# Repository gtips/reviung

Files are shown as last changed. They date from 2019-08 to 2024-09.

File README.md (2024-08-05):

# REVIUNG

## [REVIUNG41](https://github.com/gtips/reviung/tree/master/reviung41)  
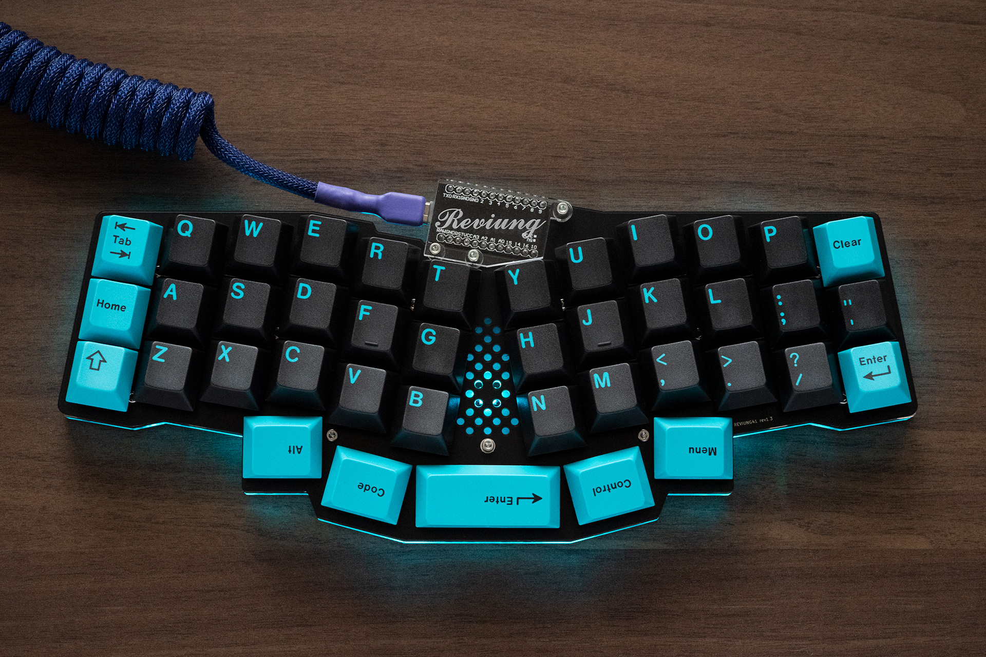
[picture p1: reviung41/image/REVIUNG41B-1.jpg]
REVIUNG41
  

The REVIUNG41 is 41-key column staggered keyboard.  

[Firmware](https://github.com/qmk/qmk_firmware/tree/master/keyboards/reviung/reviung41)  
[Build guide](https://reviung.com/build-guide/391/)  
  
<br>
<br>
  
## REVIUNG39 Mk-II, REVIUNG39 and REVIUNG39S  
The REVIUNG39 is 39-key column staggered keyboard.

Soldering is divided into through-hole mounting version and surface mounting (SMD) version so that the soldering difficulty can be selected.  

- REVIUNG39 Mk-II and REVIUNG39 is regular version (SMD)  
- REVIUNG39S is simple version (through-hole)  

[REVIUNG39 Mk-II ](https://github.com/gtips/reviung/tree/master/reviung39Mk-II)   
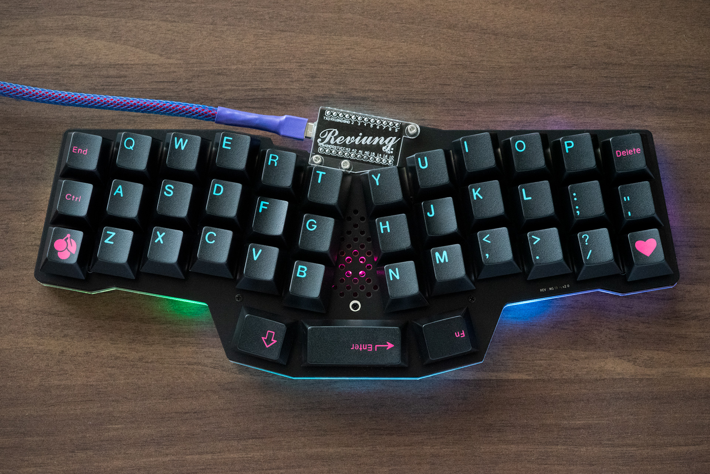
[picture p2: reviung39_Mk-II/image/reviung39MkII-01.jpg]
REVIUNG39 Mk-II
  

<br>

[REVIUNG39](https://github.com/gtips/reviung/tree/master/reviung39)  
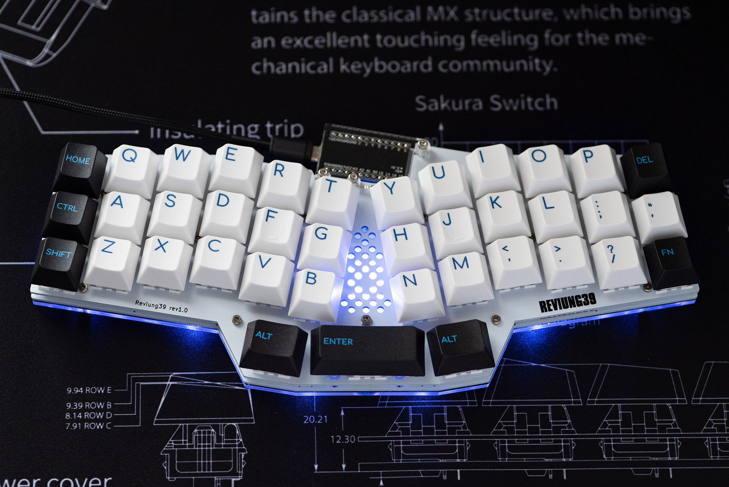
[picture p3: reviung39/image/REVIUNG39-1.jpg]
REVIUNG39
  

<br>

[REVIUNG39 Build guide](https://reviung.com/build-guide/108/)  
[Firmware](https://github.com/qmk/qmk_firmware/tree/master/keyboards/reviung/reviung39)
  
<br>
<br>

## REVIUNG34  
The REVIUNG34 is 34-key (or33-key) column staggered keyboard.  
  
[REVIUNG34](https://github.com/gtips/reviung/tree/master/reviung34)  
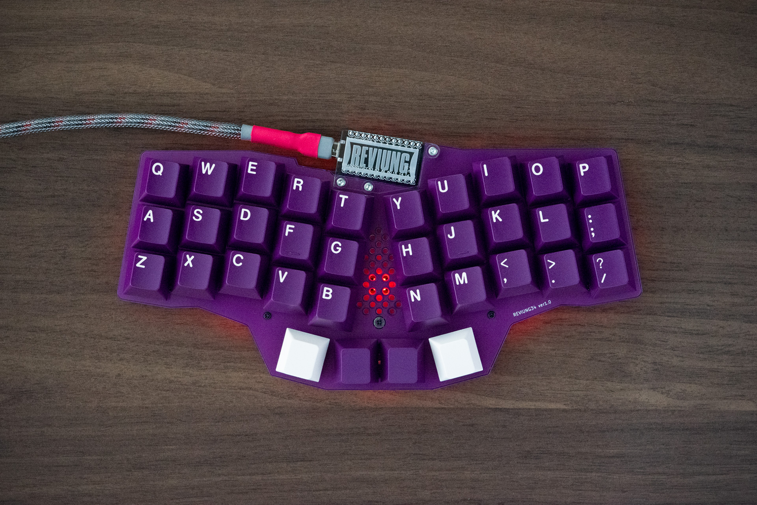
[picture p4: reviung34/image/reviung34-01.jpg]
REVIUNG34
  

<br>

[REVIUNG34 Build guide](https://reviung.com/build-guide/724/)  
[Firmware](https://github.com/qmk/qmk_firmware/tree/master/keyboards/reviung/reviung34)
  
<br>
<br>

## REVIUNG5  
The REVIUNG5 is 5-key (or 4-key + Rotary Encoder) macropad.  
  
[REVIUNG5](https://github.com/gtips/reviung/tree/master/reviung5)  
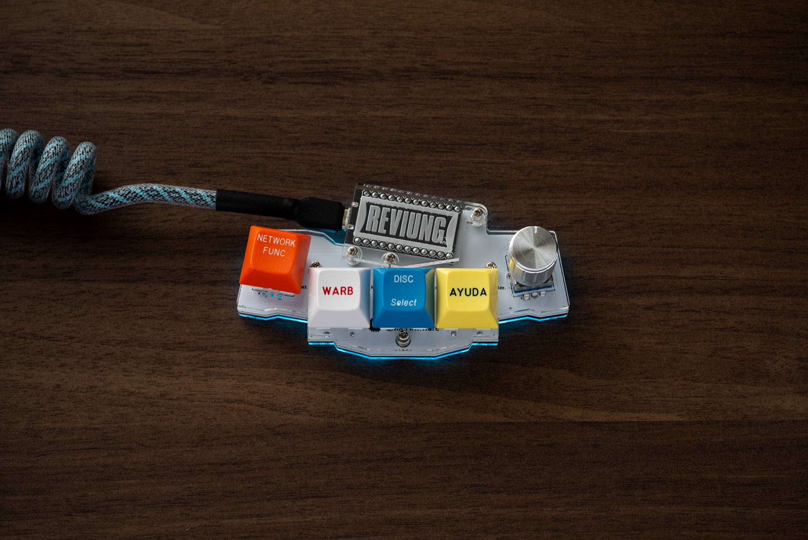
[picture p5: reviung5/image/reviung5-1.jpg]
REVIUNG5
  

<br>

[REVIUNG5 Build guide](https://reviung.com/build-guide/)  
[Firmware](https://github.com/qmk/qmk_firmware/tree/master/keyboards/reviung/reviung5)
  
<br>
<br>
  
## REVIUNG34 SPLIT Mk-II and REVIUNG34 SPLIT  

The REVIUNG34 is 34-key split ortholinear keyboard.  
(REVIUNG34 SPLIT Mk-II is 34-key or 33-key)  
Use a LAN cable to connect the left and right keyboards.  
  
[REVIUNG34 Mk-II](https://github.com/gtips/reviung/tree/master/reviung34split_Mk-II)  
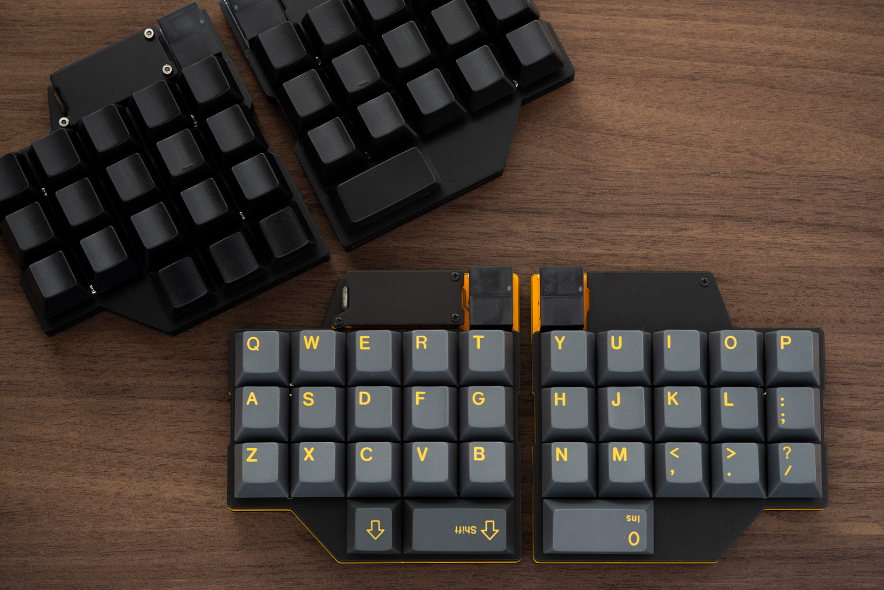
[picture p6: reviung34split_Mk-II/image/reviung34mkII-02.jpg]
REVIUNG34 Mk-II
  
  
<br>
  
[REVIUNG34 SPLIT](https://github.com/gtips/reviung/tree/master/reviung34split)  
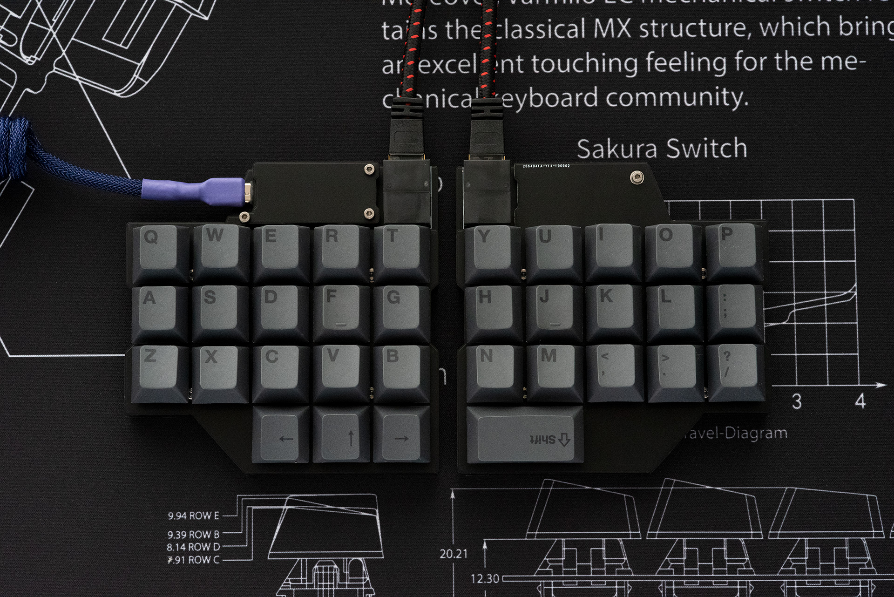
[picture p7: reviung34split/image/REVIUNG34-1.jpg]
REVIUNG34 SPLIT
  
  
[Firmware](https://github.com/qmk/qmk_firmware/tree/master/keyboards/reviung/reviung34)  
[REVIUNG34 SPLIT Build guide](https://reviung.com/build-guide/278/)  

<br>
<br>

## [REVIUNG33](https://github.com/gtips/reviung/tree/master/reviung33)  
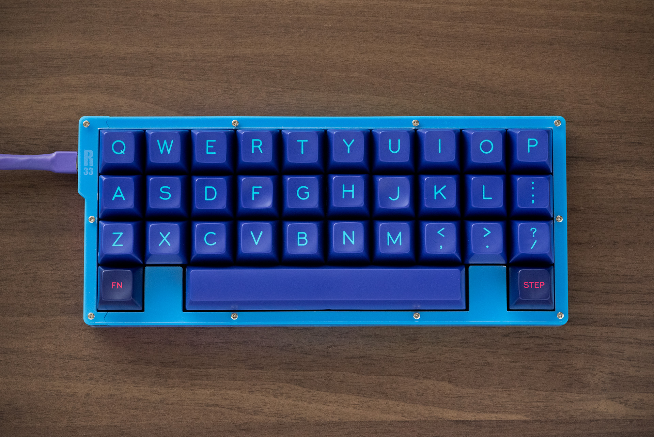
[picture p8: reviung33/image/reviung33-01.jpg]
REVIUNG33
  

The REVIUNG33 is 33-key ortholinear keyboard.  

[Firmware](https://github.com/qmk/qmk_firmware/tree/master/keyboards/reviung/reviung33)  

<br>
<br>

## [REVIUNG53](https://github.com/gtips/reviung/tree/master/reviung53)  
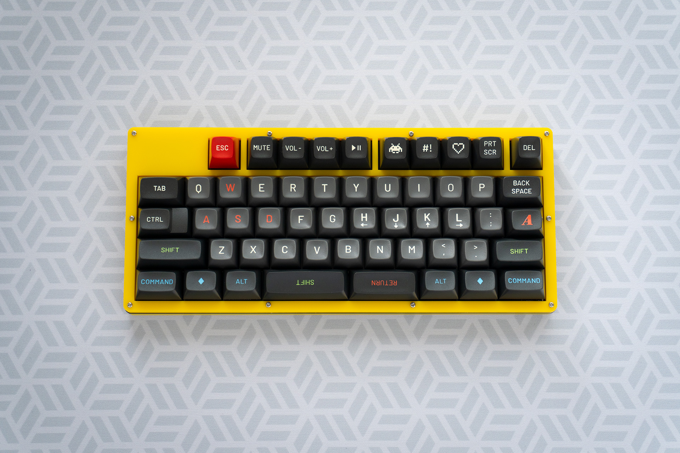
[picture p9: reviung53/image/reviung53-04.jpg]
REVIUNG53
  

The REVIUNG53 is 53-key keyboard.  

[Firmware](https://github.com/qmk/qmk_firmware/tree/master/keyboards/reviung/reviung53)  

<br>
<br>

## [REVIUNG61](https://github.com/gtips/reviung/tree/master/reviung61)  
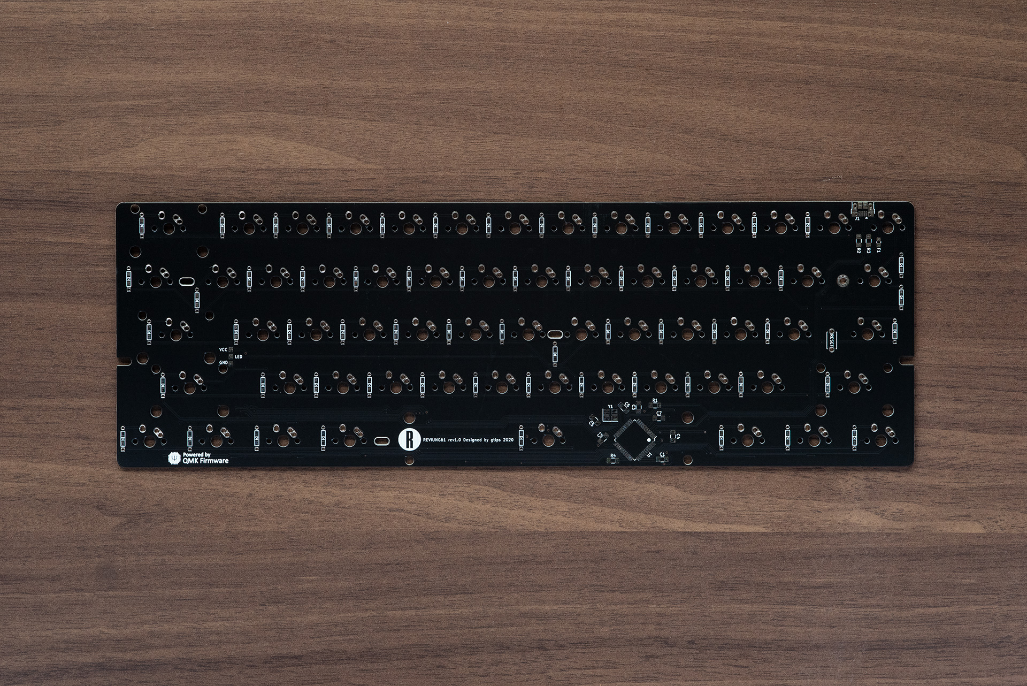
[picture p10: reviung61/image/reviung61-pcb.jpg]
REVIUNG61
  

Standard ANSI 60% keyboard. And compatible with MX and ALPS.  

[Firmware](https://github.com/qmk/qmk_firmware/tree/master/keyboards/reviung/reviung61)  

<br>
<br>

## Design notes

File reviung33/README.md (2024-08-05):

# REVIUNG33  
REVIUNG33  

The REVIUNG33 is 33-key ortholinear keyboard.  

## PCB Parts list  

| Qnty | Ref | Value | Description |
| --- | --- | --- | --- |
| 1 | U1 | ATmega32U4-AU | ATmega32U4-AU |
| 1 | Y1 | 16MHz | Crystal: SMD 3225 4Pin |
| 2 | C1, C2 | 22pF | Capacitor SMD: 1206 3216 |
| 1 | C3 | 1uF | Capacitor SMD: 1206 3216 |
| 3 | C4, C5, C6 | 0.1uF | Capacitor SMD: 1206 3216 |
| 1 | C7 | 10uF | Capacitor SMD: 1206 3216 |
| 33 | D1 - D33 | 1N4148 | Diode: 1N4148W SMD |
| 1 | F1 | 500mA | Fuse: 0805 2012 |
| 1 | J1 | MOLEX 47642-0001 | Connector USB: MOLEX 47642-0001 |
| 5 | WS2812B | WS2812B | RGB LED: WS2812B
| 2 | R1, R2 | 22 ohm | Resistor SMD:1206 3216 |
| 2 | R3, R4 | 10k ohm | Resistor SMD:1206 3216 |
| 1 | RESET1 | Tactile Switche | Tactile Switche Omron Electronics B3U-1000P |
| 33 | SW1 - SW33 | MX Hotswap Sockets | Kailh MX Hotswap Sockets |
| 32 | SW1 - SW31, SW33 | MX Switche | 1U |
| 1 | SW32 | MX Switche | 6.25U |

## Parts list  

| Qnty | Parts |
| --- | --- |
| 1 | PCB |
| 1 | Top plate [PCB]  |
| 1 | Acrylic frame (over top)  |
| 1 | Acrylic frame (top)  |
| 1 | Acrylic frame (middle) |
| 1 | Acrylic frame (bottom) |
| 1 | Acrylic plate (bottom) |
| 1 | Stabilizer 6.25U |
| 10 | Spacer 7mm |
| 10 | M2 screw 4mm |
| 10 | M2 screw  10mm |
| 6 | Rubber feet  |
| 33 | MX compatible switch | 
| 32 | Keycap (1U) | 
| 1 | Keycap (6.25U) | 
  
[Firmware](https://github.com/qmk/qmk_firmware/tree/master/keyboards/reviung/reviung33)  
[Build guide](https://reviung.com/)  
  
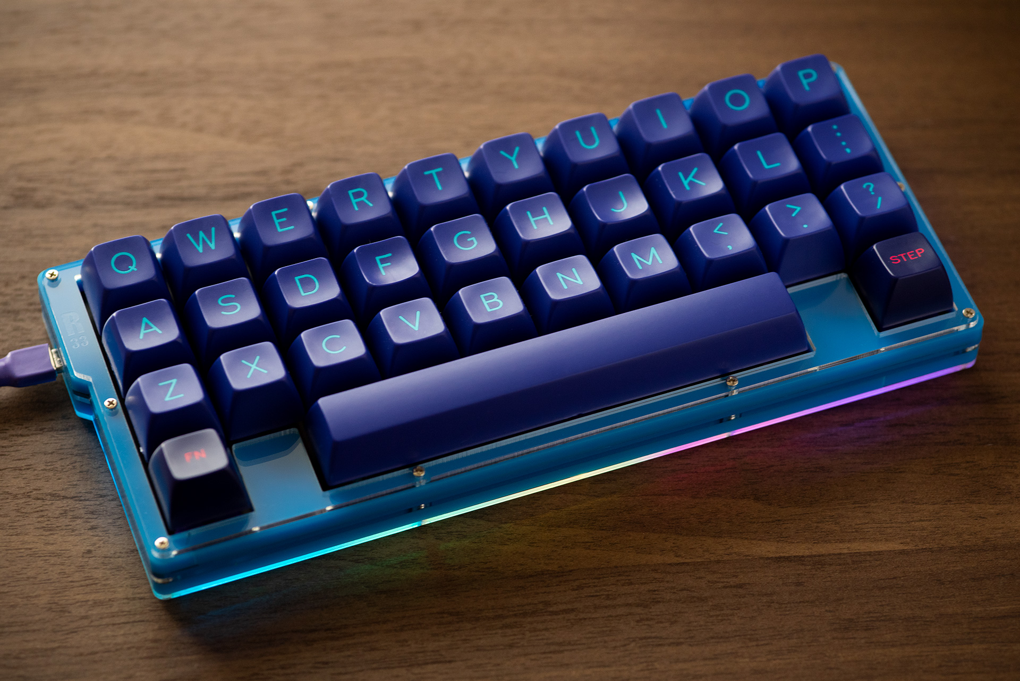
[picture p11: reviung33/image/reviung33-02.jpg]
REVIUNG33
  
  
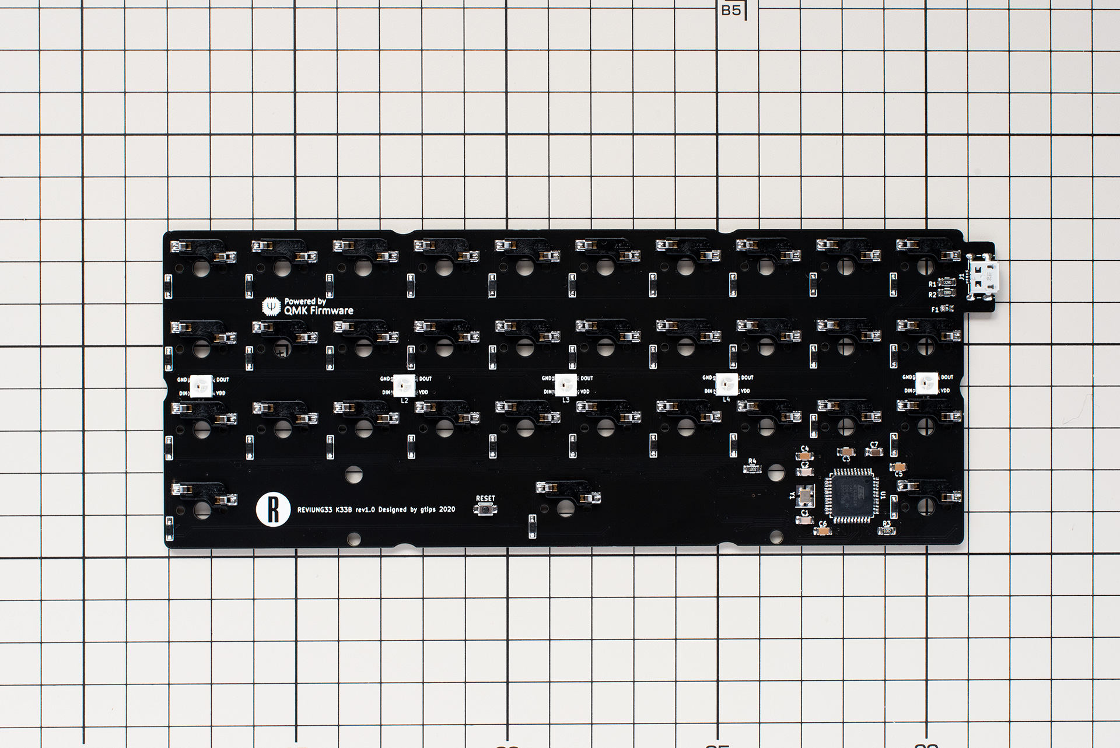
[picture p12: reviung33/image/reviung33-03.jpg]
REVIUNG33


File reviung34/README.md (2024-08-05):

# REVIUNG34  
REVIUNG34  
  
33-key
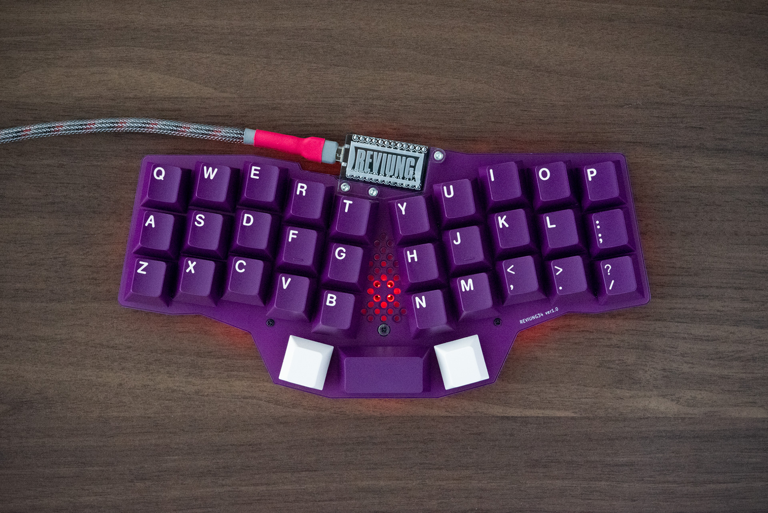
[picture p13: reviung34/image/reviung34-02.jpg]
REVIUNG34
  
  
The REVIUNG34 is 34-key (or 33-key) column staggered keyboard.  

## Parts list  

| Qnty | Parts | Description |
| --- | --- | --- |
| 1 | PCB | Main PCB |  
| 1 | Top plate [PCB]  |  |
| 1 | Silicon sheet | option |
| 1 | Middle acrylic plate (top)  |  option |
| 1 | Middle acrylic plate (bottom)  | option |
| 1 | Bottom plate |  |
| 1 | ProMicro cover plate | option |
| 3 | Acrylic spacer |  for Pro Micro cover |
| 11 | Spacer | for body |
| 22 | M2 screw 4mm |  for body |  
| 3 | M2 screw 10mm |  for Pro Micro cover |
| 3 | M2 nut |  for Pro Micro cover |
| 6 | Rubber feet |  |
| 34 | Diode [1N4148 SMD]  |  |
| 1 | Tact switch |  RESET switch |
| 9 | LED [WS2812B]  | option |
| 1 | 2U Stabilizer  | 33-key |
| - | - | - |
| 1 | ProMicro |  |
| 2 | Con through  | or spring pin header 12P |
| 34 (or 33) | MX compatible key switch |  |  
| 34 (or 32) | MX compatible keycap (1U) |  | 
| 0 (or 1) | MX compatible Keycap (2U) |  |
| 1 | MicroUSB cable |  |
  
[Firmware](https://github.com/qmk/qmk_firmware/tree/master/keyboards/reviung/reviung34)  
[Build guide](https://reviung.com/build-guide/)  
  
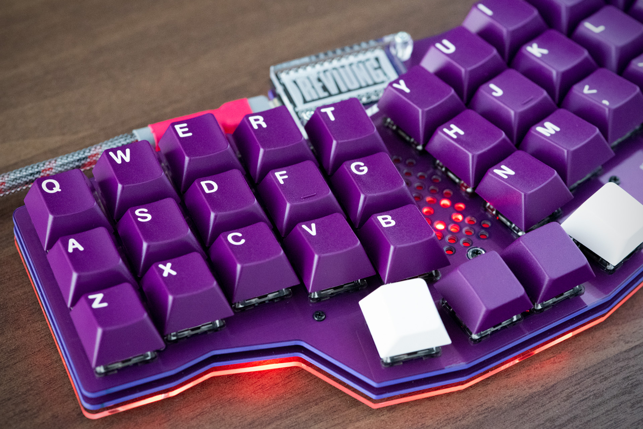
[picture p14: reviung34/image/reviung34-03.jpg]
REVIUNG34
  

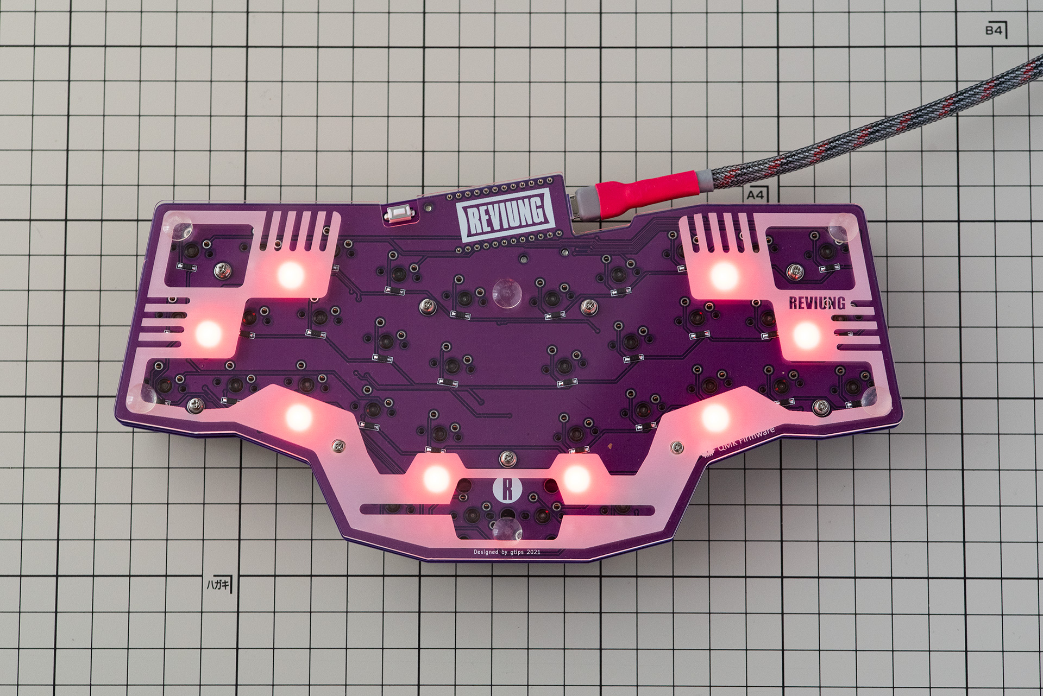
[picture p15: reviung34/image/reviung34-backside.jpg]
REVIUNG34


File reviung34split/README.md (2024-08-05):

# REVIUNG34 SPLIT  
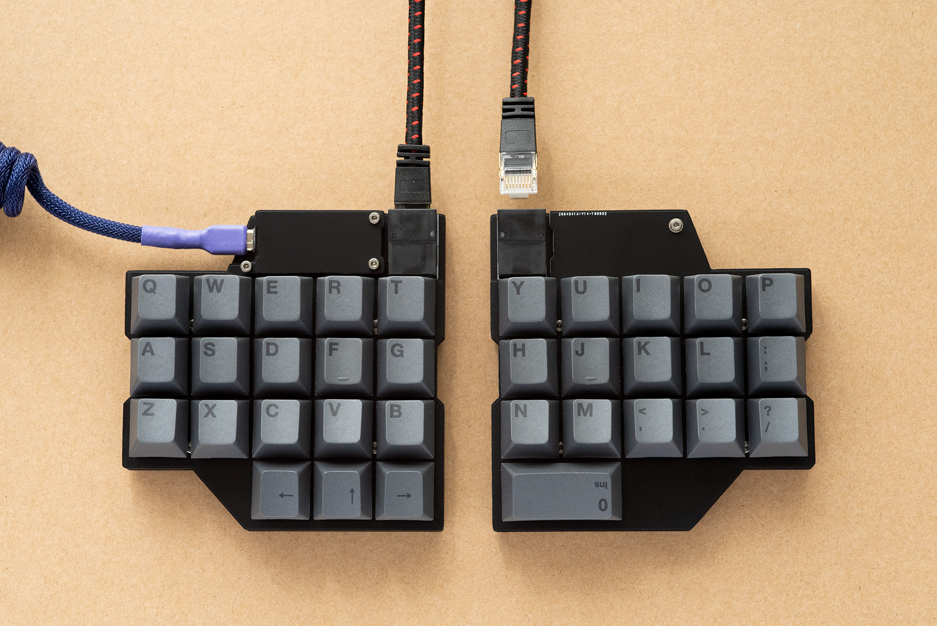
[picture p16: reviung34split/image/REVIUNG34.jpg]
REVIUNG34 SPLIT
  

The REVIUNG34 SPLIT is 34-key split ortholinear keyboard.  
Use a LAN cable to connect the left and right keyboards.  

[Firmware](https://github.com/qmk/qmk_firmware/tree/master/keyboards/reviung/reviung34)  
[Build guide](https://reviung.com/build-guide/278/)  

#### Parts list  
1  PCB left  
1  PCB right  
1  left Top plate (PCB with switch mounting holes)  
1  right Top plate (PCB with switch mounting hole)  
2  Bottom plate (left and right common PCB)  
1  ProMicro protective plate (Comes with left top plate. Cut and use.)  
34 Diode (1N4148)  
34 PCB socket for switches  
1  Tact switch (reset button)  
2  Ethernet connector (DS1128-05-S8B8P)  
1  Stabilizer (2u)  
12 M2 spacer 7mm (metal spacer)  
24 M2 screw 5mm  
8  Rubber feet for bottom plate  
<br/>
1  ProMicro  
34 Key switch (MX compatible)  
33 Keycap (1U, MX compatible)  
1  Keycap (2U, MX compatible)  
1  MicroUSB cable  
1  Ethernet cable (Use a cable shorter than 1m)  

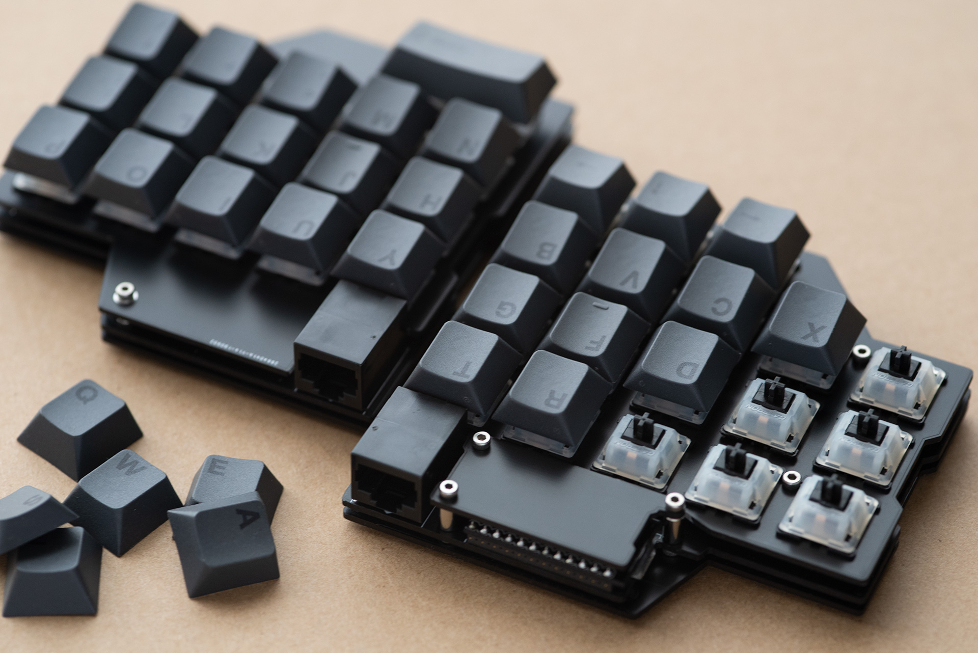
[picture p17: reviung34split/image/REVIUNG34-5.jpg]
REVIUNG34 SPLIT
  

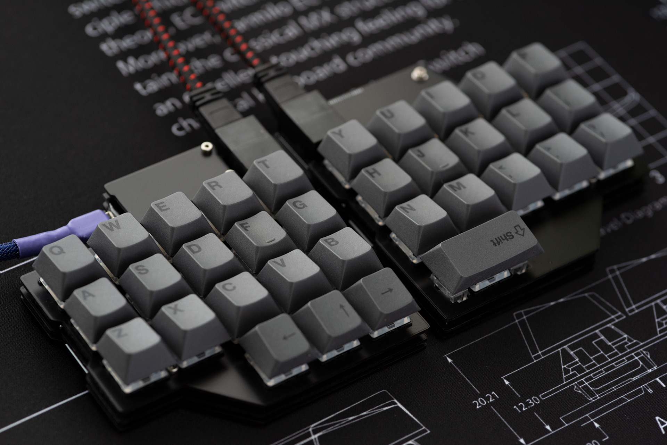
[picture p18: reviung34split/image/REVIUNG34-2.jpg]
REVIUNG34 SPLIT


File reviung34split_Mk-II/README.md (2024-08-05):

# REVIUNG34 Mk-II  
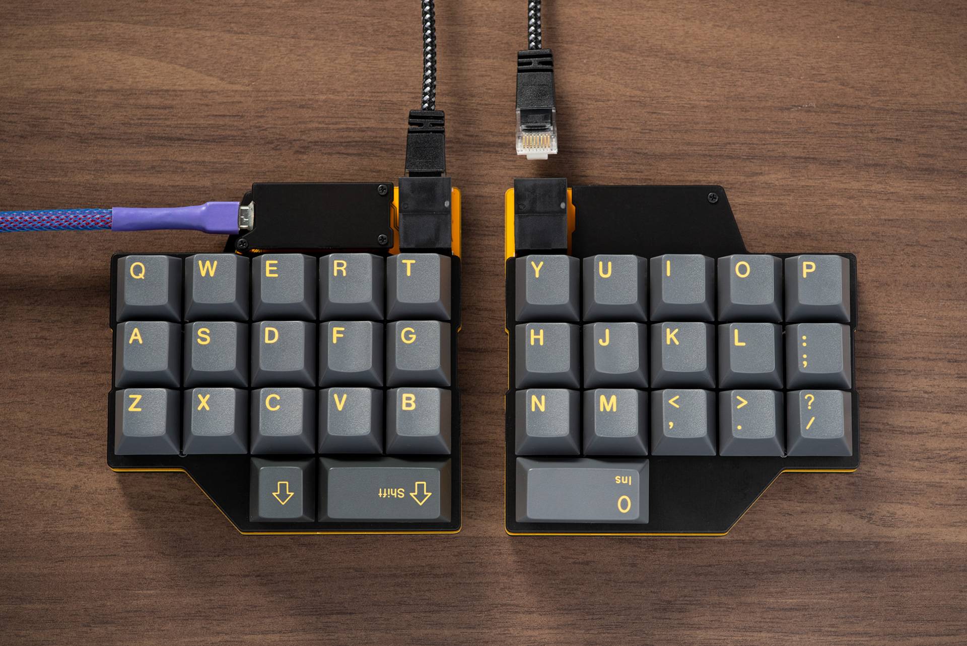
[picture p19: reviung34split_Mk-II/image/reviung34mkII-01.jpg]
REVIUNG34 Mk-II
  

The REVIUNG34 Mk-II is 34-key split ortholinear keyboard.  
Use a LAN cable to connect the left and right keyboards.  
Choose "1u key x3" or "1u and 2u key" for the left thumb key.

## Parts list  

| Qnty | Parts | Description |
| --- | --- | --- |
| 1 | PCB | Main PCB |  
| 1 | PCB | Top plate  |
| 1 | PCB | Bottom plate |
| 34 | Diode | 1N4148 |
| 2 | Ethernet connector |  DS1128-05-S8B8P |
| 1 | Tact switch |  RESET switch |
| 12 | Spacer | 7mm |
| 24 | M2 screw | 4mm |  
| 8 | Rubber feet |  |
| - | - | - |
| 1 | ProMicro |  |
| 2 | Con through  | or spring pin header 12P |
| 1-2 | Stabilizer  | 2U |
| 33-34 | MX compatible key switch |  |  
| 32-33 | MX compatible keycap (1U) |  | 
| 1-2 | MX compatible Keycap (2U) |  |
| 1 | MicroUSB cable |  |
| 1 | Ethernet cable |  |
  
[Firmware](https://github.com/qmk/qmk_firmware/tree/master/keyboards/reviung/reviung34)  
[Build guide](https://reviung.com/build-guide/656/)  
  
REVIUNG34 Mk-II  
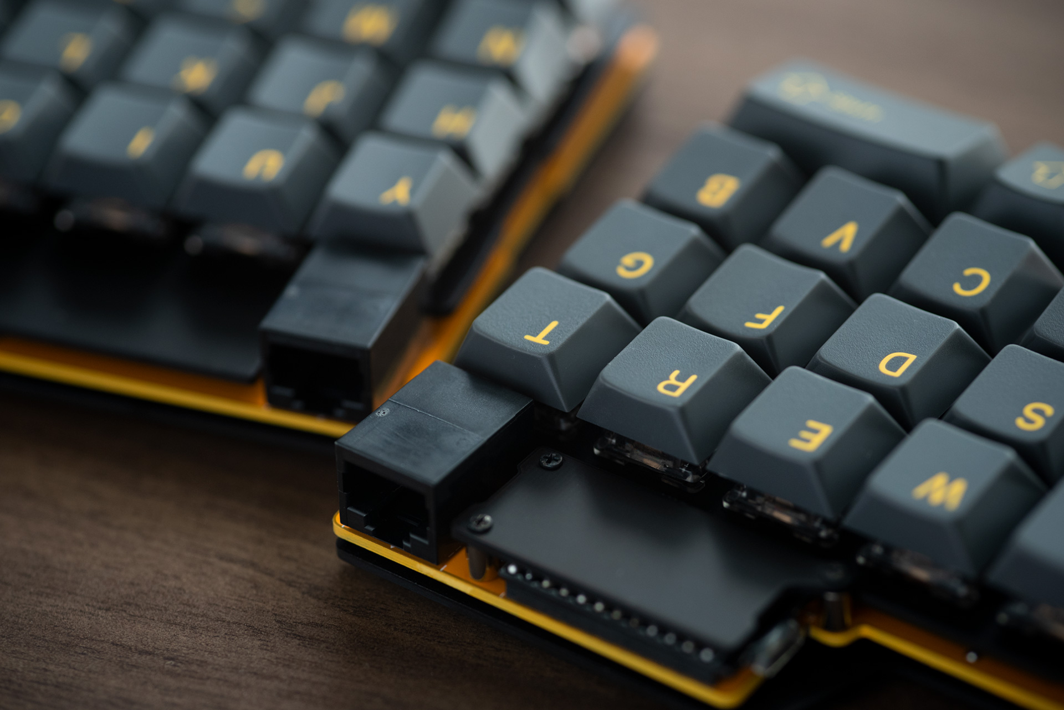
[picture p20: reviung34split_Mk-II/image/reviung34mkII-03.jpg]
REVIUNG34 Mk-II


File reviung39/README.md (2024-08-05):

# REVIUNG39  
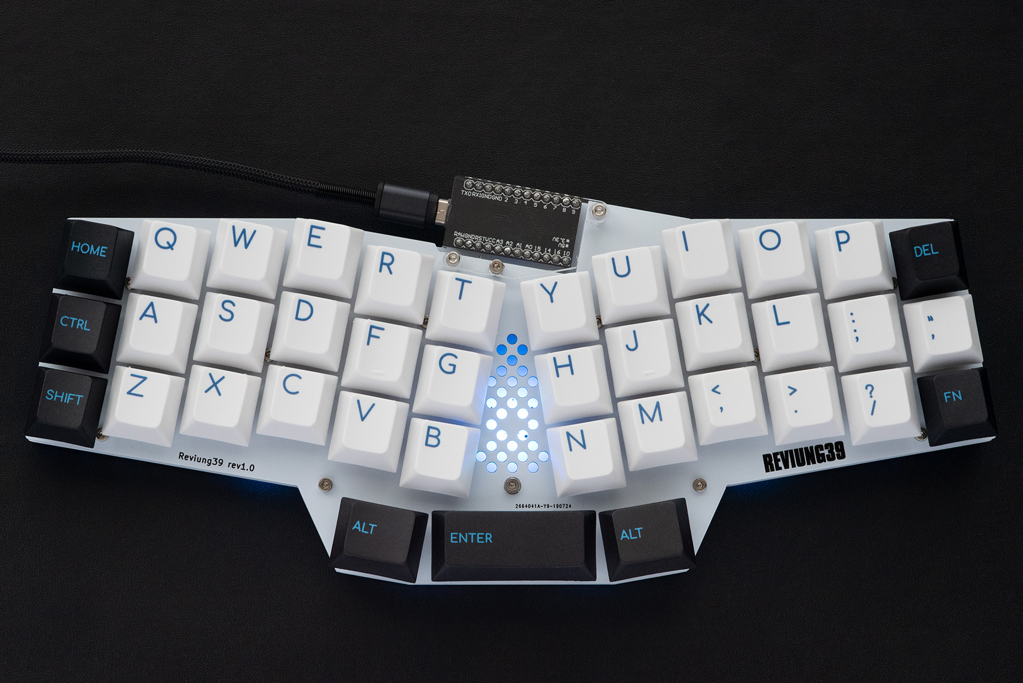
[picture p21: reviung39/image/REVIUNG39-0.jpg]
REVIUNG39
  

The REVIUNG39 is 39-key column staggered keyboard.  

## Parts list  

PCB --- 1 piece  
Top plate [PCB] --- 1  
Middle acrylic plate (top) --- 1  
Middle acrylic plate (bottom) --- 1  
Bottom plate --- 1 piece  
ProMicro protection plate --- 1  
Acrylic spacer --- 2 pieces  
Spacer --- 11 pieces  
M2 screw 4mm --- 22 pcs  
M2 screw 10mm --- 3 pcs  
M2 nut --- 3 pcs  
Rubber feet --- 6 pieces  
Diode [1N4148 SMD] --- 39 pieces  
PCB socket for switch --- 39 pcs  
Tact switch --- 1 piece  
LED [SK6812MINI] --- 11 pieces  
Stabilizer --- 1 piece  

ProMicro --- 1  
MX compatible key switch --- 39  
MX compatible keycap (1U) --- 36  
Keycap (2.25U or 2U) --- 1  
Keycap (1.25U or 1U) --- 2  
MicroUSB cable --- 1  
  
[Firmware](https://github.com/qmk/qmk_firmware/tree/master/keyboards/reviung/reviung39)  
[Build guide](https://reviung.com/build-guide/108/)  
  
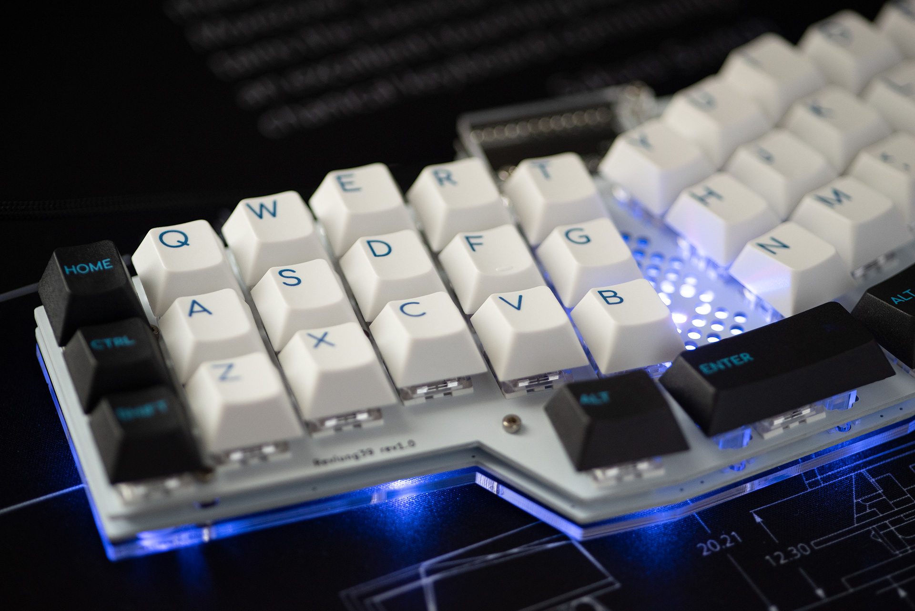
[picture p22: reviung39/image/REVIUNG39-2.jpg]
REVIUNG39
  
  
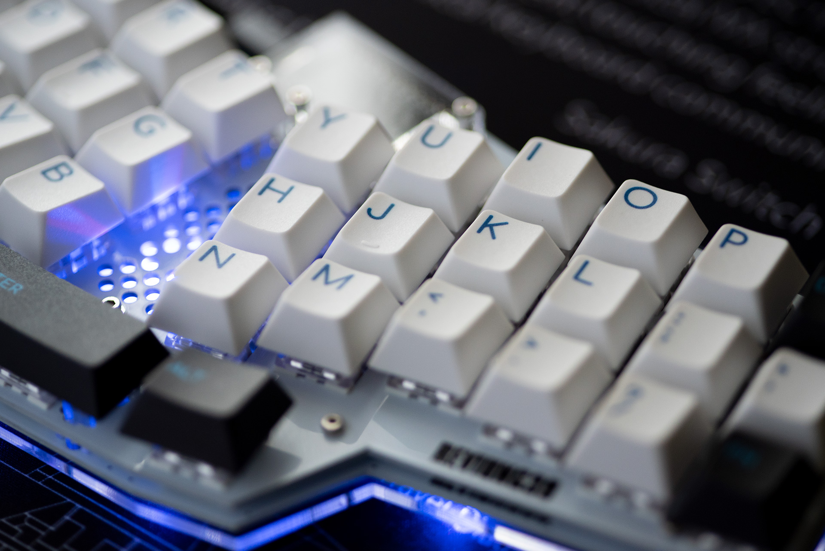
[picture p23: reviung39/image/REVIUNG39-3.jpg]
REVIUNG39


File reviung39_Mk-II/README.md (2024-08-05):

# REVIUNG39 Mk-II  
REVIUNG39 Mk-II  

The REVIUNG39 Mk-II is 39-key column staggered keyboard.  

## Parts list  

| Qnty | Parts | Description |
| --- | --- | --- |
| 1 | PCB | Main PCB |  
| 1 | Top plate [PCB]  |  |
| 1 | Silicon sheet | option |
| 1 | Middle acrylic plate (top)  |  option |
| 1 | Middle acrylic plate (bottom)  | option |
| 1 | Bottom plate |  |
| 4 | ProMicro cover plate | option |
| 3 | Acrylic spacer |  for Pro Micro cover |
| 11 | Spacer | for body |
| 22 | M2 screw 4mm |  for body |  
| 3 | M2 screw 10mm |  for Pro Micro cover |
| 3 | M2 nut |  for Pro Micro cover |
| 6 | Rubber feet |  |
| 39 | Diode [1N4148 SMD]  |  |
| 39 | MX Hotswap Sockets | Kailh MX Hotswap Sockets |
| 1 | Tact switch |  RESET switch |
| 11 | LED [WS2812B]  | option |
| 1 | Stabilizer  | 2U |
| - | - | - |
| 1 | ProMicro |  |
| 2 | Con through  | or spring pin header 12P |
| 39 | MX compatible key switch |  |  
| 36 | MX compatible keycap (1U) |  | 
| 1 | Keycap (2.25U or 2U) |  |
| 2 | Keycap (1.25U or 1U) |  |
| 1 | MicroUSB cable |  |
  
[Firmware](https://github.com/qmk/qmk_firmware/tree/master/keyboards/reviung/reviung39)  
[Build guide](https://reviung.com/build-guide/583/)  
  
REVIUNG39 Mk-II

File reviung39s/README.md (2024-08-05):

# REVIUNG39S  
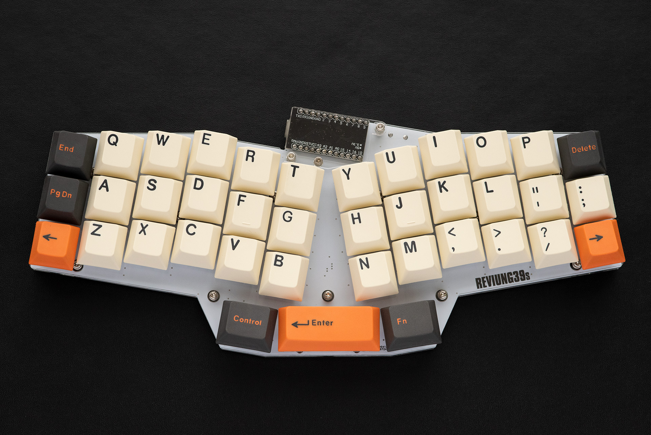
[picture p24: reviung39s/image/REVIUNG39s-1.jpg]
REVIUNG39S
  

The REVIUNG39S is 39-key column staggered keyboard.  
Solder through hole mounting version.  

## Parts list  

PCB --- 1 piece  
Top plate [acrylic] --- 1 sheet  
Bottom plate --- 1 piece  
ProMicro protection plate --- 1  
Acrylic spacer --- 2 pieces  
Spacer --- 11 pieces  
M2 screw 5mm --- 23 pcs  
M2 screw 10mm --- 2 pcs  
M2 nut --- 3 pcs  
Rubber feet --- 5 pcs  
Diode [1N4148] --- 39 pieces  
Tact switch --- 1 piece  
Stabilizer --- 1 piece  

ProMicro --- 1  
MX compatible key switch --- 39  
MX compatible keycap (1U) --- 36  
Keycap (2.25U or 2U) --- 1  
Keycap (1.25U or 1U) --- 2  
MicroUSB cable --- 1  

option  
LED Strip(tape) for Underglow (with 6 WS2812B)  
  
[Firmware](https://github.com/qmk/qmk_firmware/tree/master/keyboards/reviung/reviung39)  
[Build guide](https://reviung.com/build-guide/112/)  
  
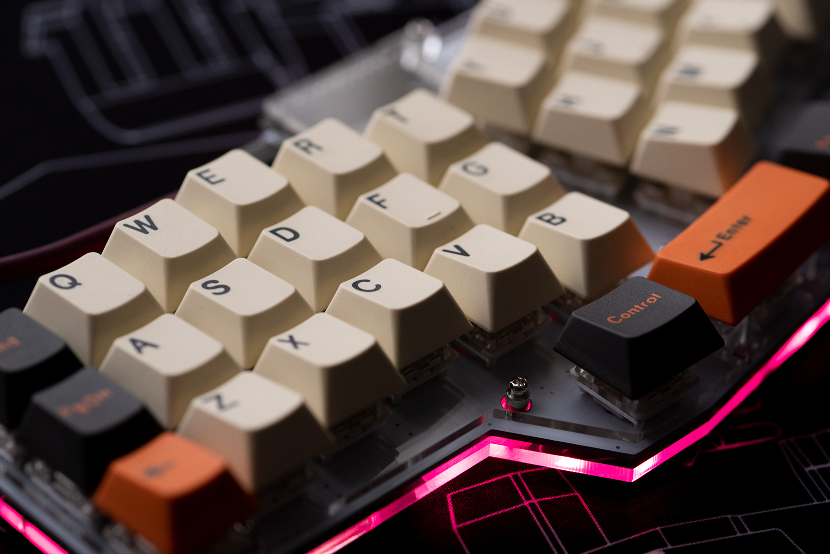
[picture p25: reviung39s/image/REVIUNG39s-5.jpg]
REVIUNG39


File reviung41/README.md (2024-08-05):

# REVIUNG41  
REVIUNG41  

The REVIUNG41 is 41-key column staggered keyboard.  

## Parts list  

PCB --- 1 piece  
Top plate [PCB] --- 1  
Silicon sheet --- 1 sheet  
Middle acrylic plate (top) --- 1  
Middle acrylic plate (bottom) --- 1  
Bottom plate --- 1 piece  
ProMicro protective plate --- 4 types  
Acrylic spacer --- 3 pieces  
Spacer --- 11 pieces  
M2 screw 4mm --- 22 pcs  
M2 screw 10mm --- 3 pcs  
M2 nut --- 3 pcs  
Rubber feet --- 6 pieces  
Diode [1N4148 SMD] --- 41 pieces  
PCB socket for switch --- 41 pcs  
Tact switch --- 1 piece  
LED [WS2812B] --- 11 pieces  
Stabilizer --- 1 piece  

ProMicro --- 1  
Con through (spring pin header 12P) --- 2  
MX compatible key switch --- 41 pcs  
MX compatible keycap (1U) --- 36  
Keycap (2.25U or 2U) --- 1  
Keycap (1.25U or 1U) --- 4  
MicroUSB cable --- 1  
  
[Firmware](https://github.com/qmk/qmk_firmware/tree/master/keyboards/reviung/reviung41)  
[Build guide](https://reviung.com/build-guide/391/)  
  
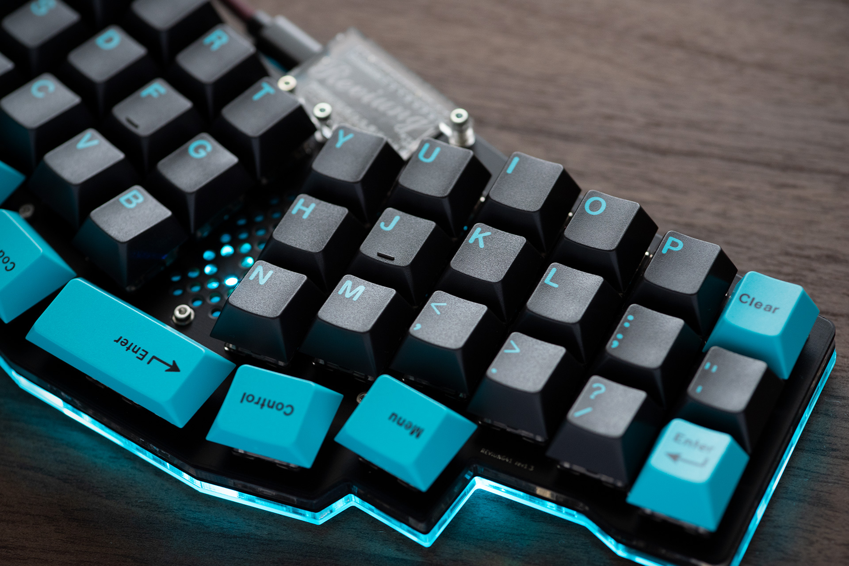
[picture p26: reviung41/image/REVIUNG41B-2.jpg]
REVIUNG41
  
  
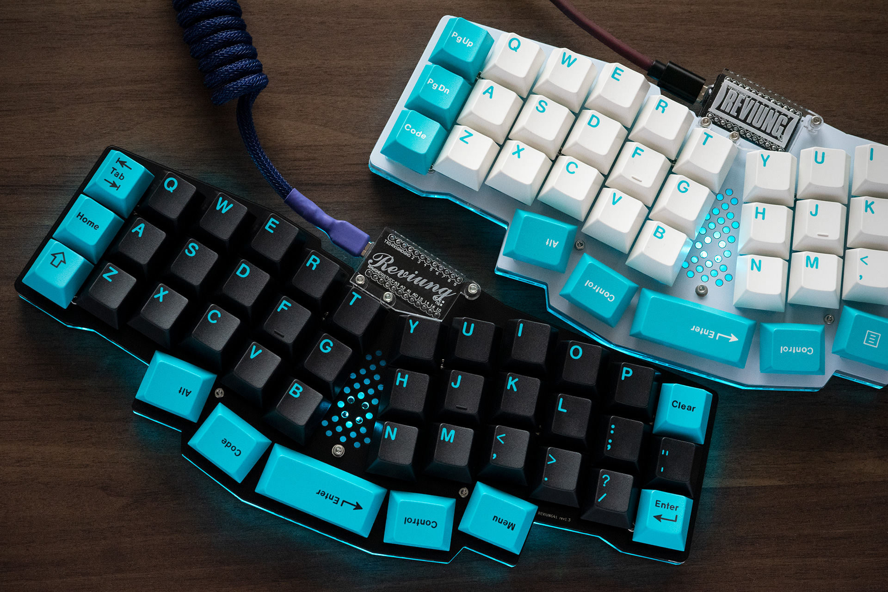
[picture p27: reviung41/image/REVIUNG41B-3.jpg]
REVIUNG41
  
  
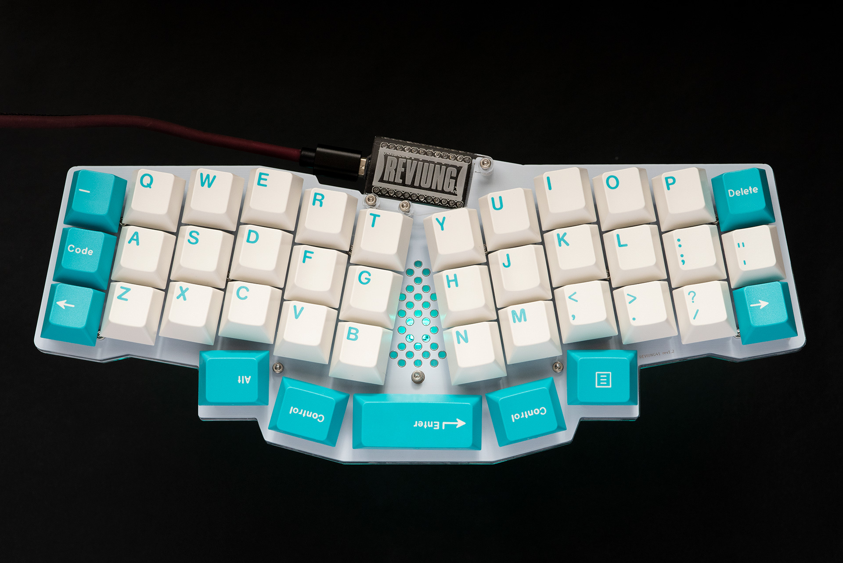
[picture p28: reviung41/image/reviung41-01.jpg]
REVIUNG41
  
  
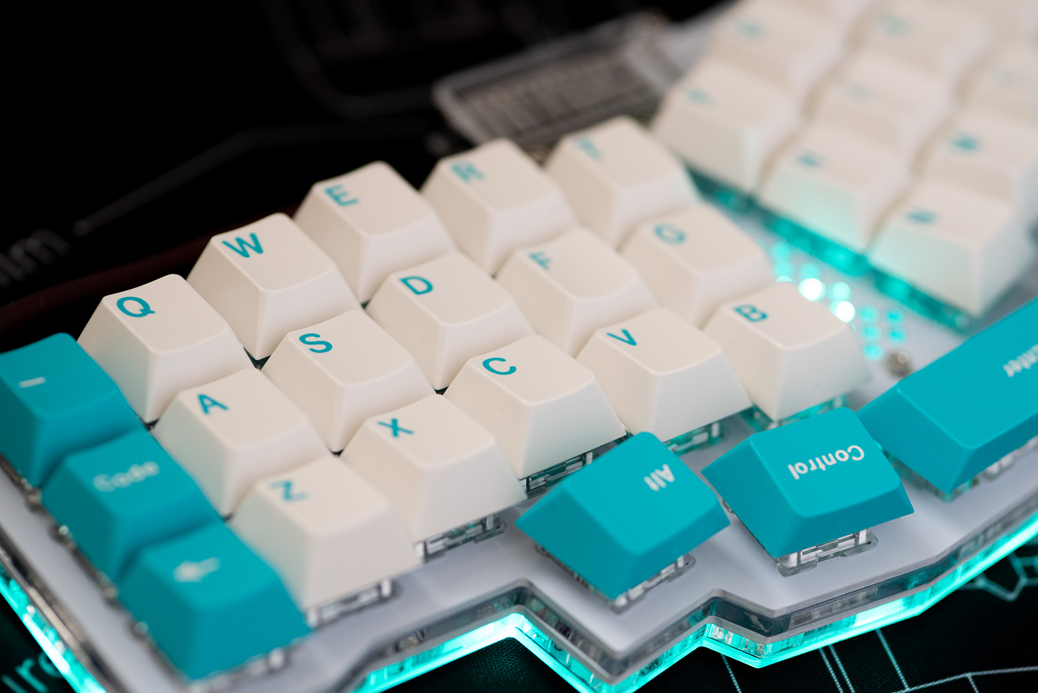
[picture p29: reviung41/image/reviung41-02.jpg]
REVIUNG41
  
  
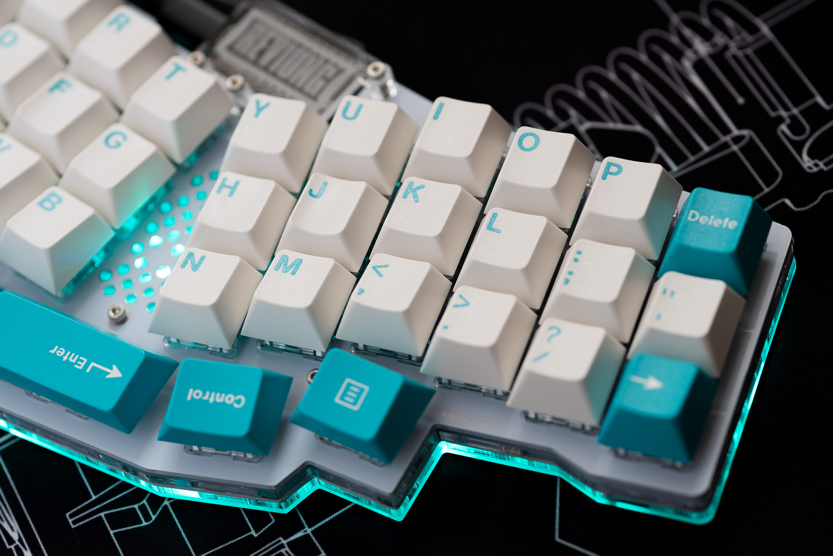
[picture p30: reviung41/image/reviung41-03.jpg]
REVIUNG41


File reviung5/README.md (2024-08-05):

# REVIUNG5  
REVIUNG5  
  
The REVIUNG5 is 5-key (or 4-key + Rotary Encoder) macropad.  

## Parts list  

| Qnty | Parts | Description |
| --- | --- | --- |
| 1 | PCB | Main PCB |  
| 1 | Top plate |  |
| 1 | Bottom plate |  |
| 1 | ProMicro cover plate | option |
| 3 | Acrylic spacer |  for Pro Micro cover |
| 3 | Spacer | for body |
| 6 | M2 screw 4mm |  for body |  
| 3 | M2 screw 8 - 10mm |  for Pro Micro cover |
| 3 | M2 nut |  for Pro Micro cover |
| 4 | Rubber feet |  |
| 5 | Diode [1N4148]  |  |
| 1 | Tact switch |  RESET switch |
| 4 | LED [WS2812B]  | option |
| - | - | - |
| 1 | ProMicro |  |
| 2 | Con through  | or spring pin header 12P |
| 5 (or 4) | MX compatible key switch |  |  
| 5 (or 4) | MX compatible keycap (1U) |  | 
| 1 (or 0) | Rotary Encoder | Alps EC12 series compatible | 
| 1 | MicroUSB cable |  |
  
[Firmware](https://github.com/qmk/qmk_firmware/tree/master/keyboards/reviung/reviung5)  
[Build guide](https://reviung.com/build-guide/)  
  
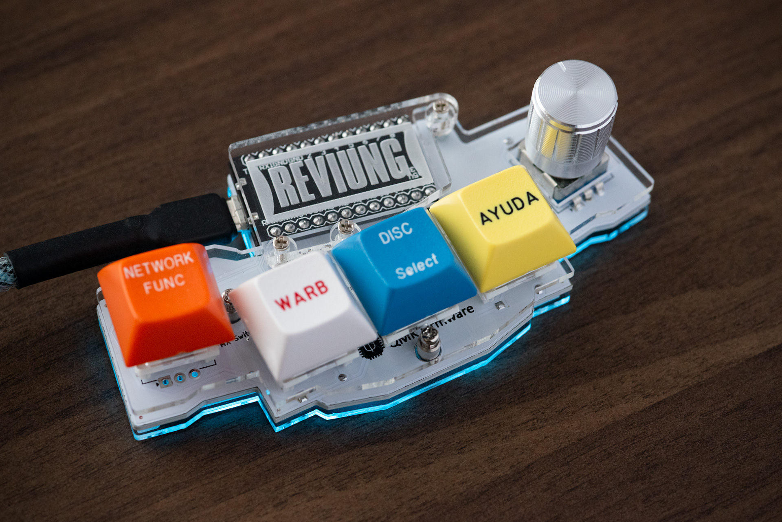
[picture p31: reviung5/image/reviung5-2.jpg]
REVIUNG5


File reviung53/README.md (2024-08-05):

# REVIUNG53  
REVIUNG53  
  
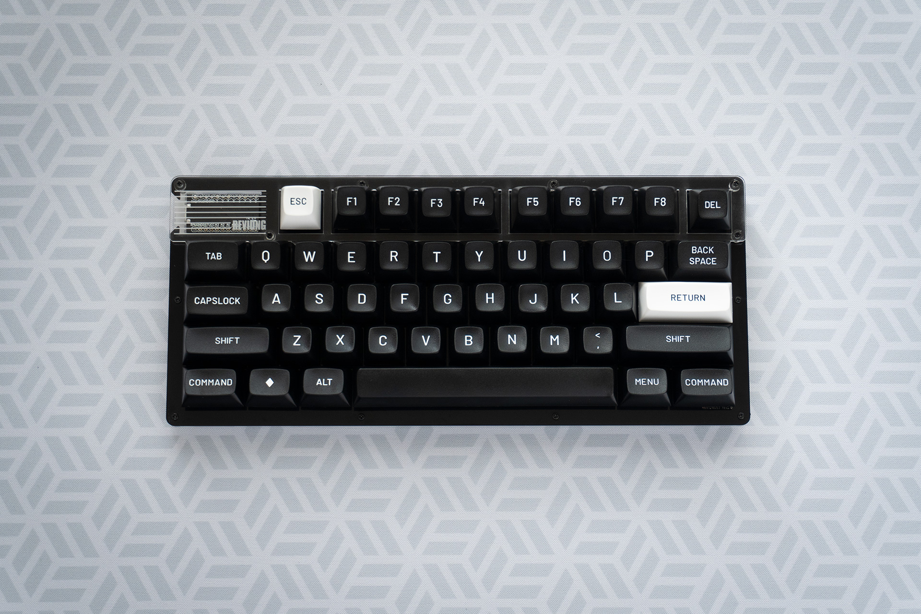
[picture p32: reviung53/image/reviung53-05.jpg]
REVIUNG53
  

The REVIUNG53 is 53-key keyboard.  

## Parts list  

PCB --- 1 piece  
Top plate [PCB] --- 1  
Bottom plate --- 1 piece  
Spacer 7mm --- 10 pieces  
M2 screw 4mm --- 16 pcs  
M2 screw 12mm --- 6 pcs  
M2 nut --- 2 pcs  
Rubber feet --- 6 pieces  
Diode [1N4148 SMD] --- 53 pieces  
PCB socket for switch --- 54 pcs  
Tact switch --- 1 piece  
LED [WS2812B] --- 10 pieces  
Stabilizer --- 2U x 2 , 6.25U x 1 ~  2U x 5  

ProMicro --- 1  
Con through (spring pin header 12P) --- 2  
MX compatible key switch --- 53 pcs ~ 49 (Minimum)  
MX compatible keycapset
MicroUSB cable --- 1  

### Option (Middle acrylic plate ver)
Hi-Pro acrylic frame --- 1  
Middle acrylic plate (top) --- 1  
Middle acrylic plate (bottom) --- 1  
Silicon sheet --- 1 sheet  
M2 screw 12mm --- 10 pcs  
  
[Firmware](https://github.com/qmk/qmk_firmware/tree/master/keyboards/reviung/reviung53)  
[Build guide](https://reviung.com/build-guide/)  
  
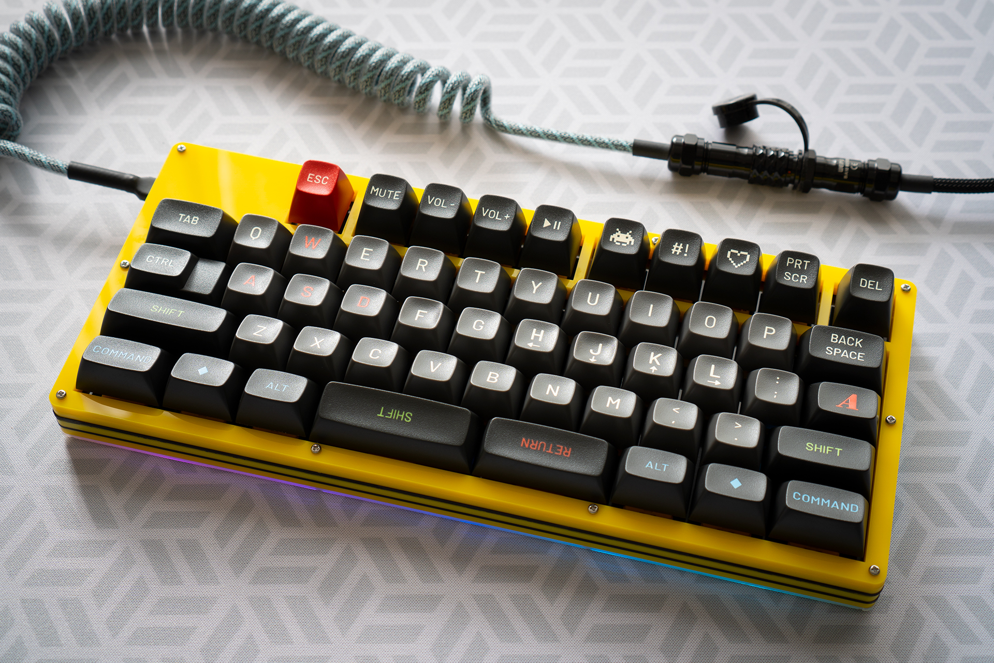
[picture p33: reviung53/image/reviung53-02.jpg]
REVIUNG53
  
  
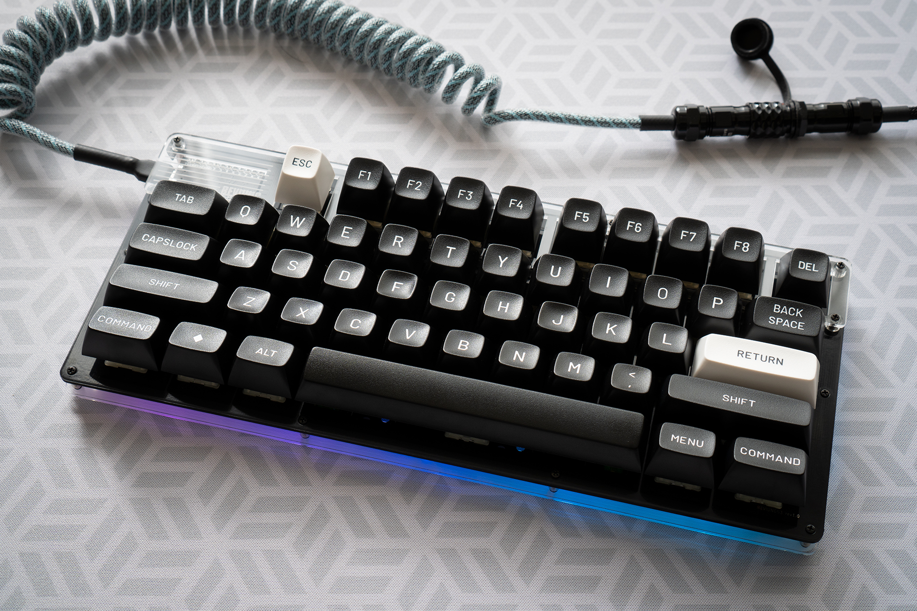
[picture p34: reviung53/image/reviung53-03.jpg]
REVIUNG53
   
   
REVIUNG53

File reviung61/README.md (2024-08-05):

# REVIUNG61  
REVIUNG61  

Standard ANSI 60% keyboard. And compatible with MX and ALPS.  

## Parts list  

| Qnty | Ref | Value | Description |
| --- | --- | --- | --- |
| 1 | U1 | ATmega32U4-AU |
| 1 | Y1 | 16MHz | Crystal: SMD 3225 4Pin |
| 3 | C1, C2, C3 | 0.1uF | Capacitor SMD: 1206 3216 |
| 1 | C4 | 10uF | Capacitor SMD: 1206 3216 |
| 2 | C5, C6 | 22pF | Capacitor SMD: 1206 3216 |
| 1 | C7 | 1uF | Capacitor SMD: 1206 3216 |
| 61 | D1 - D61 | 1N4148 | Diode: 1N4148 |
| 1 | F1 | 500mA | Fuse: 0805 2012 |
| 1 | J1 | 10103594-0001LF | Connector USB: Micro-B Amphenol 10103594-0001LF |
| 2 | R1, R4 | 10k ohm | Resistor SMD:1206 3216 |
| 2 | R2, R3 | 22 ohm | Resistor SMD:1206 3216 |
| 1 | RESET1 | Tactile Switche | Tactile Switche Through Hole 6x3.5mm |
| 56 | SW1 - SW61 | MX or ALPS Switche | 1U |
| 1 | SW14 | MX or ALPS Switche | 2U |
| 2 | SW41, SW42 | MX or ALPS Switche | 2.25U |
| 1 | SW53 | MX or ALPS Switche | 2.75U |
| 1 | SW57 | MX or ALPS Switche | 6.25U |

[Firmware](https://github.com/qmk/qmk_firmware/tree/master/keyboards/reviung/reviung61)

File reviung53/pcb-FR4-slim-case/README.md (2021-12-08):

# PCB (FR4) slim case  
Top plate and bottom plate using PCB (FR4).  
Does not require an acrylic plate.  
It is smaller than the case using acrylic.

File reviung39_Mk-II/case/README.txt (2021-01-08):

Use the step file to load into your favorite 3D modeling software.

Alternatively, you can use the stl file to slice and print directly.

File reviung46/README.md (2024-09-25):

# REVIUNG46  
REVIUNG46  

The REVIUNG46 is 42-46 key keyboard.

[Build guide](https://reviung.com/build-guide/)

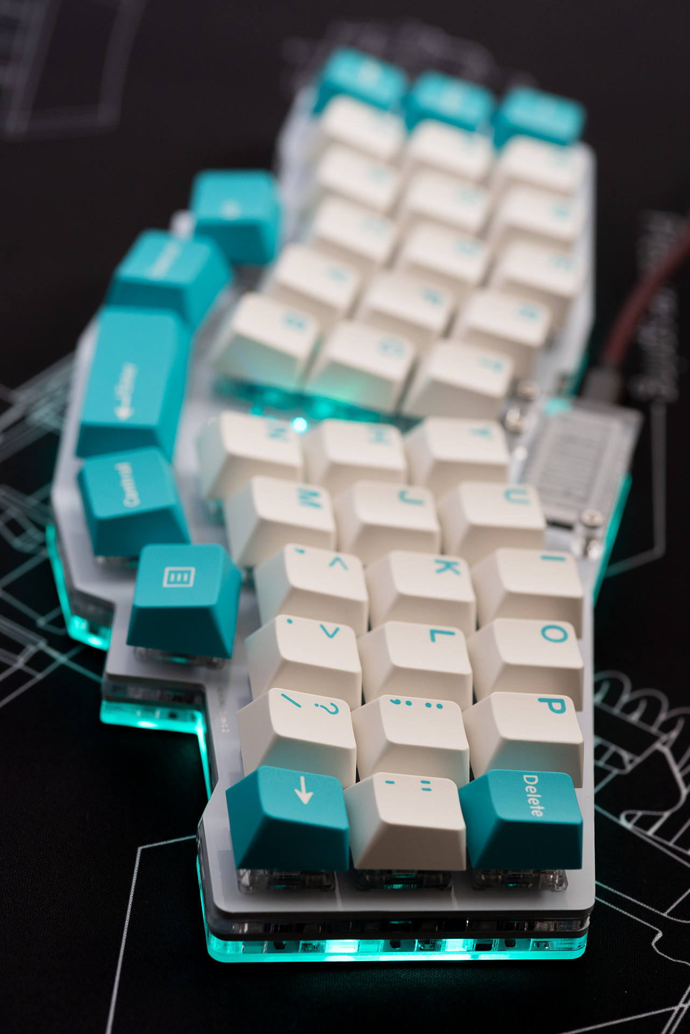
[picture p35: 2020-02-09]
reviung41/image/reviung41-04.jpg

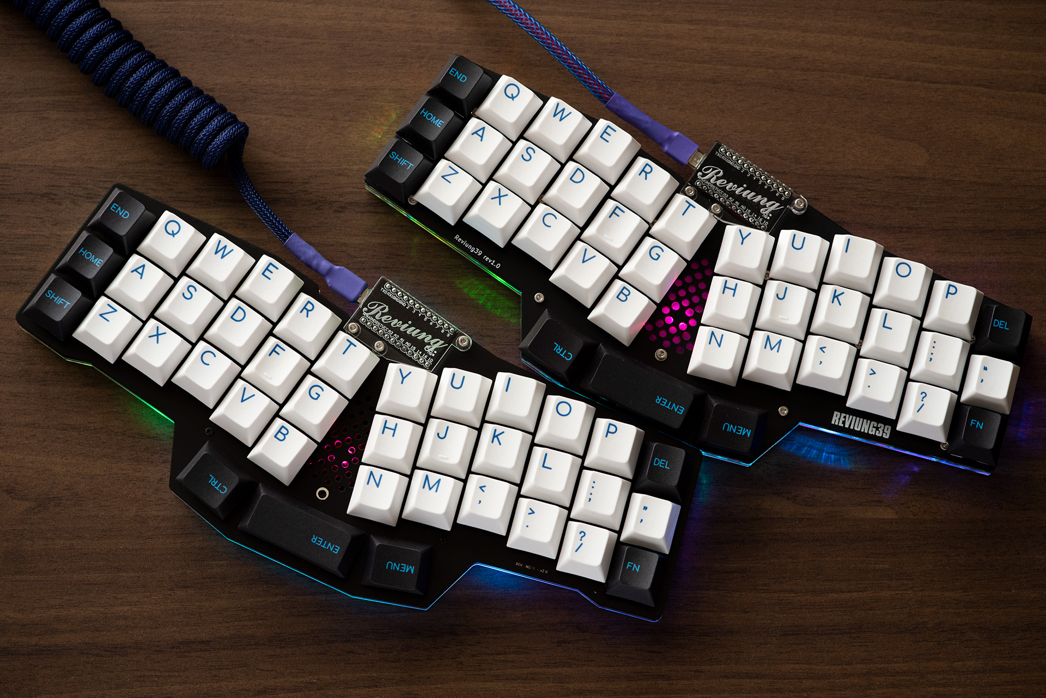
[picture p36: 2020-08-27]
reviung39_Mk-II/image/reviung39MkII-02.jpg

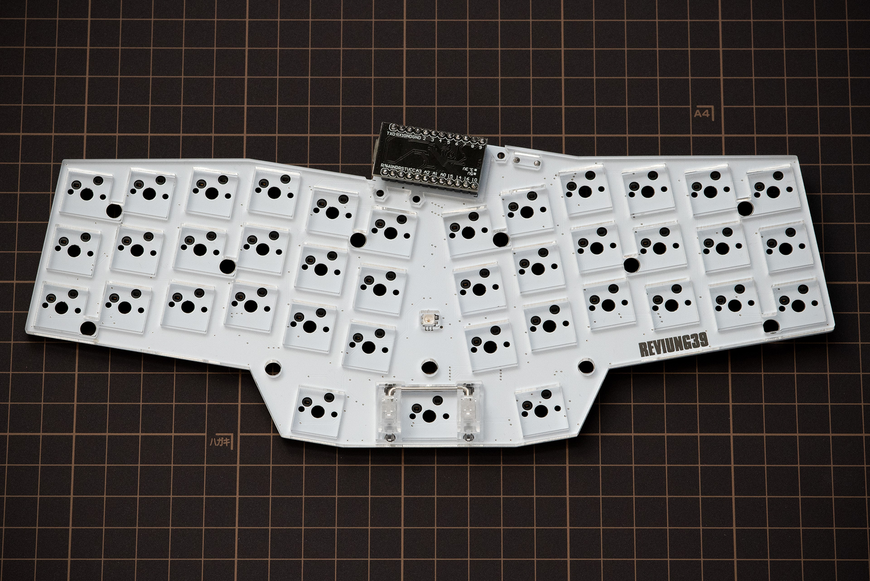
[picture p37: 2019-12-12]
reviung39/image/REVIUNG39mdp-3.jpg

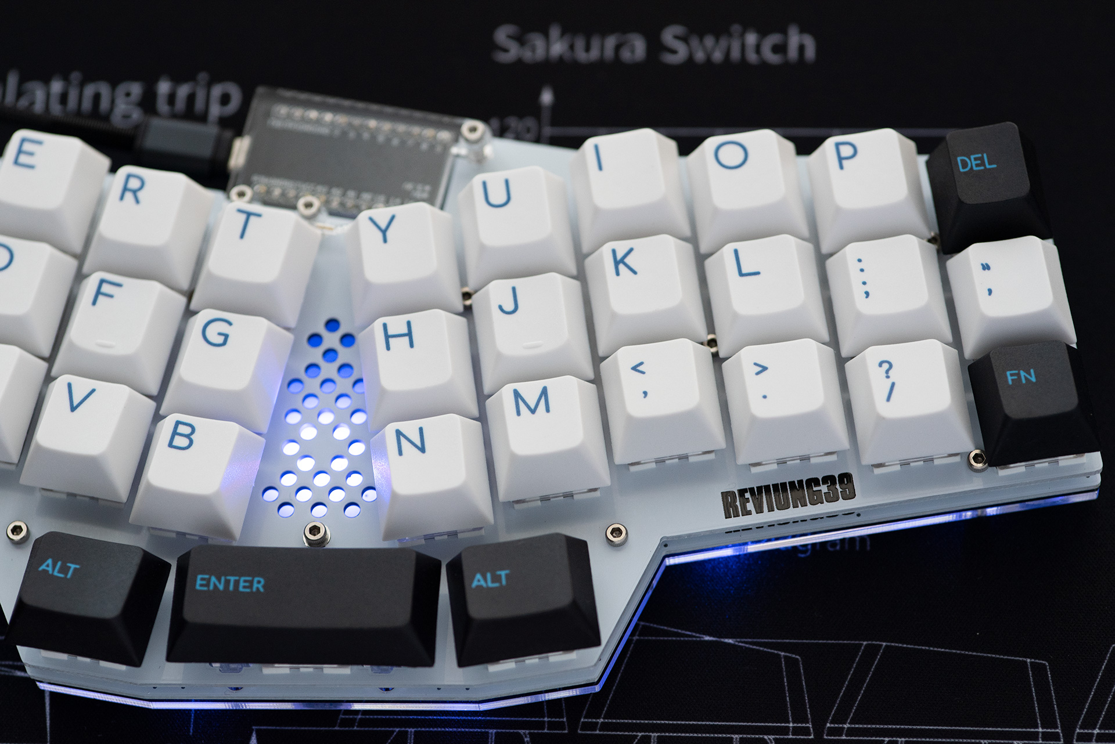
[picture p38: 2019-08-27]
reviung39/image/REVIUNG39-4.jpg

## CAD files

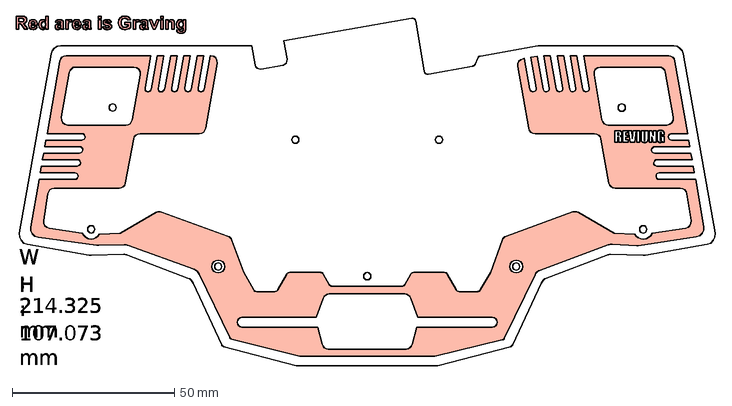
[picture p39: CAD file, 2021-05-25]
reviung34/acrylic-plate/bottom-plate/ver1.1/reviung34-bottom-plate-2mm-ver1.1.dxf
W : 214.325 mm
H : 107.073 mm

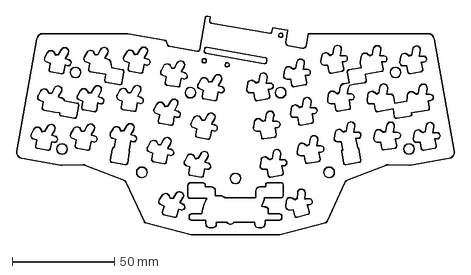
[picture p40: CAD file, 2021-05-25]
reviung34/acrylic-plate/lower-middle-plate/ver1.1/r34-lower-middle-3mm-ver1.1-TP.dxf
214.8 x 107.2 mm

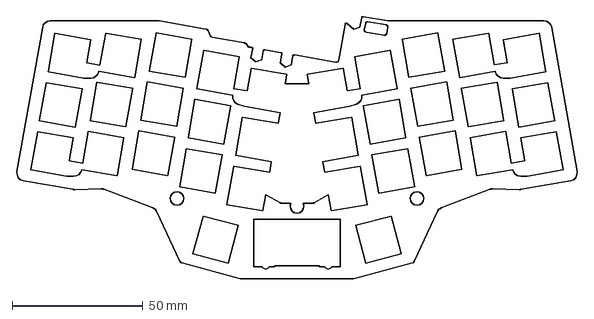
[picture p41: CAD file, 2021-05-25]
reviung34/acrylic-plate/upper-middle-plate/for-opaque/ver1.1/r34-upper-middle-3mm-ver1.1-OP.dxf
214.8 x 100.3 mm

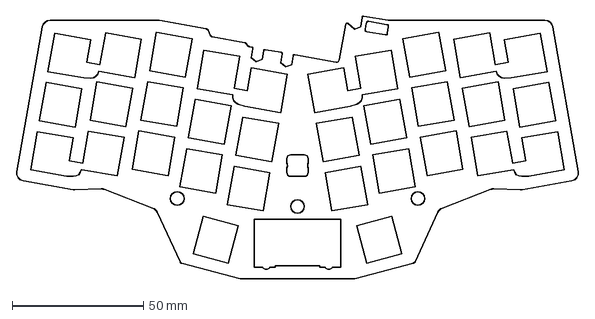
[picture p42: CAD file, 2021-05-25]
reviung34/acrylic-plate/upper-middle-plate/for-transparent/ver1.1/r34-upper-middle-3mm-ver1.1-TP.dxf
214.8 x 100.3 mm

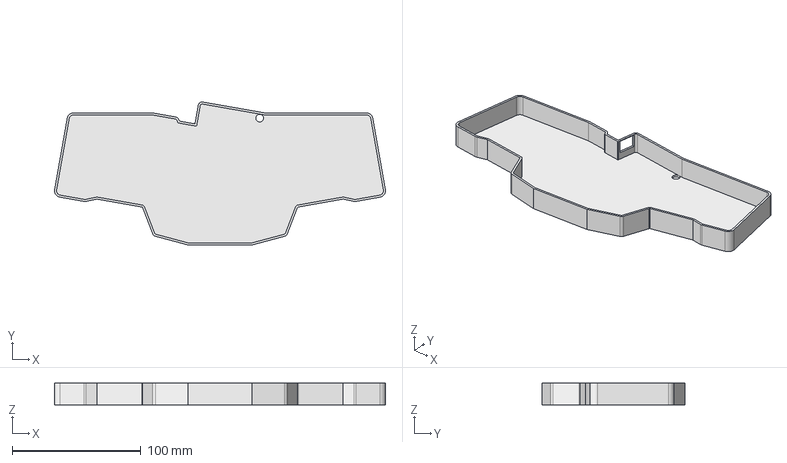
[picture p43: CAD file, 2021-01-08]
reviung39_Mk-II/case/Reviung39mkii-case.step
257.5 x 111.3 x 17.1 mm

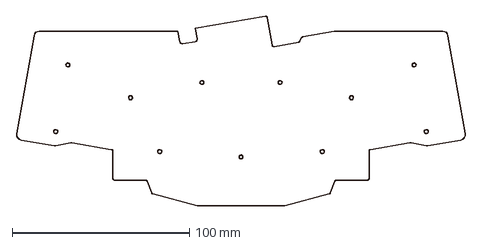
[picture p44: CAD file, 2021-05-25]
reviung41/acrylic-plate/bottom-plate/ver1.1/reviung41-bottom-plate-ver1.1.dxf
253.8 x 107.2 mm

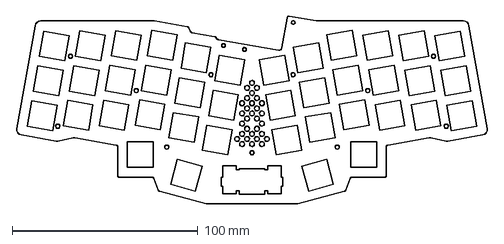
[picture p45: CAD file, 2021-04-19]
reviung41/acrylic-plate/top-plate/reviung41-top-plate.dxf
253.8 x 101.2 mm

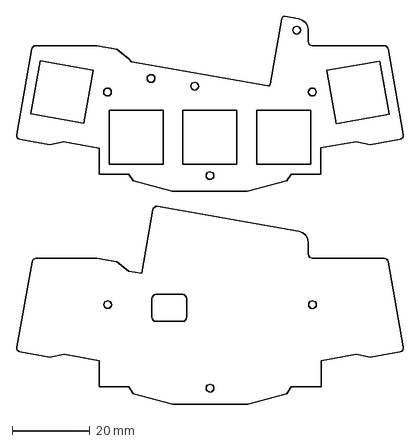
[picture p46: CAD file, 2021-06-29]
reviung5/acrylic-plate/top-bottom-2mm-ver1.1.dxf
99.9 x 100.1 mm

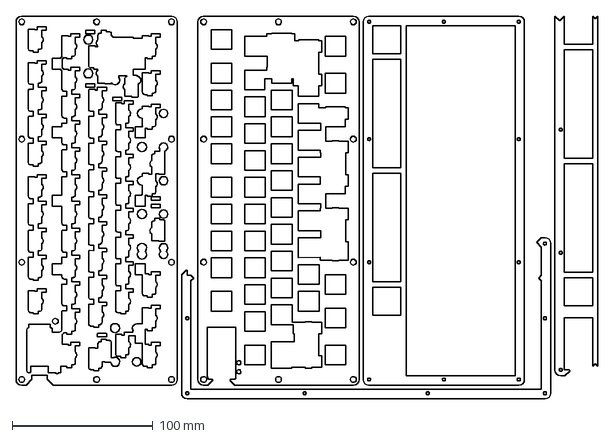
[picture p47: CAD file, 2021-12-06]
reviung53/acrylic-plate/for-middle-plate/reviung53_3mm_450x300_ver1.0.dxf
413.0 x 271.7 mm

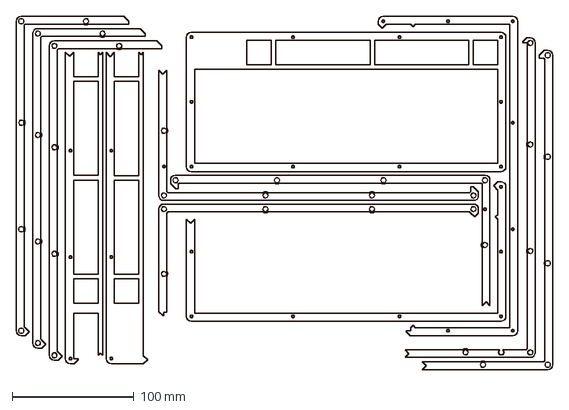
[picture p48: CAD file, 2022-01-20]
reviung53/acrylic-plate/for-stacked-acrylic-case/reviung53_2mm_450x300_ver1.1.dxf
440.0 x 290.0 mm

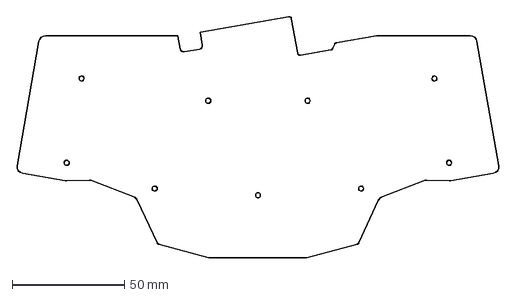
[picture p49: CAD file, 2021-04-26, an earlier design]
reviung34/acrylic-plate/bottom-plate/ver1.0/reviung34-bottom-plate-2mm-ver1.dxf
214.8 x 107.2 mm

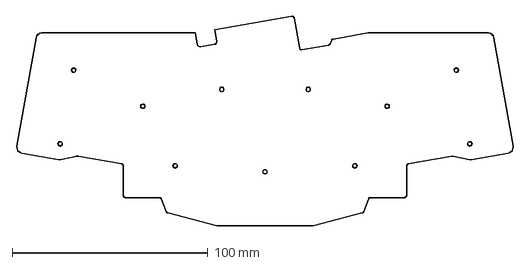
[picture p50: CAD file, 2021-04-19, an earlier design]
reviung41/acrylic-plate/bottom-plate/ver1.0/reviung41-bottom-plate.dxf
253.8 x 107.2 mm

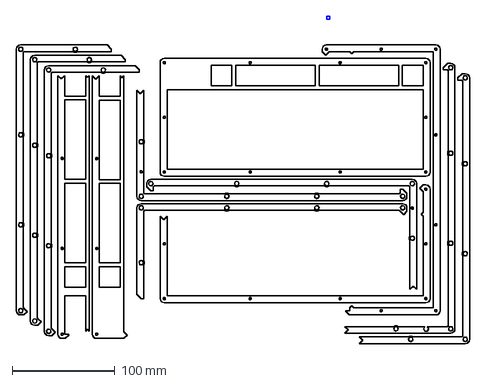
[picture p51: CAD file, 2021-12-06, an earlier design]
reviung53/acrylic-plate/for-stacked-acrylic-case/reviung53_2mm_450x300_ver1.0.dxf
440.0 x 317.7 mm

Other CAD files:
reviung39_Mk-II/case/Reviung39mkii-case.stl
reviung41/acrylic-plate/top-plate/reviung41-top-plate.dwg

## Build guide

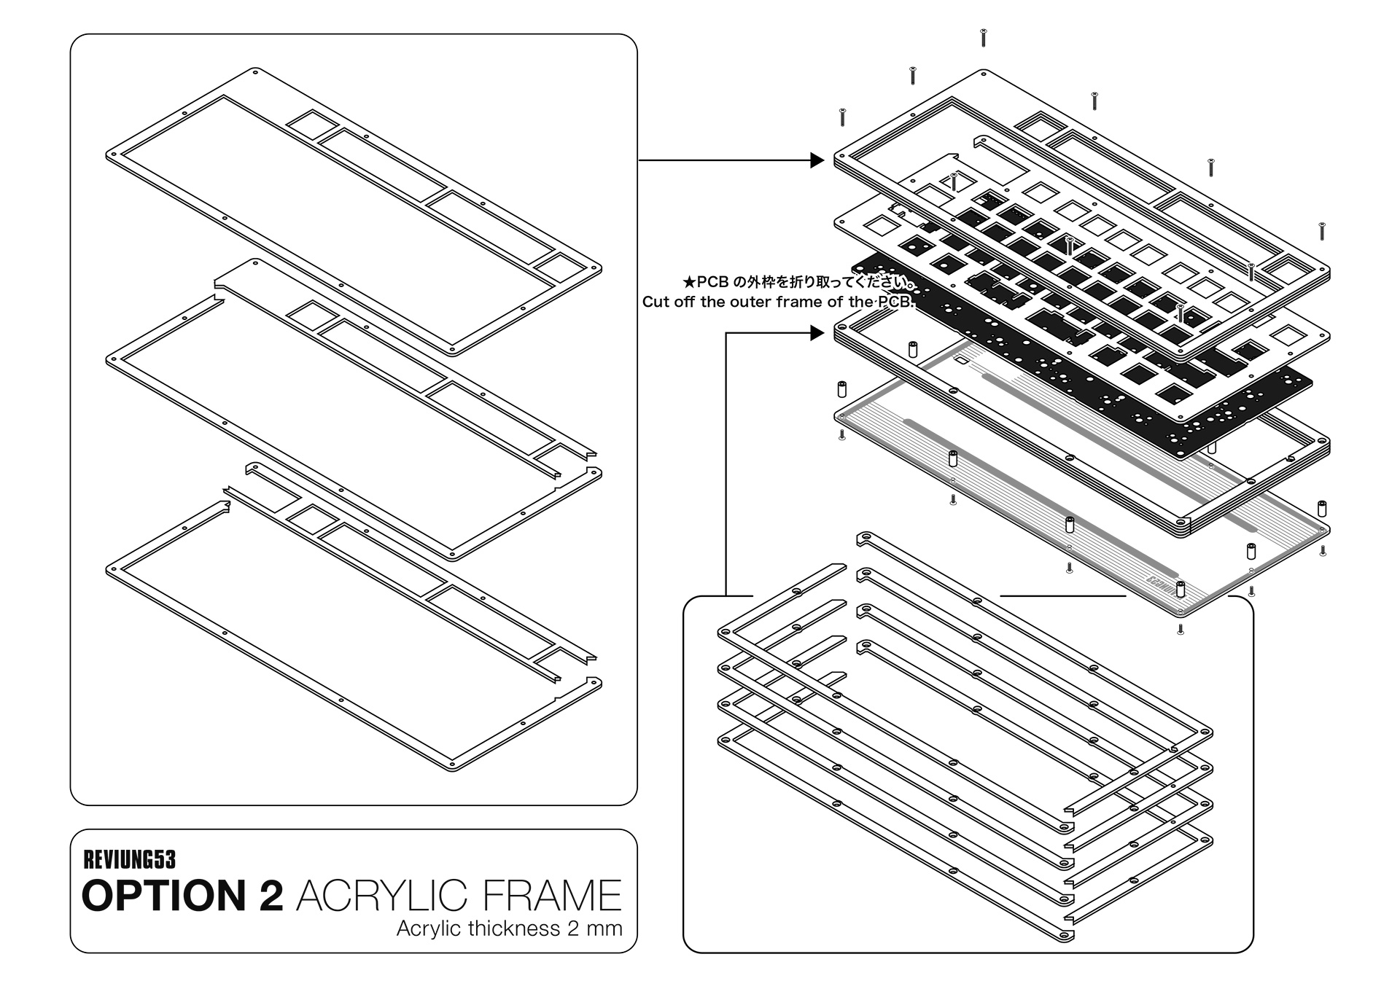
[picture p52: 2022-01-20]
reviung53/acrylic-plate/for-stacked-acrylic-case/Assembly_drawing.jpg

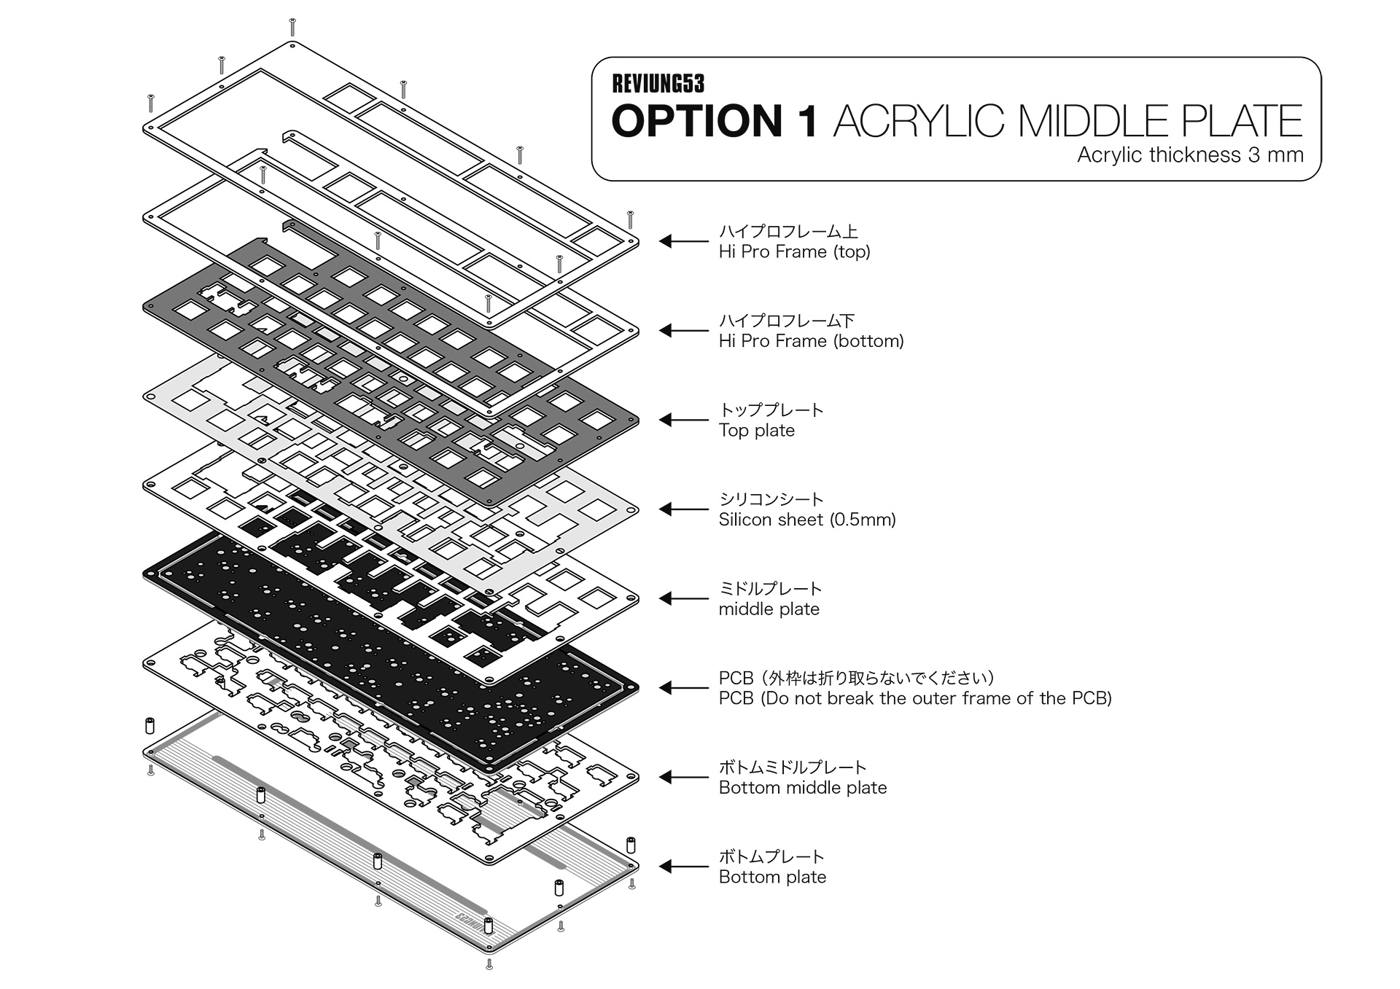
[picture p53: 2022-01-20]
reviung53/acrylic-plate/for-middle-plate/Assembly_drawing.jpg

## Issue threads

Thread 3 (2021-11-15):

Link to the keyboard footprings

kbrock, 2021-11-15:
Hello,

I was not able to find the library that you are using for your footprints and symbols. I think it is similar to https://github.com/foostan/kbd

Are you able to post a kicad library with the footprints and symbols that you are using?
Either as a repository, a directory here, or a submodule to another git repository?

Thank you again for the wonderful references.

gtips, 2024-08-05:
I've been away from GitHub for a while.
Sorry for the late response.

I need to clean up my footprints, they're a mess.
I'll add the footprints when I've cleaned them up.

kbrock, 2024-08-07:
@gtips Thank you so much for all your wonderful work. I have built 10+ of your keyboards and my daily driver is the reviung41. Again, thank you.

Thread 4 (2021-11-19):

Bom and pos for Reviung34

MikaelElkiaer, 2021-11-19:
Could you, or someone else who sees this, do bom and position lists for the Reviung34. Was hoping to do assembly service when ordering some PCBs.

gtips, 2024-08-05:
I've been away from GitHub for a while.
Sorry for the late response.

REVIUNG34 and others were designed to be hand soldered.
There are no bom and position lists.
Sorry.

Closed 2024-08-05.

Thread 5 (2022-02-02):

Why are non 'reviung layout' boards in the reviung repo?

RhinoCodes, 2022-02-02:
Most would consider a reviung to have the signature rev39/41 stagger, key positions, etc. Yet, you have boards in this repo that do not fit the 'reviung layout'. I propose moving the outliers to a new repo under your account, or just renamed in this repo.

Love your boards btw, it just gets confusing

Closed 2022-10-22.

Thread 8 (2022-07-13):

[Request] Reviung34 with hotswap

geedmo, 2022-07-13:
If possible and within your reach, it would be great to have reviung34.
I love these keyboards and I appreciate your great work.

gtips, 2024-08-05:
I've been away from GitHub for a while.
Sorry for the late response.

There are currently no plans for a hotswap version of REVIUNG34, but you can use "Mill Max" instead.

https://keeb.io/products/mill-max-hotswap-sockets

https://www.mouser.jp/ProductDetail/Mill-Max/3305-0-15-80-47-27-10-0?qs=CiayqK2gdcJ0UcFbwoRx4A%3D%3D

https://www.youtube.com/watch?v=xigj_DyaftM

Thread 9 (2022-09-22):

Acrylic Upper Mid Plate Is Missing Space For Switch Teeth

alexmadeathing, 2022-09-22:
The [sandwiched upper mid acrylic plate](https://github.com/gtips/reviung/tree/master/reviung41/acrylic-plate/upper-middle-plate) contains no space in the 14x14mm switch holes for the switch panel mount teeth to grip onto the FR4 top plate. So the switches may fall out, especially when removing keycaps.

I've hacked together an STL with some cutouts (shown below) which has enabled me to print my own upper mid plate, but sadly I don't have Illustrator, so can't submit a PR to correct the issue at source.

I'd like to suggest that something like the cutouts shown below is applied to the Reviung upper mid plate, so that the switches can grip the FR4 correctly.

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

gtips, 2024-08-05:
I've been away from GitHub for a while.
Sorry for the late confirmation.

Thanks for the suggestion.
https://github.com/gtips/reviung/tree/master/reviung41/acrylic-plate/upper-middle-plate/ver1.1
In this version, the switch hole is 14.9mm north-south, with 0.9mm of space left. So there is space for the switch tabs.
But the switch hole in your suggestion is cool.

alexmadeathing, 2024-08-08:
NP I must have had the older version then. Cheers, let's close this.

Closed 2024-08-08.

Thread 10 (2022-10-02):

Reviung 41 split spacebar

diekaines, 2022-10-02:
Hi all

Can we have a split spacebar design? Practically a reviung 42

Thanks

kbrock, 2022-11-08:
I like the reviung34 because of the 2x1u spacebar option. It is a really nice addition.
And the bottom row has one extra column line, so it hopefully won't be too much work.

dcai, 2022-11-09:
+1 for split spacebar, prefer 41's look but split spacebar makes 34 stands out.

Ardakilic, 2022-12-05:
I was just searching for this, hoping someone made a reviung41 with split spacebar. +1 for this as well.

Someone made it already by the way, but he's concerned about the license (it's MIT so it should be okay), but he's not sharing it.

https://twitter.com/daraku__neko/status/1401479320929923073

Maybe he's after some profits? 🤷‍♂️
https://twitter.com/daraku__neko/status/1489796199955976196

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

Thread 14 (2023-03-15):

Rev5 QMK Firmware?

Brittle73, 2023-03-15:
Hi gtips,

The link in the readme for the Rev5 firmware appears to be down:

https://github.com/qmk/qmk_firmware/tree/master/keyboards/reviung5

Is there a fix for that or somewhere else that we can grab the firmware for QMK?

Thanks!

Brittle73, 2023-03-15:
UPDATE: Apologies, I did not check QMK Configurator first. It does look like it's there:

https://config.qmk.fm/#/reviung/reviung5/LAYOUT

I was going to mark this as closed, but I am going to leave it open for now in case you aren't aware that the link in the readme is dead. Please feel free to close it though if that's not helpful.

Thanks!

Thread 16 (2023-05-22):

OLED

arlaneenalra, 2023-05-22:
Any chance of getting a version of the pcb that adds an oled to the Reviung41 ala the Corne? The schematic looks like it has the right pins free on the MCU .. but my non-existent KiCAD skills are not up to the task of adding the header and re-routing the board ...

gtips, 2024-08-05:
I've been away from GitHub for a while.
Sorry for the late response.

If there is a next version of REVIUNG41, I might consider OLDE, but I don't have any plans for it at the moment.

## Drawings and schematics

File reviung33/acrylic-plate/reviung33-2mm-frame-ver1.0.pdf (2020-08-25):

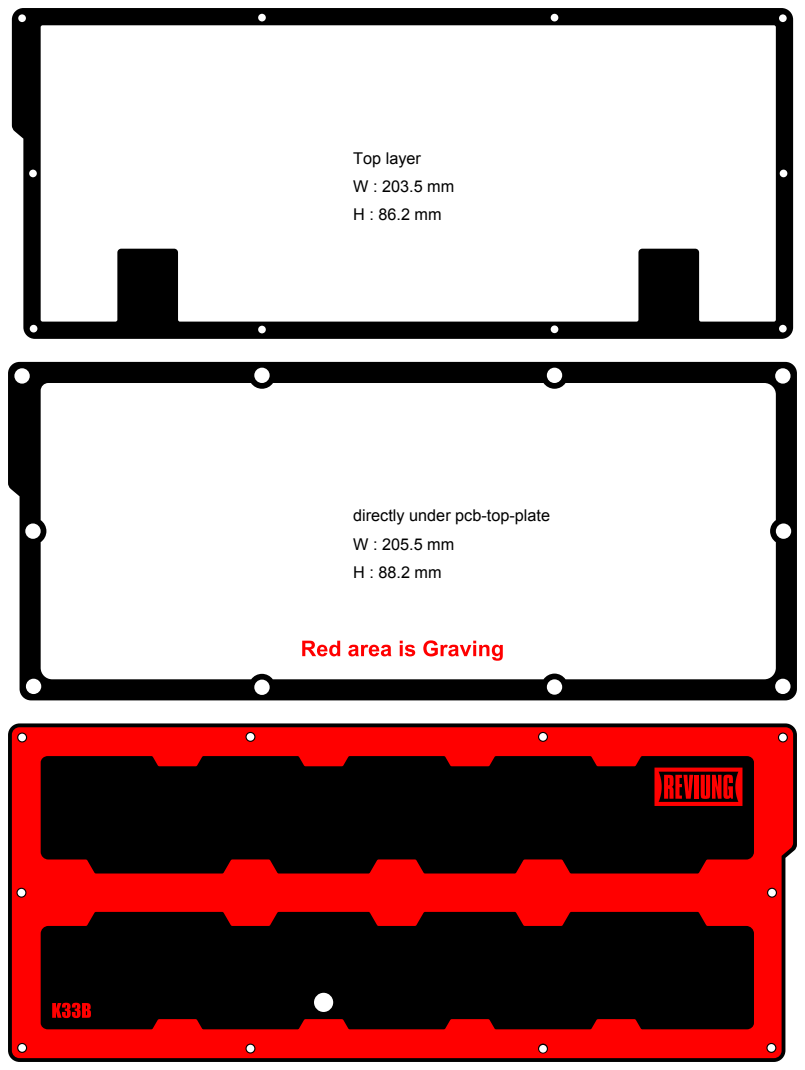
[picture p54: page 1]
Top layer W : 203.5 mm H : 86.2 mm

directly under pcb-top-plate

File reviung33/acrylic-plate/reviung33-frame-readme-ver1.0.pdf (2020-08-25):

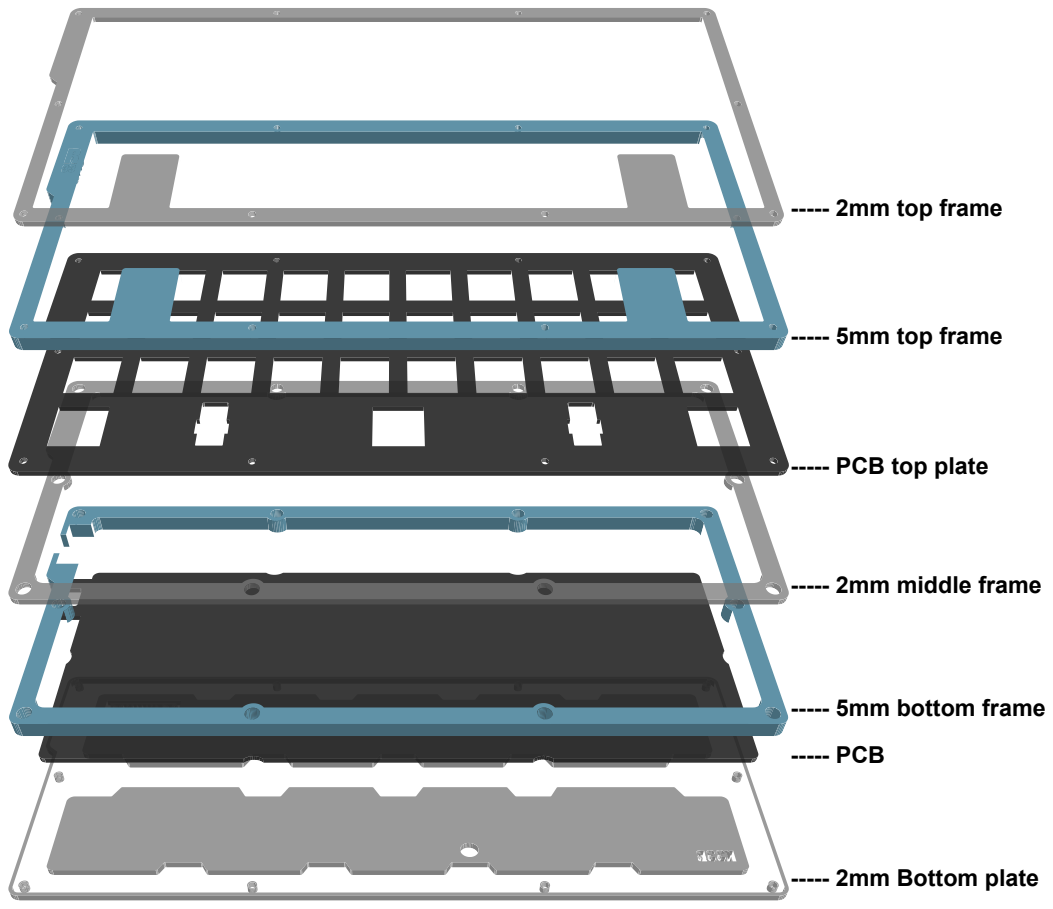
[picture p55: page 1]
----- 2mm top frame; ----- 5mm top frame; ----- 2mm middle frame; ----- 5mm bottom frame ----- PCB; ----- 2mm Bottom plate

----- PCB top plate

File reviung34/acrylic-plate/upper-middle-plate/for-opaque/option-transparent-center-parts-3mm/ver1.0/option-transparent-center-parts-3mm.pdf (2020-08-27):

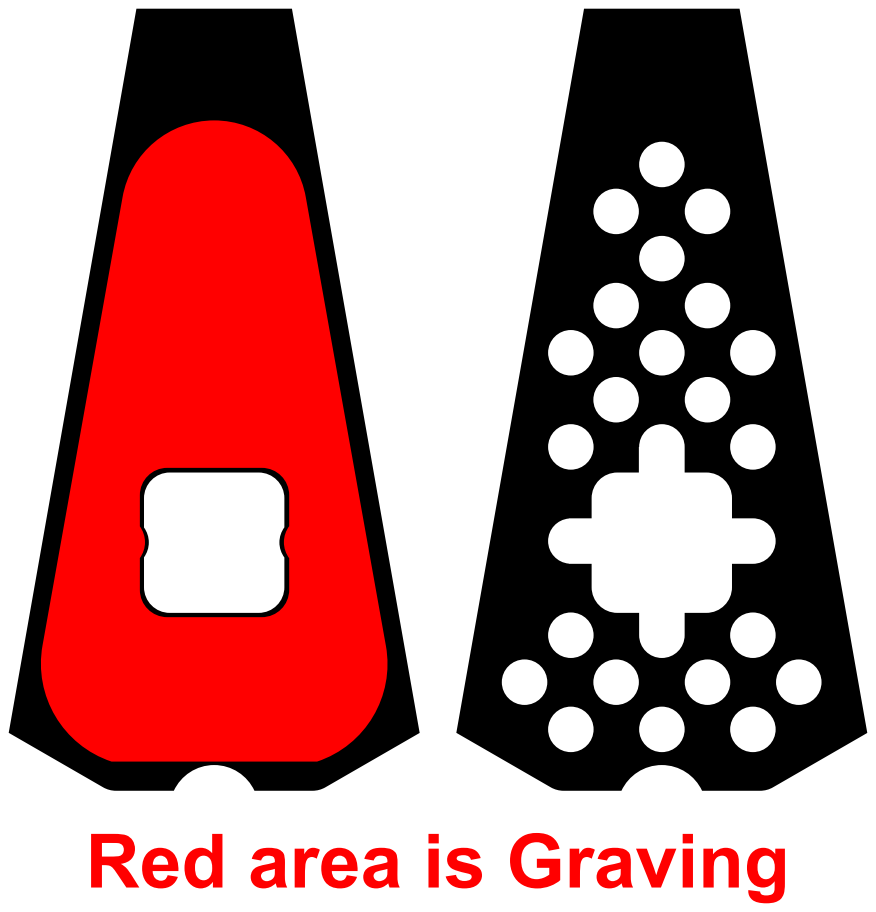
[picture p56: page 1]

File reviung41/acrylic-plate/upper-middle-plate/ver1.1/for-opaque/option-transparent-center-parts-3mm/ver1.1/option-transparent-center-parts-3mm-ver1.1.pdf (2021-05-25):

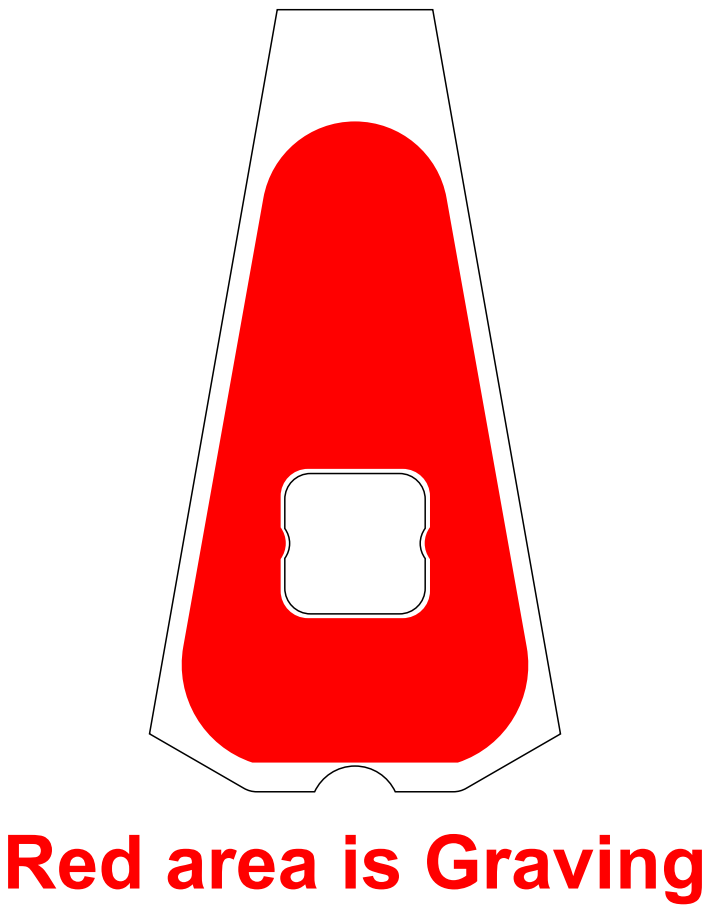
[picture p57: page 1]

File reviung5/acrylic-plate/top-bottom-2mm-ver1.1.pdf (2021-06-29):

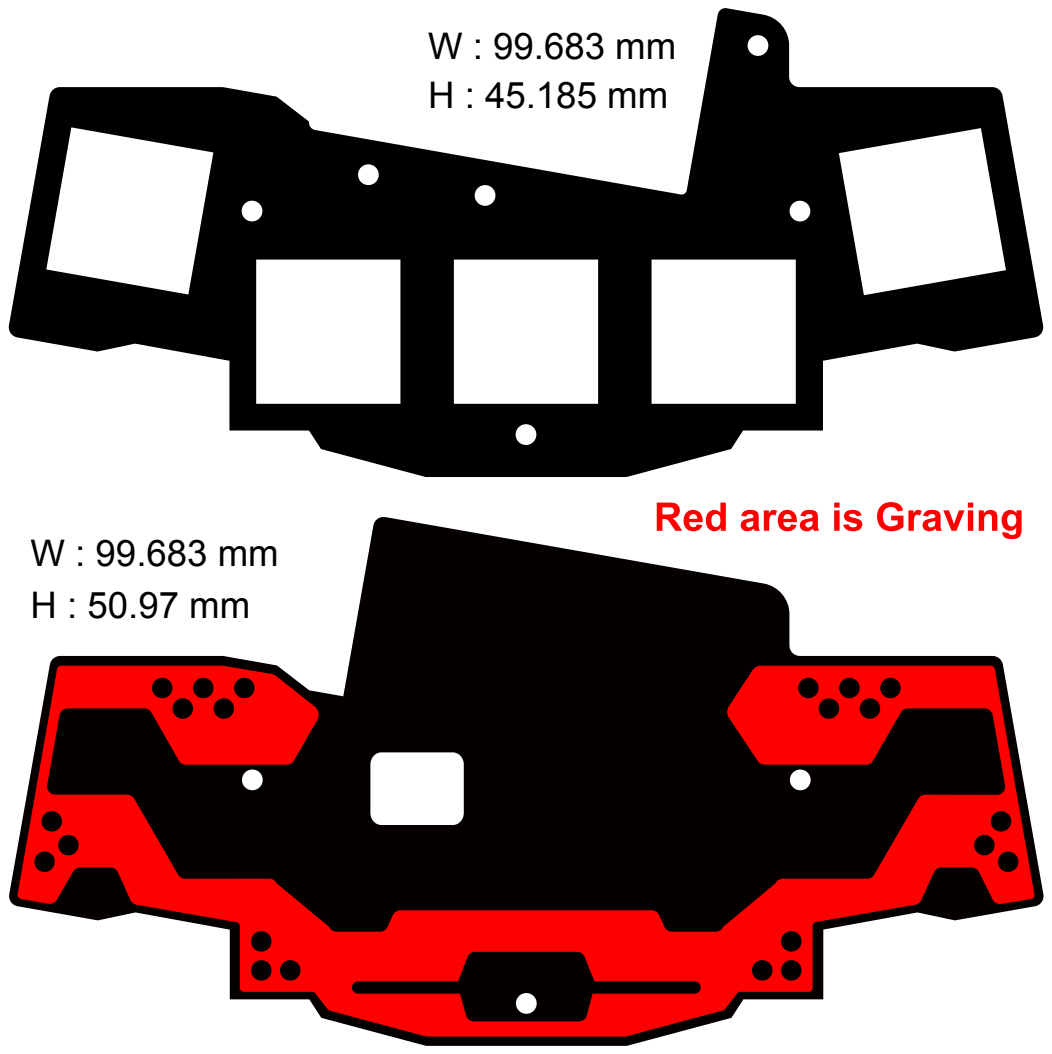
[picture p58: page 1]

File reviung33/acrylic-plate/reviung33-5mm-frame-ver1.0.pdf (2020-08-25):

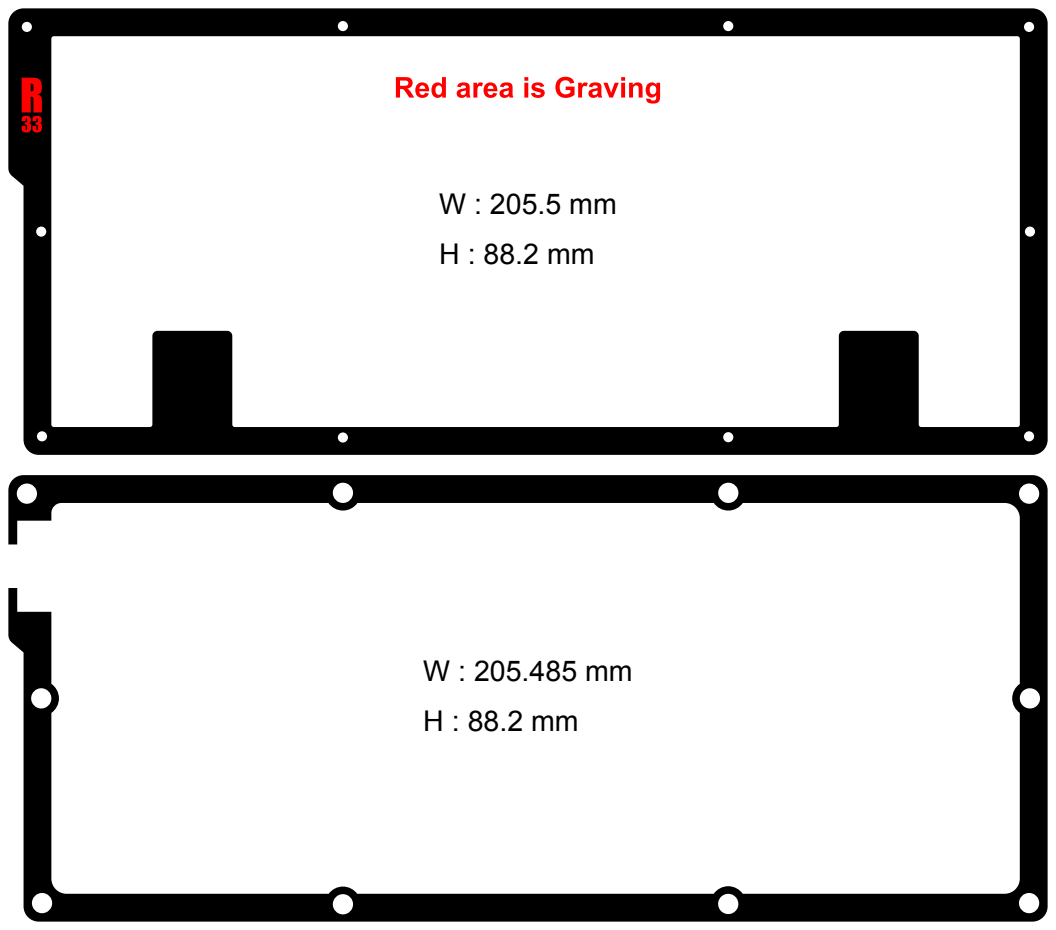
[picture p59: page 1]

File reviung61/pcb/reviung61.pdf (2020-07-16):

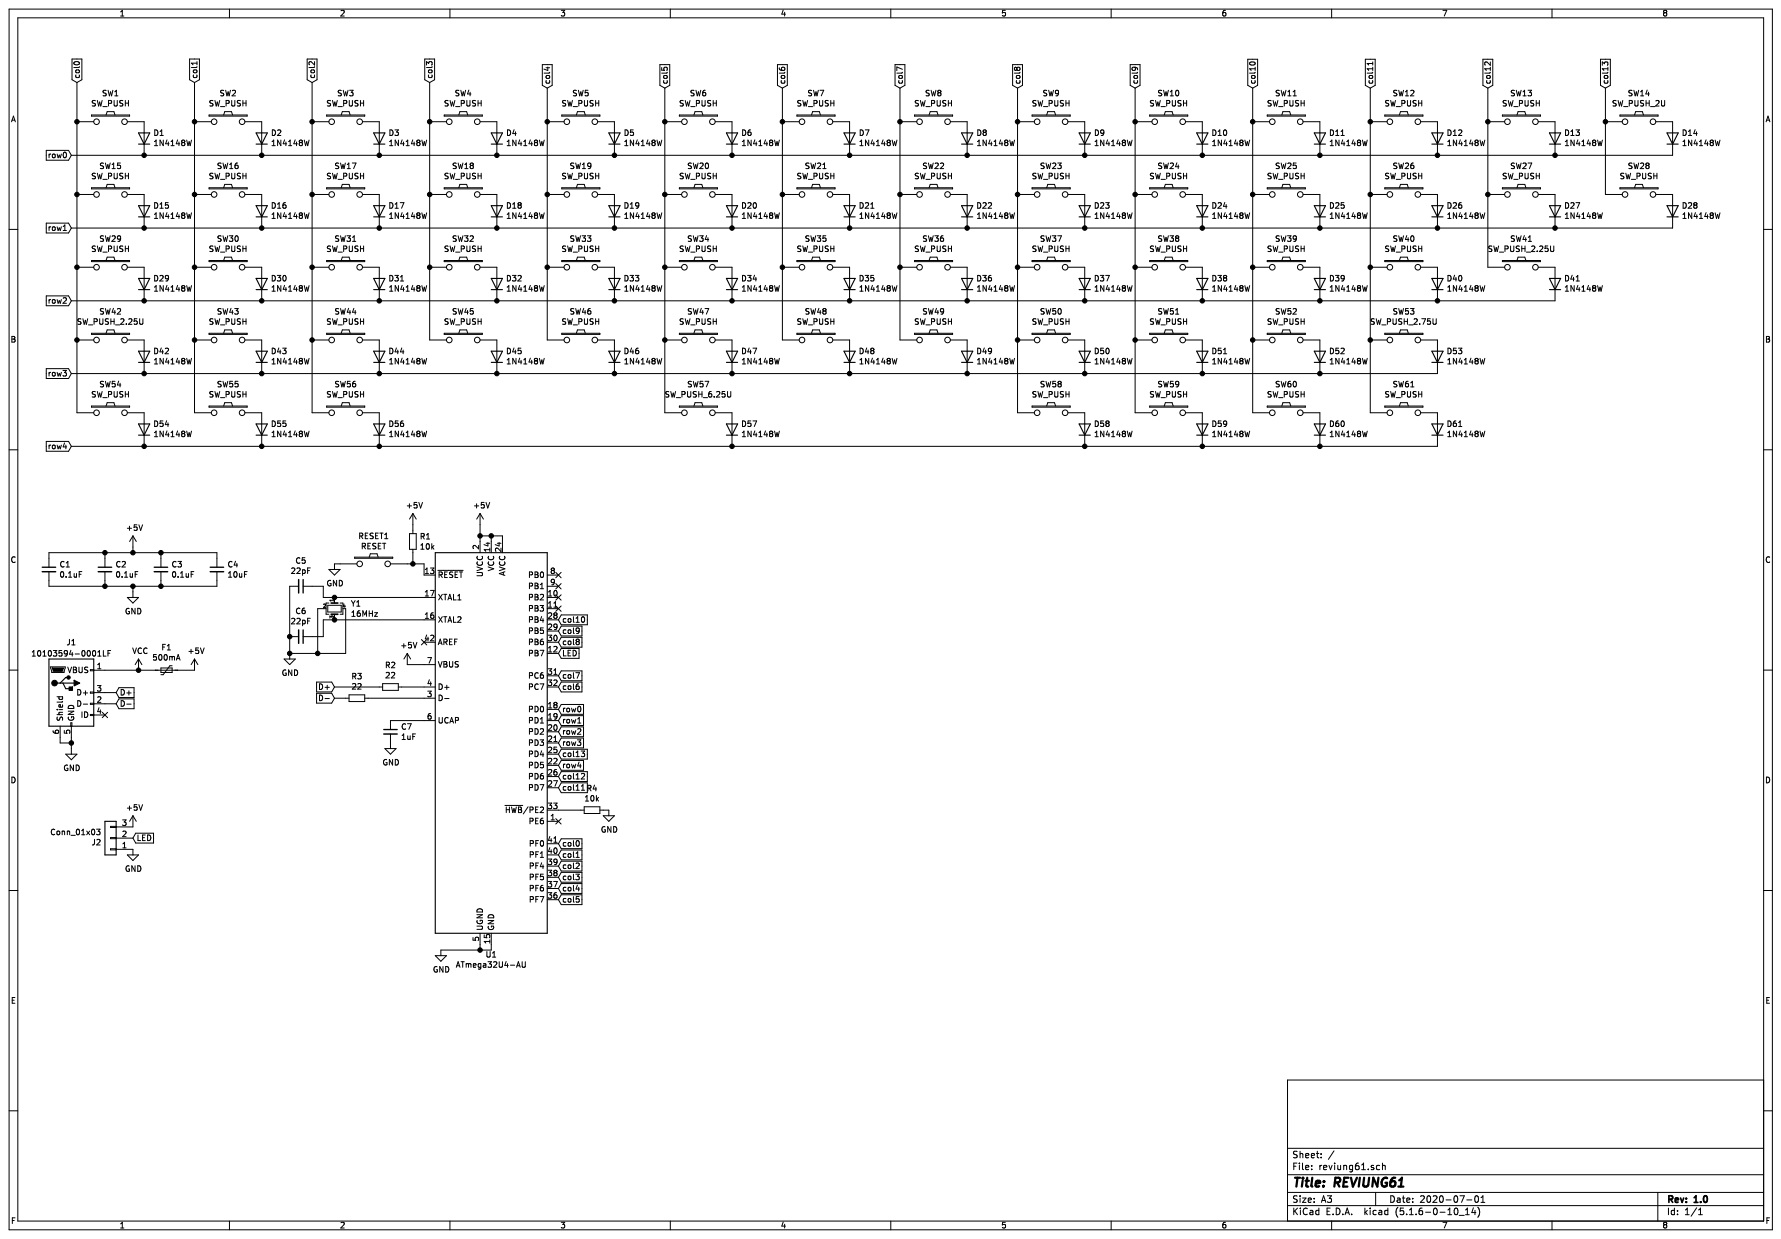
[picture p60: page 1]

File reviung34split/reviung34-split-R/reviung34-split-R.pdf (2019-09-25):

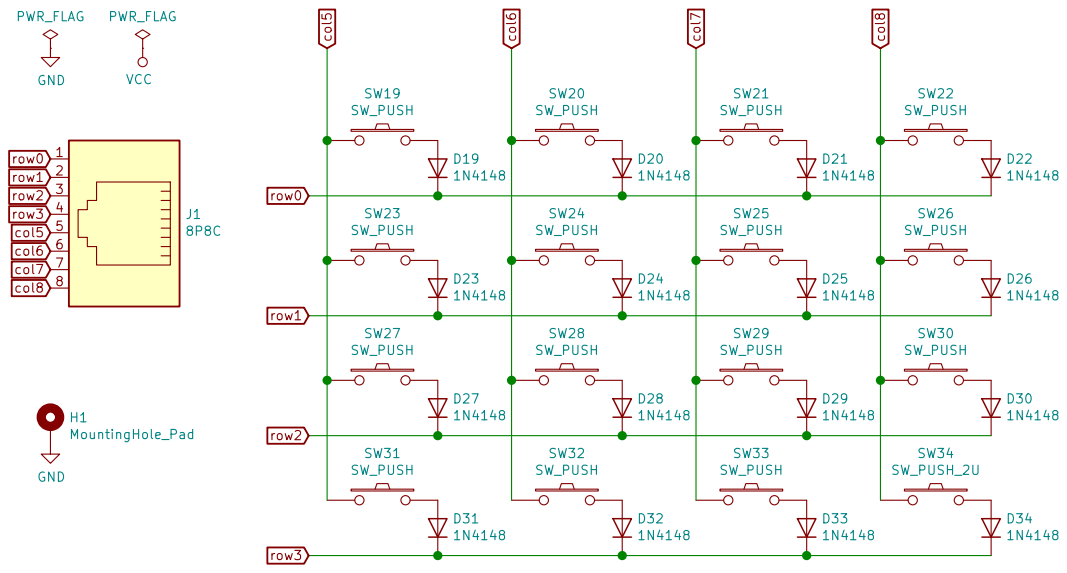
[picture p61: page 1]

SW24 SW_PUSH | SW25 SW_PUSH | 1N4148 SW27 SW_PUSH

SW28 SW_PUSH | SW29 SW_PUSH

File: reviung34-split-R.sch Sheet: /
Id: 1/1 Title: REVIUNG34-SPLIT-RIGHT

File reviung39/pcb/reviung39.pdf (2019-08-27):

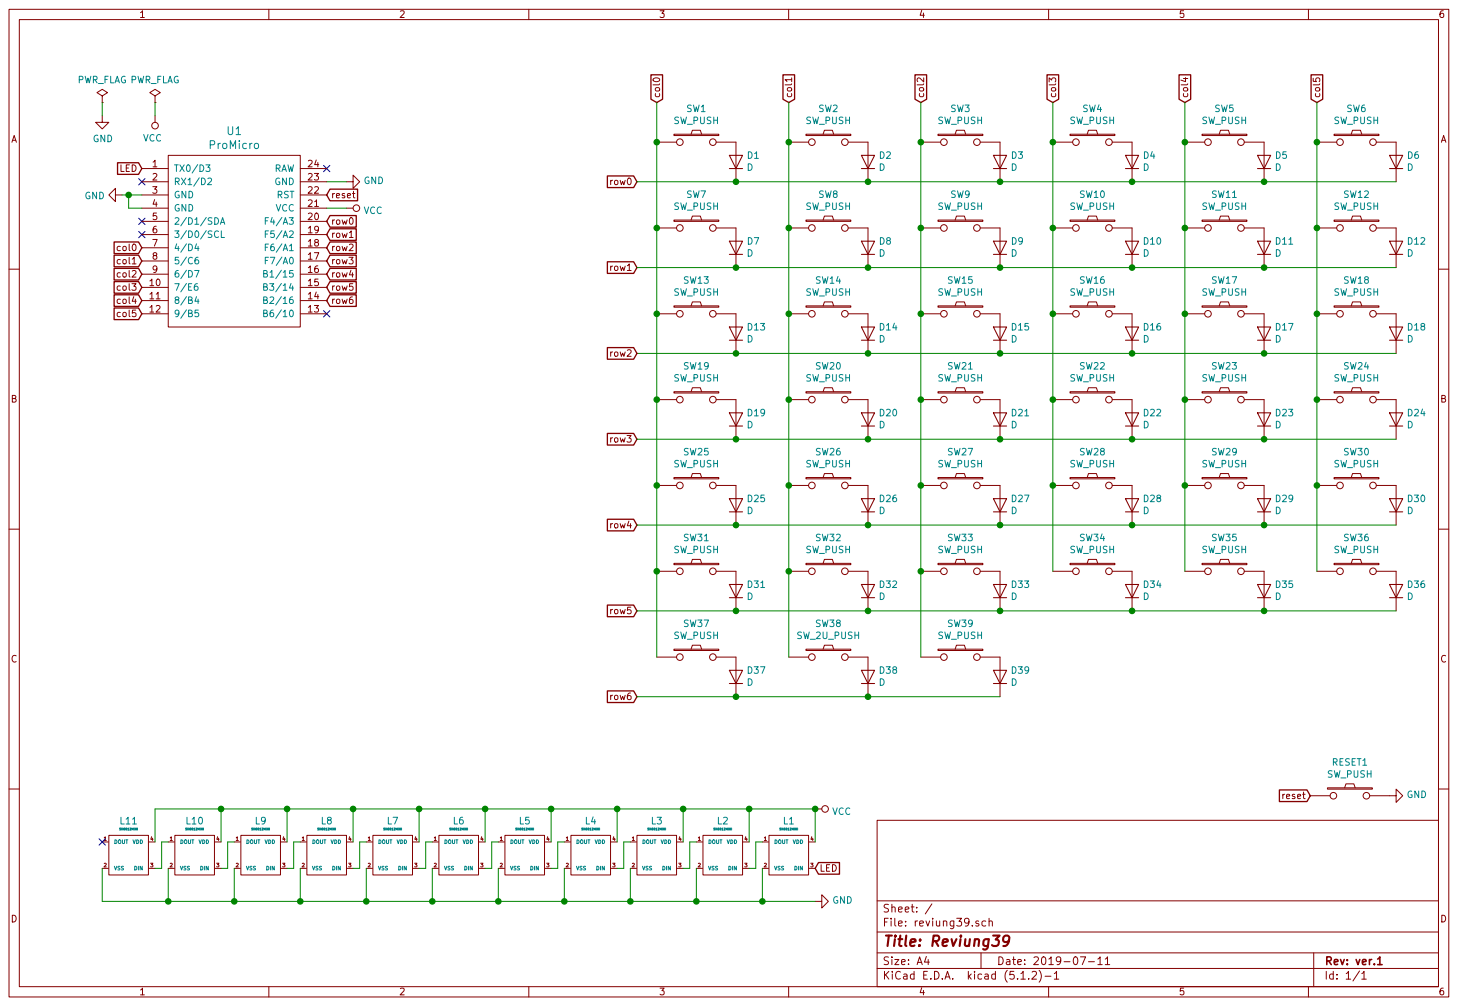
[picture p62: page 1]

SW7 SW_PUSH | SW8 SW_PUSH | SW9 SW_PUSH | SW10 SW_PUSH | SW11 SW_PUSH

SW13 SW_PUSH | SW14 SW_PUSH | SW15 SW_PUSH | SW16 SW_PUSH | SW17 SW_PUSH

SW19 SW_PUSH | SW20 SW_PUSH | SW21 SW_PUSH | SW22 SW_PUSH | SW23 SW_PUSH

SW25 SW_PUSH | SW26 SW_PUSH | SW27 SW_PUSH | SW28 SW_PUSH | SW29 SW_PUSH

SW31 SW_PUSH | SW32 SW_PUSH

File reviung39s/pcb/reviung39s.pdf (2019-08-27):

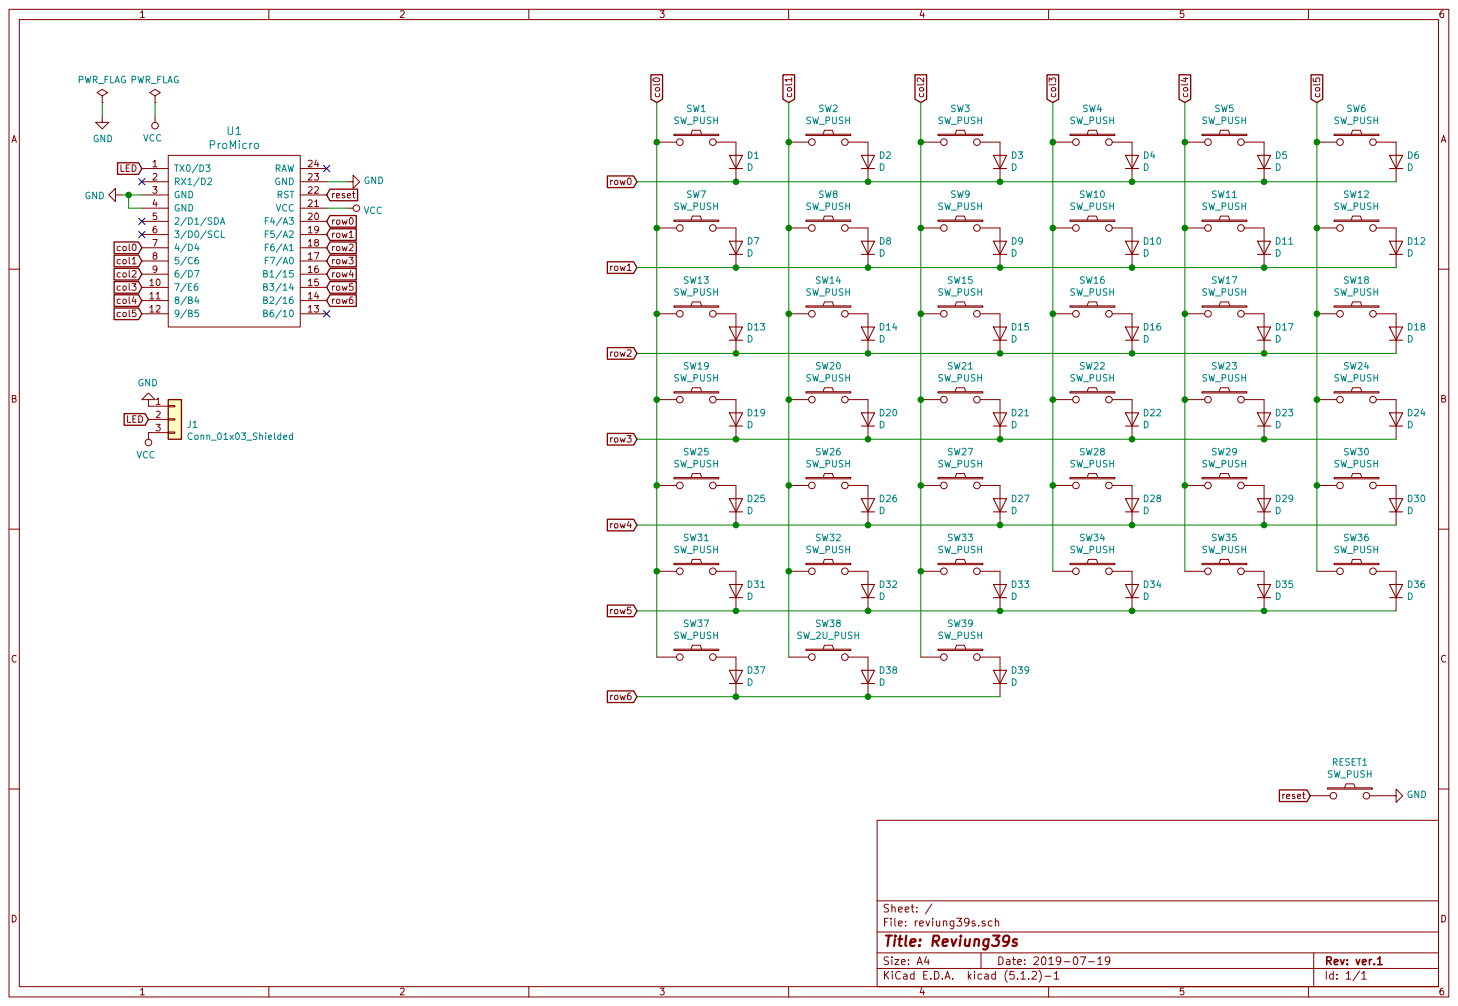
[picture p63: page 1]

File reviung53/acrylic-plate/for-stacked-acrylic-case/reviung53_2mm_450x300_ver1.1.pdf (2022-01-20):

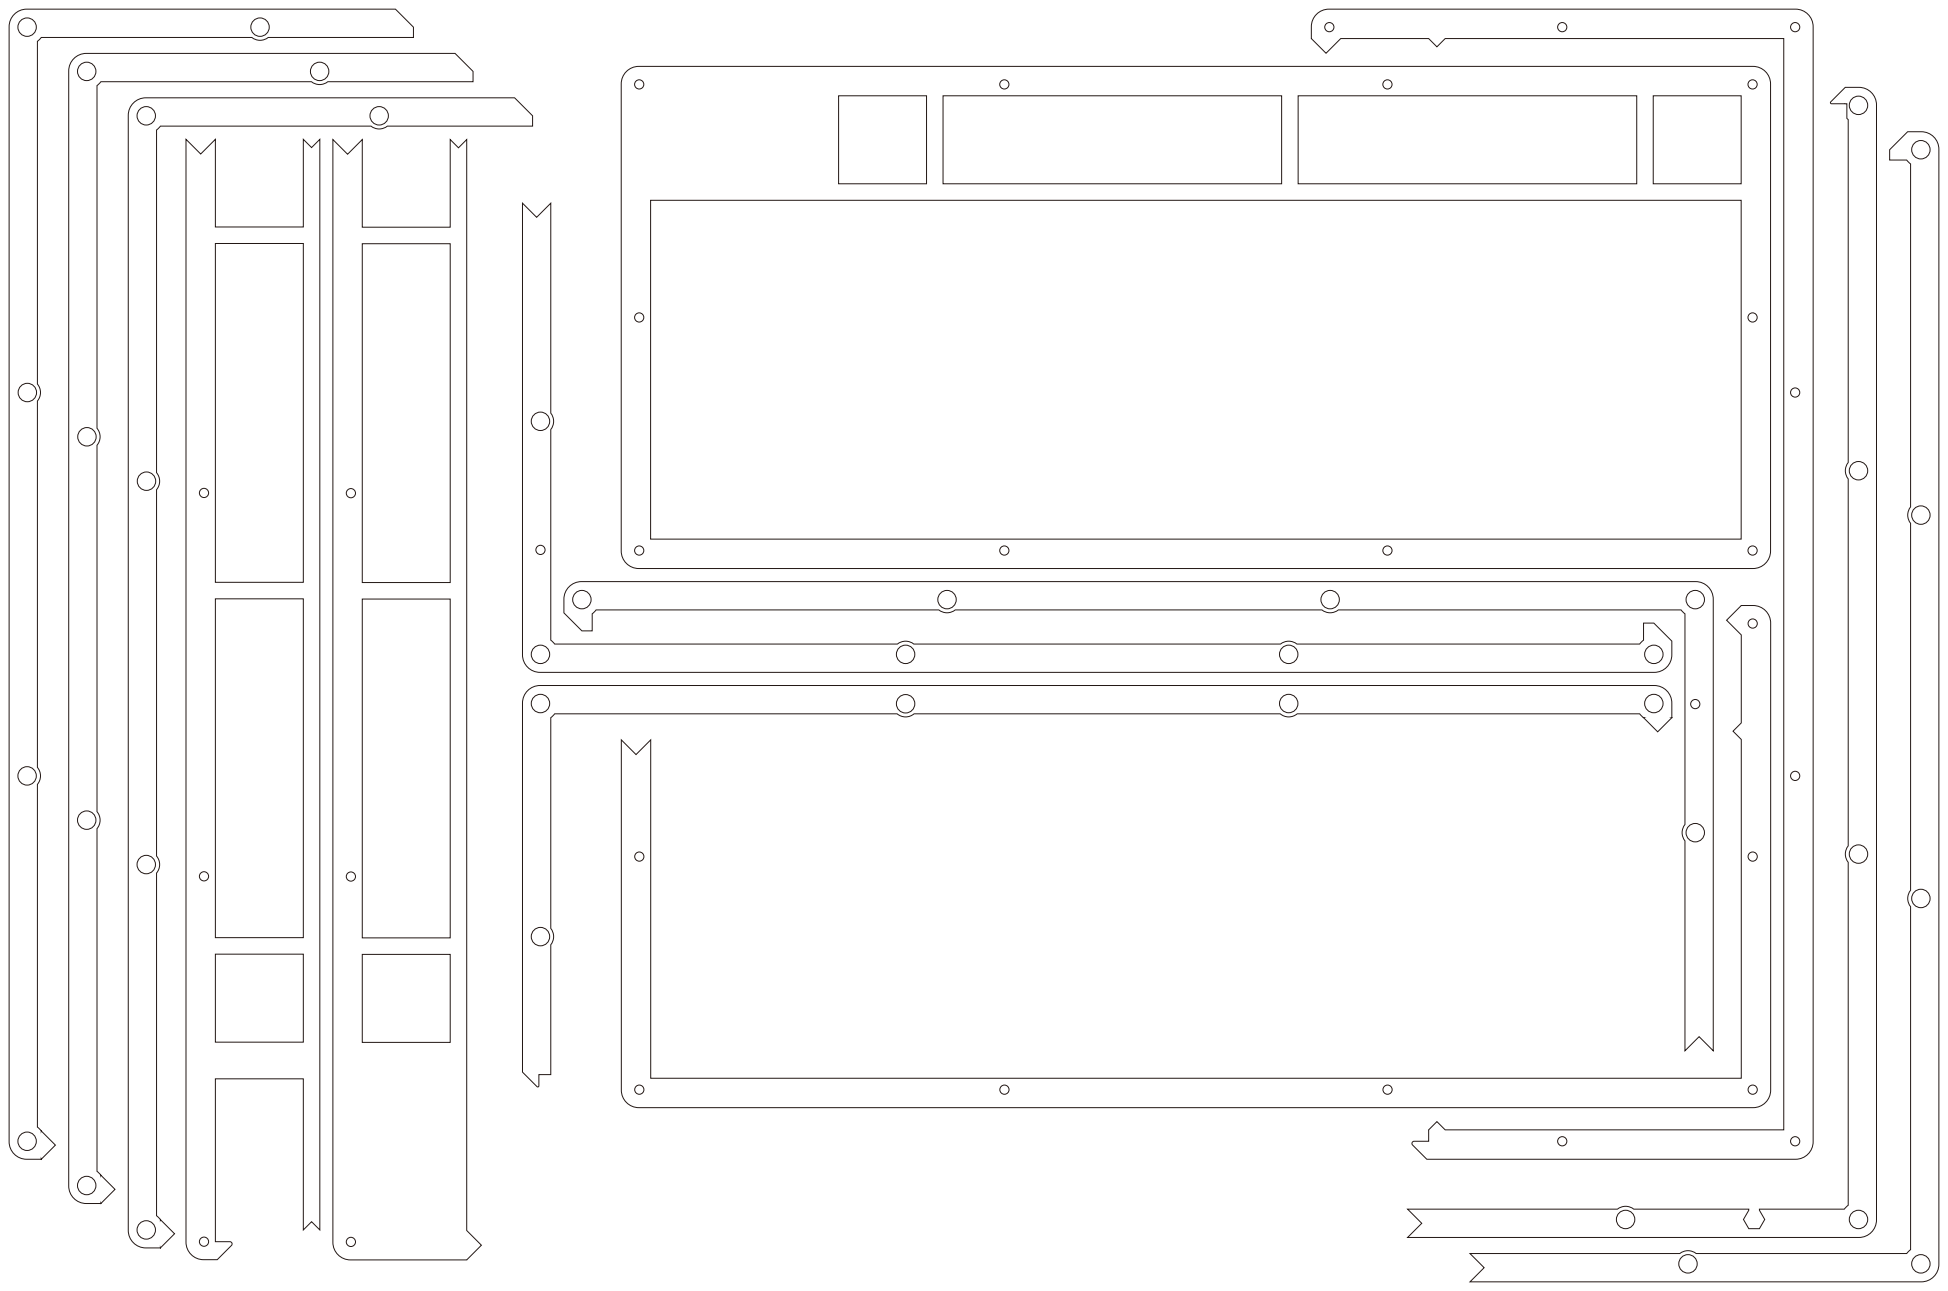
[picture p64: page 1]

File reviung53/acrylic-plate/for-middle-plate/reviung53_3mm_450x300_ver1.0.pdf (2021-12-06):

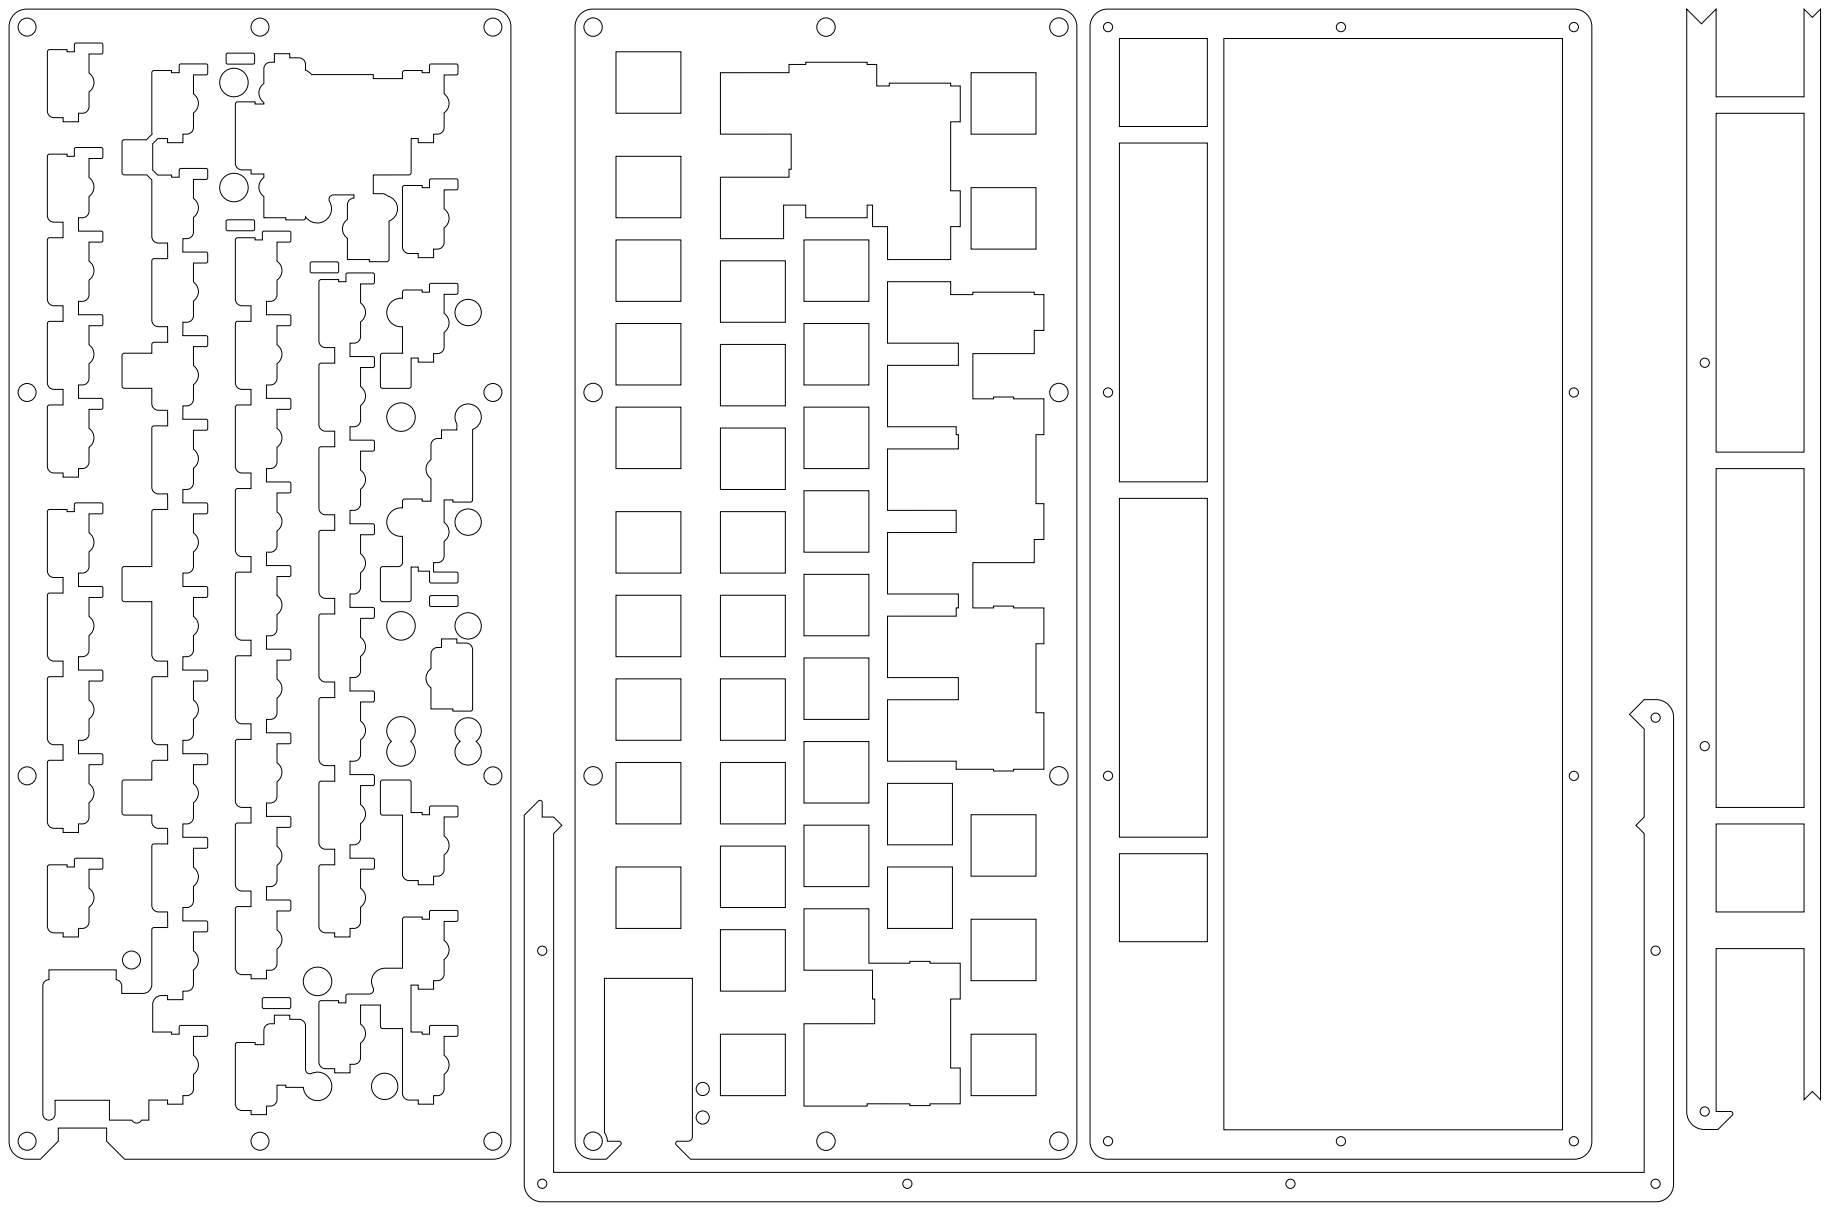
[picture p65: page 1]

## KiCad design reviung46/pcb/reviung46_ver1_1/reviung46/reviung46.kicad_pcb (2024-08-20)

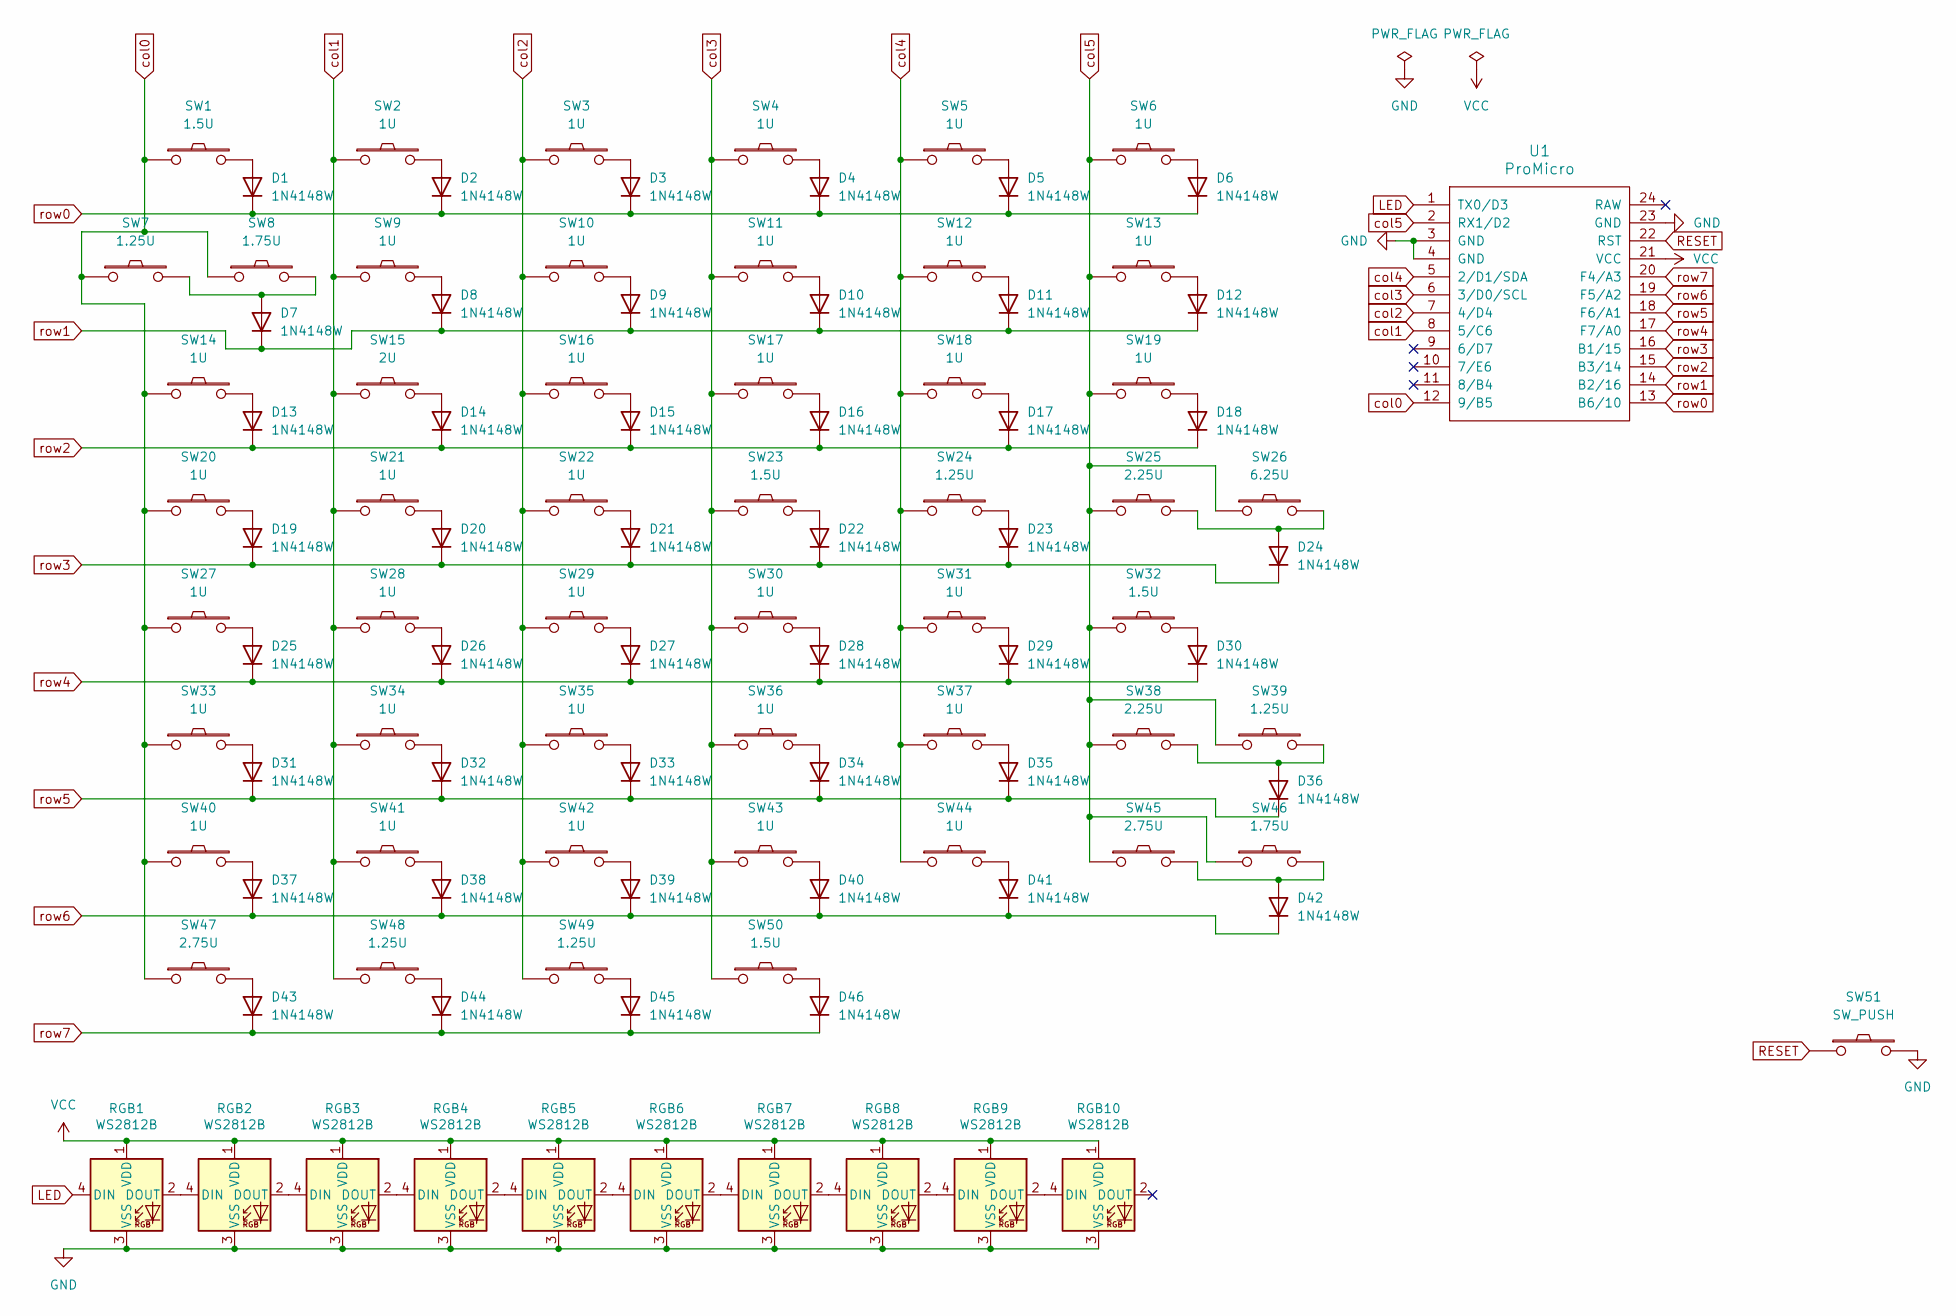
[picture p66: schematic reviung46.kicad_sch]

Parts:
D1, D2, D3, D4, D5, D6, D7, D8, D9, D10, D11, D12, D13, D14, D15, D16, D17, D18, D19, D20, D21, D22, D23, D24, D25, D26, D27, D28, D29, D30, D31, D32, D33, D34, D35, D36, D37, D38, D39, D40, D41, D42, D43, D44, D45, D46: 1N4148W; D3_SMD_1side
RGB1, RGB2, RGB3, RGB4, RGB5, RGB6, RGB7, RGB8, RGB9, RGB10: WS2812B; LED_WS2812B_PLCC4_5.0x5.0mm_P3.2mm_BigFoot
SW1, SW23, SW32, SW50: 1.5U; MXOnly-1.5U-Hotswap
SW2, SW3, SW4, SW5, SW6, SW9, SW10, SW11, SW12, SW13, SW14, SW16, SW17, SW18, SW19, SW20, SW21, SW22, SW27, SW28, SW29, SW30, SW31, SW33, SW34, SW35, SW36, SW37, SW40, SW41, SW42, SW43, SW44: 1U; MXOnly-1U-Hotswap
SW7, SW24, SW39, SW48, SW49: 1.25U; MXOnly-1.25U-Hotswap
SW8, SW46: 1.75U; MXOnly-1.75U-Hotswap
SW15: 2U; MXOnly-2U-Hotswap-ReversedStabilizers
SW25: 2.25U; MXOnly-2.25U-Hotswap
SW26: 6.25U; MXOnly-6.25U-Hotswap-ReversedStabilizers
SW38: 2.25U; MXOnly-2.25U-Hotswap-ReversedStabilizers
SW45, SW47: 2.75U; MXOnly-2.75U-Hotswap-ReversedStabilizers
SW51: SW_PUSH; ResetSW_1side
U1: ProMicro; ProMicroExtentionBard

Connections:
GND: RGB1.3 (VSS), RGB2.3 (VSS), RGB3.3 (VSS), RGB4.3 (VSS), RGB5.3 (VSS), RGB6.3 (VSS), RGB7.3 (VSS), RGB8.3 (VSS), RGB9.3 (VSS), RGB10.3 (VSS), SW51.2, U1.3 (GND), U1.4 (GND), U1.23 (GND)
LED: RGB1.4 (DIN), U1.1 (TX0/D3)
unnamed: D1.2 (A), SW1.2
unnamed: D2.2 (A), SW2.2
unnamed: D3.2 (A), SW3.2
unnamed: D4.2 (A), SW4.2
unnamed: D5.2 (A), SW5.2
unnamed: D6.2 (A), SW6.2
unnamed: D7.2 (A), SW7.2, SW8.2
unnamed: D8.2 (A), SW9.2
unnamed: D9.2 (A), SW10.2
unnamed: D10.2 (A), SW11.2
unnamed: D11.2 (A), SW12.2
unnamed: D12.2 (A), SW13.2
unnamed: D13.2 (A), SW14.2
unnamed: D14.2 (A), SW15.2
unnamed: D15.2 (A), SW16.2
unnamed: D16.2 (A), SW17.2
unnamed: D17.2 (A), SW18.2
unnamed: D18.2 (A), SW19.2
unnamed: D19.2 (A), SW20.2
unnamed: D20.2 (A), SW21.2
unnamed: D21.2 (A), SW22.2
unnamed: D22.2 (A), SW23.2
unnamed: D23.2 (A), SW24.2
unnamed: D24.2 (A), SW25.2, SW26.2
unnamed: D25.2 (A), SW27.2
unnamed: D26.2 (A), SW28.2
unnamed: D27.2 (A), SW29.2
unnamed: D28.2 (A), SW30.2
unnamed: D29.2 (A), SW31.2
unnamed: D30.2 (A), SW32.2
unnamed: D31.2 (A), SW33.2
unnamed: D32.2 (A), SW34.2
unnamed: D33.2 (A), SW35.2
unnamed: D34.2 (A), SW36.2
unnamed: D35.2 (A), SW37.2
unnamed: D36.2 (A), SW38.2, SW39.2
unnamed: D37.2 (A), SW40.2
unnamed: D38.2 (A), SW41.2
unnamed: D39.2 (A), SW42.2
unnamed: D40.2 (A), SW43.2
unnamed: D41.2 (A), SW44.2
unnamed: D42.2 (A), SW45.2, SW46.2
unnamed: D43.2 (A), SW47.2
unnamed: D44.2 (A), SW48.2
unnamed: D45.2 (A), SW49.2
unnamed: D46.2 (A), SW50.2
unnamed: RGB1.2 (DOUT), RGB2.4 (DIN)
unnamed: RGB2.2 (DOUT), RGB3.4 (DIN)
unnamed: RGB3.2 (DOUT), RGB4.4 (DIN)
unnamed: RGB4.2 (DOUT), RGB5.4 (DIN)
unnamed: RGB5.2 (DOUT), RGB6.4 (DIN)
unnamed: RGB6.2 (DOUT), RGB7.4 (DIN)
unnamed: RGB7.2 (DOUT), RGB8.4 (DIN)
unnamed: RGB8.2 (DOUT), RGB9.4 (DIN)
unnamed: RGB9.2 (DOUT), RGB10.4 (DIN)
RESET: SW51.1, U1.22 (RST)
VCC: RGB1.1 (VDD), RGB2.1 (VDD), RGB3.1 (VDD), RGB4.1 (VDD), RGB5.1 (VDD), RGB6.1 (VDD), RGB7.1 (VDD), RGB8.1 (VDD), RGB9.1 (VDD), RGB10.1 (VDD), U1.21 (VCC)
col0: SW1.1, SW7.1, SW8.1, SW14.1, SW20.1, SW27.1, SW33.1, SW40.1, SW47.1, U1.12 (9/B5)
col1: SW2.1, SW9.1, SW15.1, SW21.1, SW28.1, SW34.1, SW41.1, SW48.1, U1.8 (5/C6)
col2: SW3.1, SW10.1, SW16.1, SW22.1, SW29.1, SW35.1, SW42.1, SW49.1, U1.7 (4/D4)
col3: SW4.1, SW11.1, SW17.1, SW23.1, SW30.1, SW36.1, SW43.1, SW50.1, U1.6 (3/D0/SCL)
col4: SW5.1, SW12.1, SW18.1, SW24.1, SW31.1, SW37.1, SW44.1, U1.5 (2/D1/SDA)
col5: SW6.1, SW13.1, SW19.1, SW25.1, SW26.1, SW32.1, SW38.1, SW39.1, SW45.1, SW46.1, U1.2 (RX1/D2)
row0: D1.1 (K), D2.1 (K), D3.1 (K), D4.1 (K), D5.1 (K), D6.1 (K), U1.13 (B6/10)
row1: D7.1 (K), D8.1 (K), D9.1 (K), D10.1 (K), D11.1 (K), D12.1 (K), U1.14 (B2/16)
row2: D13.1 (K), D14.1 (K), D15.1 (K), D16.1 (K), D17.1 (K), D18.1 (K), U1.15 (B3/14)
row3: D19.1 (K), D20.1 (K), D21.1 (K), D22.1 (K), D23.1 (K), D24.1 (K), U1.16 (B1/15)
row4: D25.1 (K), D26.1 (K), D27.1 (K), D28.1 (K), D29.1 (K), D30.1 (K), U1.17 (F7/A0)
row5: D31.1 (K), D32.1 (K), D33.1 (K), D34.1 (K), D35.1 (K), D36.1 (K), U1.18 (F6/A1)
row6: D37.1 (K), D38.1 (K), D39.1 (K), D40.1 (K), D41.1 (K), D42.1 (K), U1.19 (F5/A2)
row7: D43.1 (K), D44.1 (K), D45.1 (K), D46.1 (K), U1.20 (F4/A3)

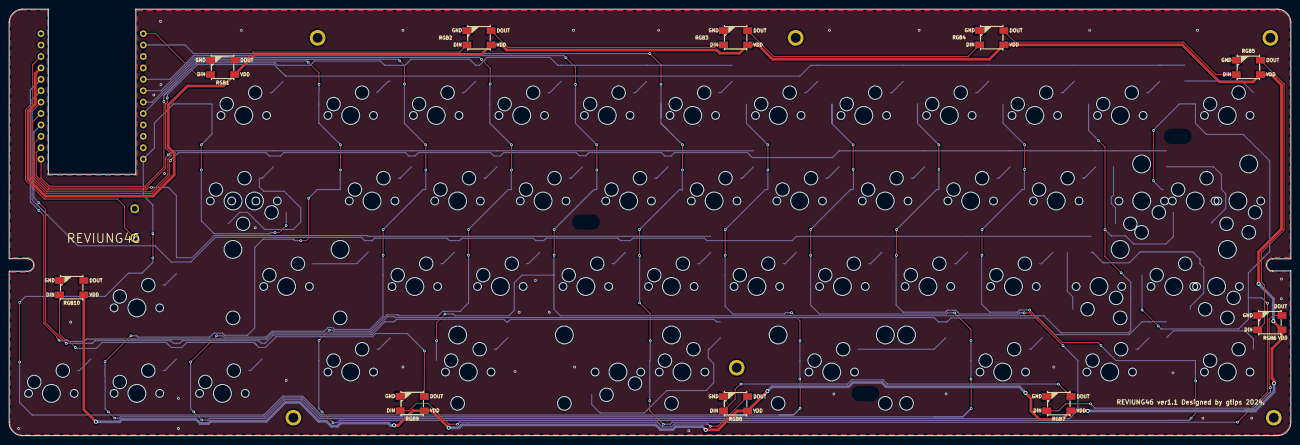
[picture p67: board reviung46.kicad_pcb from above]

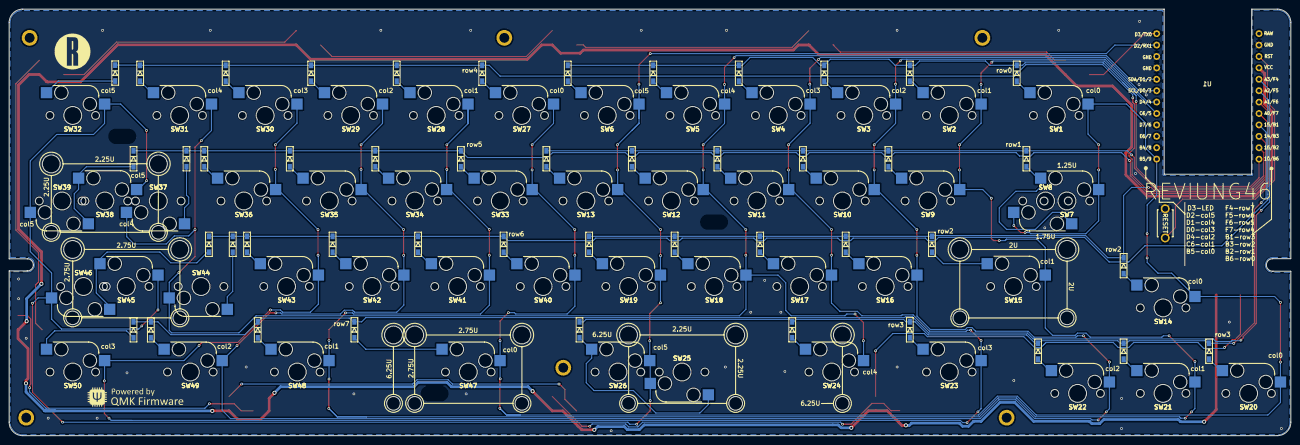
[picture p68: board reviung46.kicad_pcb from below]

Board: 2 copper layers, 285.5 x 95.0 mm, 112 parts (47 on the bottom side), 73 nets.

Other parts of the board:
Ref**: Val**; MountingHole_2.2mm_M2_ISO7380_Pad
Ref**#2, Ref**#3, Ref**#4: Val**; MountingHole_2.2mm_M2_ISO7380_Pad

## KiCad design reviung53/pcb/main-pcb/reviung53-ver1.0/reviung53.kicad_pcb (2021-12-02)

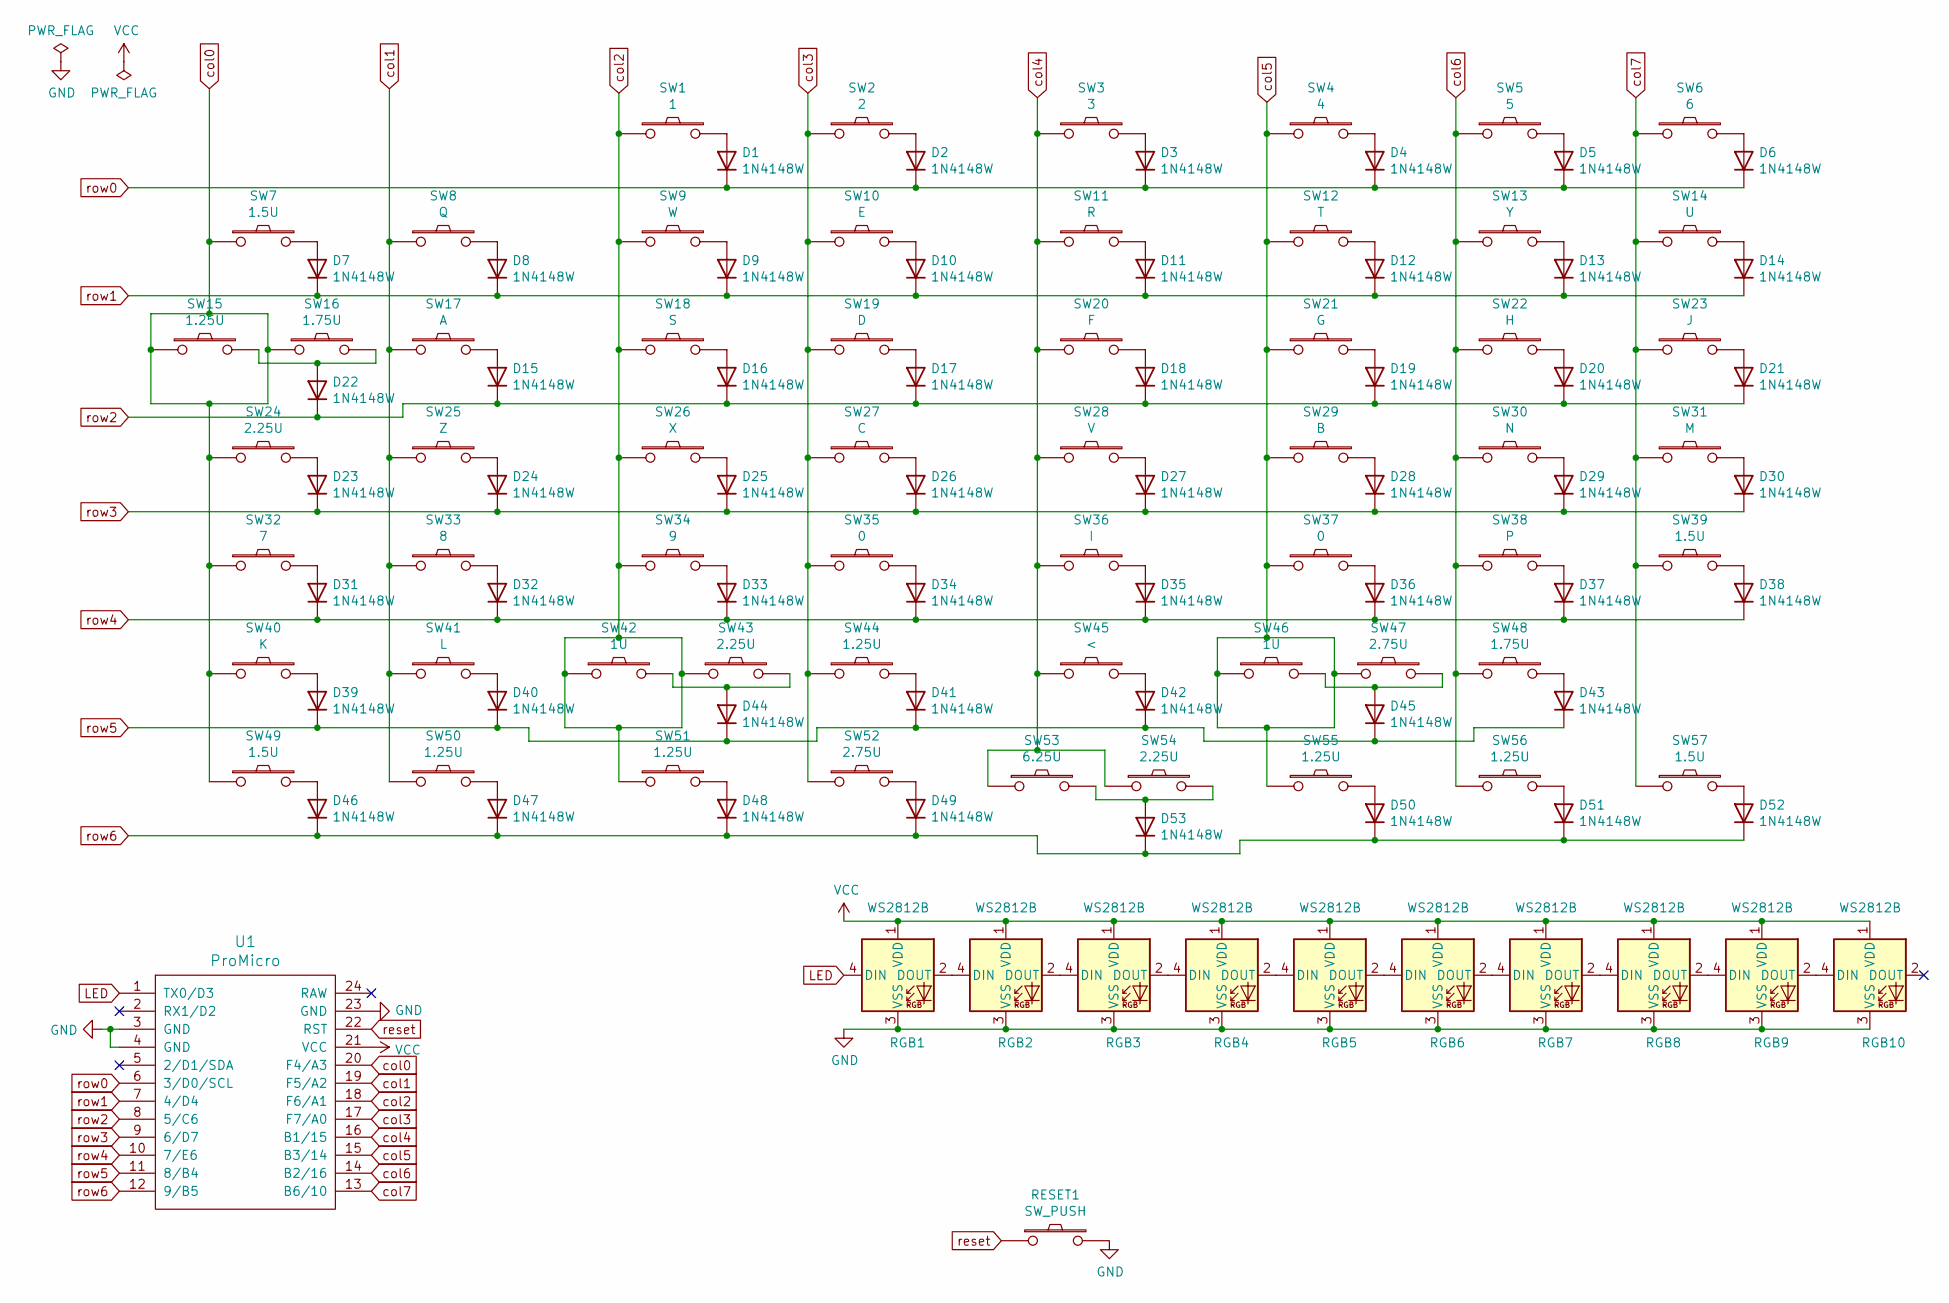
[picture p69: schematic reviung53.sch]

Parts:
D1, D2, D3, D4, D5, D6, D7, D8, D9, D10, D11, D12, D13, D14, D15, D16, D17, D18, D19, D20, D21, D22, D23, D24, D25, D26, D27, D28, D29, D30, D31, D32, D33, D34, D35, D36, D37, D38, D39, D40, D41, D42, D43, D44, D45, D46, D47, D48, D49, D50, D51, D52, D53: 1N4148W; D3_SMD_1side
RESET1: SW_PUSH; ResetSW_1side
RGB1, RGB2, RGB3, RGB4, RGB5, RGB6, RGB7, RGB8, RGB9, RGB10: WS2812B; LED_WS2812B_PLCC4_5.0x5.0mm_P3.2mm_BigFoot
SW1: 1; MXOnly-1U-Hotswap
SW2: 2; MXOnly-1U-Hotswap
SW3: 3; MXOnly-1U-Hotswap
SW4: 4; MXOnly-1U-Hotswap
SW5: 5; MXOnly-1U-Hotswap
SW6: 6; MXOnly-1U-Hotswap
SW7, SW39, SW49, SW57: 1.5U; MXOnly-1.5U-Hotswap
SW8: Q; MXOnly-1U-Hotswap
SW9: W; MXOnly-1U-Hotswap
SW10: E; MXOnly-1U-Hotswap
SW11: R; MXOnly-1U-Hotswap
SW12: T; MXOnly-1U-Hotswap
SW13: Y; MXOnly-1U-Hotswap
SW14: U; MXOnly-1U-Hotswap
SW15, SW44, SW50, SW51, SW55, SW56: 1.25U; MXOnly-1.25U-Hotswap
SW16, SW48: 1.75U; MXOnly-1.75U-Hotswap
SW17: A; MXOnly-1U-Hotswap
SW18: S; MXOnly-1U-Hotswap
SW19: D; MXOnly-1U-Hotswap
SW20: F; MXOnly-1U-Hotswap
SW21: G; MXOnly-1U-Hotswap
SW22: H; MXOnly-1U-Hotswap
SW23: J; MXOnly-1U-Hotswap
SW24, SW43: 2.25U; MXOnly-2.25U-Hotswap-ReversedStabilizers
SW25: Z; MXOnly-1U-Hotswap
SW26: X; MXOnly-1U-Hotswap
SW27: C; MXOnly-1U-Hotswap
SW28: V; MXOnly-1U-Hotswap
SW29: B; MXOnly-1U-Hotswap
SW30: N; MXOnly-1U-Hotswap
SW31: M; MXOnly-1U-Hotswap
SW32: 7; MXOnly-1U-Hotswap
SW33: 8; MXOnly-1U-Hotswap
SW34: 9; MXOnly-1U-Hotswap
SW35, SW37: 0; MXOnly-1U-Hotswap
SW36: I; MXOnly-1U-Hotswap
SW38: P; MXOnly-1U-Hotswap
SW40: K; MXOnly-1U-Hotswap
SW41: L; MXOnly-1U-Hotswap
SW42, SW46: 1U; MXOnly-1U-Hotswap
SW45: <; MXOnly-1U-Hotswap
SW47: 2.75U; MXOnly-2.75U-Hotswap-ReversedStabilizers
SW52: 2.75U; MXOnly-2.75U-Hotswap
SW53: 6.25U; MXOnly-6.25U-Hotswap-ReversedStabilizers
SW54: 2.25U; MXOnly-2.25U-Hotswap
U1: ProMicro

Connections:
GND: RESET1.2, RGB1.3 (VSS), RGB2.3 (VSS), RGB3.3 (VSS), RGB4.3 (VSS), RGB5.3 (VSS), RGB6.3 (VSS), RGB7.3 (VSS), RGB8.3 (VSS), RGB9.3 (VSS), RGB10.3 (VSS), U1.3 (GND), U1.4 (GND), U1.23 (GND)
LED: RGB1.4 (DIN), U1.1 (TX0/D3)
unnamed: D1.2 (A), SW1.2
unnamed: D2.2 (A), SW2.2
unnamed: D3.2 (A), SW3.2
unnamed: D4.2 (A), SW4.2
unnamed: D5.2 (A), SW5.2
unnamed: D6.2 (A), SW6.2
unnamed: D7.2 (A), SW7.2
unnamed: D8.2 (A), SW8.2
unnamed: D9.2 (A), SW9.2
unnamed: D10.2 (A), SW10.2
unnamed: D11.2 (A), SW11.2
unnamed: D12.2 (A), SW12.2
unnamed: D13.2 (A), SW13.2
unnamed: D14.2 (A), SW14.2
unnamed: D15.2 (A), SW17.2
unnamed: D16.2 (A), SW18.2
unnamed: D17.2 (A), SW19.2
unnamed: D18.2 (A), SW20.2
unnamed: D19.2 (A), SW21.2
unnamed: D20.2 (A), SW22.2
unnamed: D21.2 (A), SW23.2
unnamed: D22.2 (A), SW15.2, SW16.2
unnamed: D23.2 (A), SW24.2
unnamed: D24.2 (A), SW25.2
unnamed: D25.2 (A), SW26.2
unnamed: D26.2 (A), SW27.2
unnamed: D27.2 (A), SW28.2
unnamed: D28.2 (A), SW29.2
unnamed: D29.2 (A), SW30.2
unnamed: D30.2 (A), SW31.2
unnamed: D31.2 (A), SW32.2
unnamed: D32.2 (A), SW33.2
unnamed: D33.2 (A), SW34.2
unnamed: D34.2 (A), SW35.2
unnamed: D35.2 (A), SW36.2
unnamed: D36.2 (A), SW37.2
unnamed: D37.2 (A), SW38.2
unnamed: D38.2 (A), SW39.2
unnamed: D39.2 (A), SW40.2
unnamed: D40.2 (A), SW41.2
unnamed: D41.2 (A), SW44.2
unnamed: D42.2 (A), SW45.2
unnamed: D43.2 (A), SW48.2
unnamed: D44.2 (A), SW42.2, SW43.2
unnamed: D45.2 (A), SW46.2, SW47.2
unnamed: D46.2 (A), SW49.2
unnamed: D47.2 (A), SW50.2
unnamed: D48.2 (A), SW51.2
unnamed: D49.2 (A), SW52.2
unnamed: D50.2 (A), SW55.2
unnamed: D51.2 (A), SW56.2
unnamed: D52.2 (A), SW57.2
unnamed: D53.2 (A), SW53.2, SW54.2
unnamed: RGB1.2 (DOUT), RGB2.4 (DIN)
unnamed: RGB2.2 (DOUT), RGB3.4 (DIN)
unnamed: RGB3.2 (DOUT), RGB4.4 (DIN)
unnamed: RGB4.2 (DOUT), RGB5.4 (DIN)
unnamed: RGB5.2 (DOUT), RGB6.4 (DIN)
unnamed: RGB6.2 (DOUT), RGB7.4 (DIN)
unnamed: RGB7.2 (DOUT), RGB8.4 (DIN)
unnamed: RGB8.2 (DOUT), RGB9.4 (DIN)
unnamed: RGB9.2 (DOUT), RGB10.4 (DIN)
VCC: RGB1.1 (VDD), RGB2.1 (VDD), RGB3.1 (VDD), RGB4.1 (VDD), RGB5.1 (VDD), RGB6.1 (VDD), RGB7.1 (VDD), RGB8.1 (VDD), RGB9.1 (VDD), RGB10.1 (VDD), U1.21 (VCC)
col0: SW7.1, SW15.1, SW16.1, SW24.1, SW32.1, SW40.1, SW49.1, U1.20 (F4/A3)
col1: SW8.1, SW17.1, SW25.1, SW33.1, SW41.1, SW50.1, U1.19 (F5/A2)
col2: SW1.1, SW9.1, SW18.1, SW26.1, SW34.1, SW42.1, SW43.1, SW51.1, U1.18 (F6/A1)
col3: SW2.1, SW10.1, SW19.1, SW27.1, SW35.1, SW44.1, SW52.1, U1.17 (F7/A0)
col4: SW3.1, SW11.1, SW20.1, SW28.1, SW36.1, SW45.1, SW53.1, SW54.1, U1.16 (B1/15)
col5: SW4.1, SW12.1, SW21.1, SW29.1, SW37.1, SW46.1, SW47.1, SW55.1, U1.15 (B3/14)
col6: SW5.1, SW13.1, SW22.1, SW30.1, SW38.1, SW48.1, SW56.1, U1.14 (B2/16)
col7: SW6.1, SW14.1, SW23.1, SW31.1, SW39.1, SW57.1, U1.13 (B6/10)
reset: RESET1.1, U1.22 (RST)
row0: D1.1 (K), D2.1 (K), D3.1 (K), D4.1 (K), D5.1 (K), D6.1 (K), U1.6 (3/D0/SCL)
row1: D7.1 (K), D8.1 (K), D9.1 (K), D10.1 (K), D11.1 (K), D12.1 (K), D13.1 (K), D14.1 (K), U1.7 (4/D4)
row2: D15.1 (K), D16.1 (K), D17.1 (K), D18.1 (K), D19.1 (K), D20.1 (K), D21.1 (K), D22.1 (K), U1.8 (5/C6)
row3: D23.1 (K), D24.1 (K), D25.1 (K), D26.1 (K), D27.1 (K), D28.1 (K), D29.1 (K), D30.1 (K), U1.9 (6/D7)
row4: D31.1 (K), D32.1 (K), D33.1 (K), D34.1 (K), D35.1 (K), D36.1 (K), D37.1 (K), D38.1 (K), U1.10 (7/E6)
row5: D39.1 (K), D40.1 (K), D41.1 (K), D42.1 (K), D43.1 (K), D44.1 (K), D45.1 (K), U1.11 (8/B4)
row6: D46.1 (K), D47.1 (K), D48.1 (K), D49.1 (K), D50.1 (K), D51.1 (K), D52.1 (K), D53.1 (K), U1.12 (9/B5)

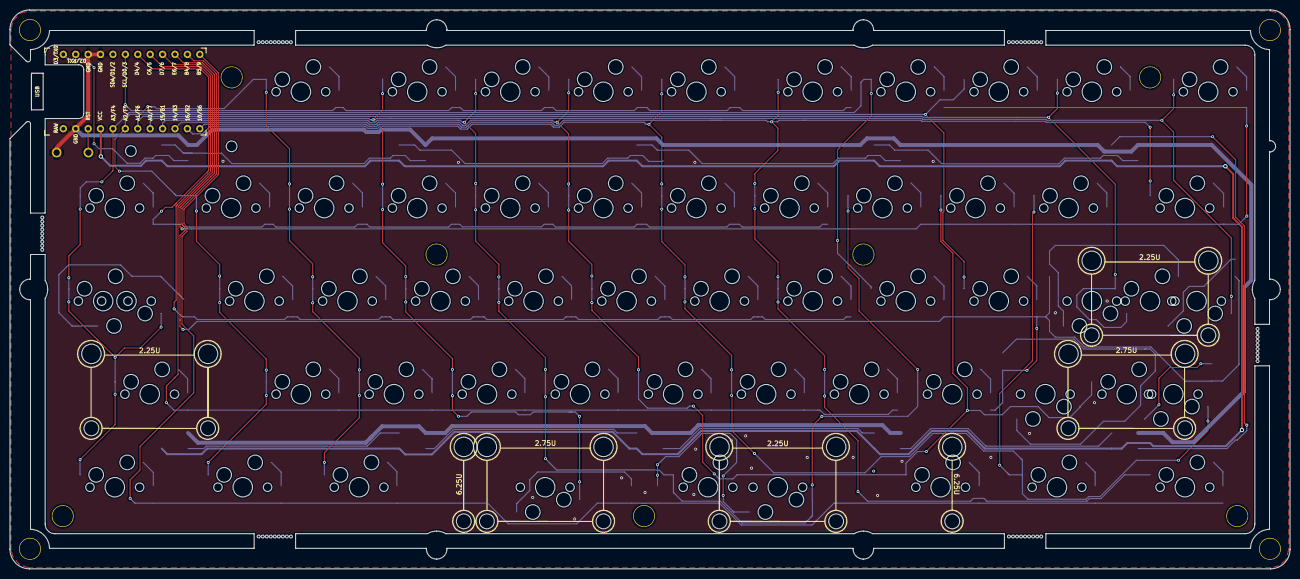
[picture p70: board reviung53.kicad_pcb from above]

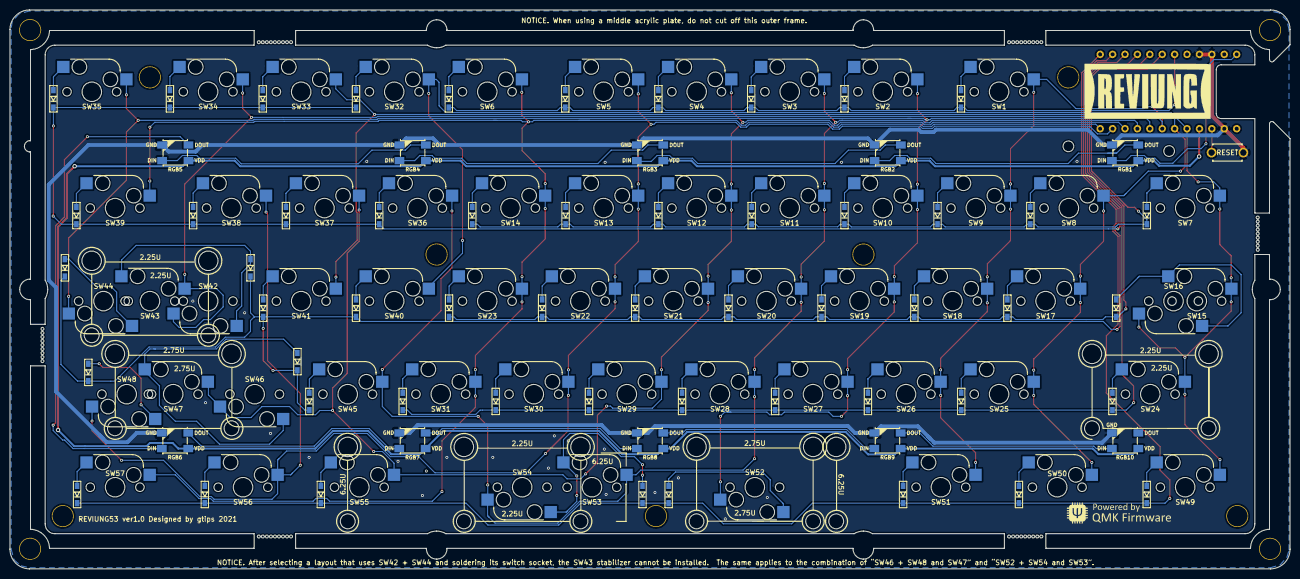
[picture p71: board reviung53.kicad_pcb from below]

Board: 2 copper layers, 262.0 x 114.4 mm, 130 parts (64 on the bottom side), 81 nets.

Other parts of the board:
Ref**: Val**; HOLE_2.2mm
Ref**#2: Val**; HOLE_2.2mm
breakaway: Stamp_Holes_7.5mm
breakaway#2, breakaway#3, breakaway#4, breakaway#5, breakaway#6: Stamp_Holes_7.5mm

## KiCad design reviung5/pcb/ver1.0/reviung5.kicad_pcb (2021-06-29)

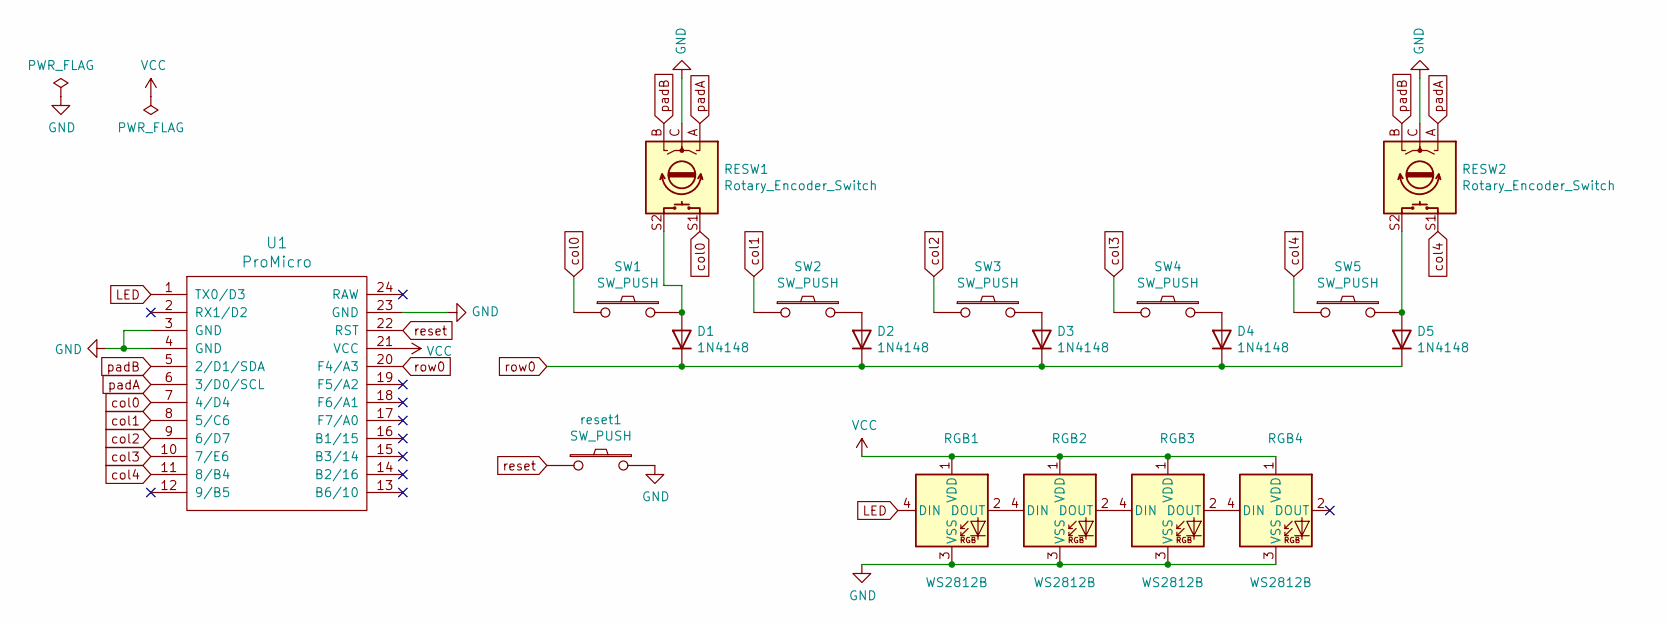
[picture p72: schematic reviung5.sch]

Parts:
D1, D2, D3, D4, D5: 1N4148; D3_TH_SMD_1side
RESW1, RESW2: Rotary_Encoder_Switch; RotaryEncoder_Alps_EC12E-Switch_Vertical_H20mm_CircularMoun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
RGB1, RGB2, RGB3, RGB4: WS2812B; LED_WS2812B_PLCC4_5.0x5.0mm_P3.2mm
SW1, SW5: SW_PUSH; MXOnly-1U-3pin
SW2, SW3, SW4: SW_PUSH; MXOnly-1U-NoLED
U1: ProMicro
reset1: SW_PUSH; ResetSW_TH_SMD

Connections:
GND: RESW1.C, RESW2.C, RGB1.3 (VSS), RGB2.3 (VSS), RGB3.3 (VSS), RGB4.3 (VSS), U1.3 (GND), U1.4 (GND), U1.23 (GND), reset1.2
LED: RGB1.4 (DIN), U1.1 (TX0/D3)
unnamed: D1.2 (A), RESW1.S2, SW1.2
unnamed: D2.2 (A), SW2.2
unnamed: D3.2 (A), SW3.2
unnamed: D4.2 (A), SW4.2
unnamed: D5.2 (A), RESW2.S2, SW5.2
unnamed: RGB1.2 (DOUT), RGB2.4 (DIN)
unnamed: RGB2.2 (DOUT), RGB3.4 (DIN)
unnamed: RGB3.2 (DOUT), RGB4.4 (DIN)
VCC: RGB1.1 (VDD), RGB2.1 (VDD), RGB3.1 (VDD), RGB4.1 (VDD), U1.21 (VCC)
col0: RESW1.S1, SW1.1, U1.7 (4/D4)
col1: SW2.1, U1.8 (5/C6)
col2: SW3.1, U1.9 (6/D7)
col3: SW4.1, U1.10 (7/E6)
col4: RESW2.S1, SW5.1, U1.11 (8/B4)
padA: RESW1.A, RESW2.A, U1.6 (3/D0/SCL)
padB: RESW1.B, RESW2.B, U1.5 (2/D1/SDA)
reset: U1.22 (RST), reset1.1
row0: D1.1 (K), D2.1 (K), D3.1 (K), D4.1 (K), D5.1 (K), U1.20 (F4/A3)

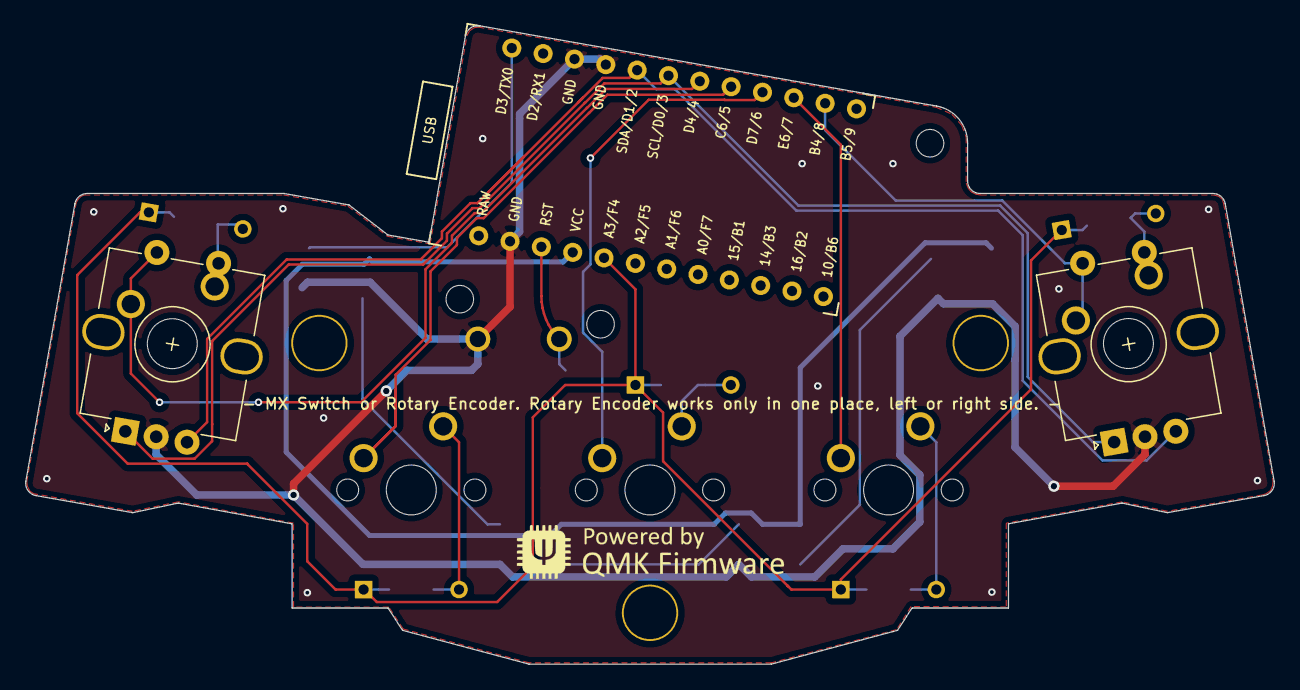
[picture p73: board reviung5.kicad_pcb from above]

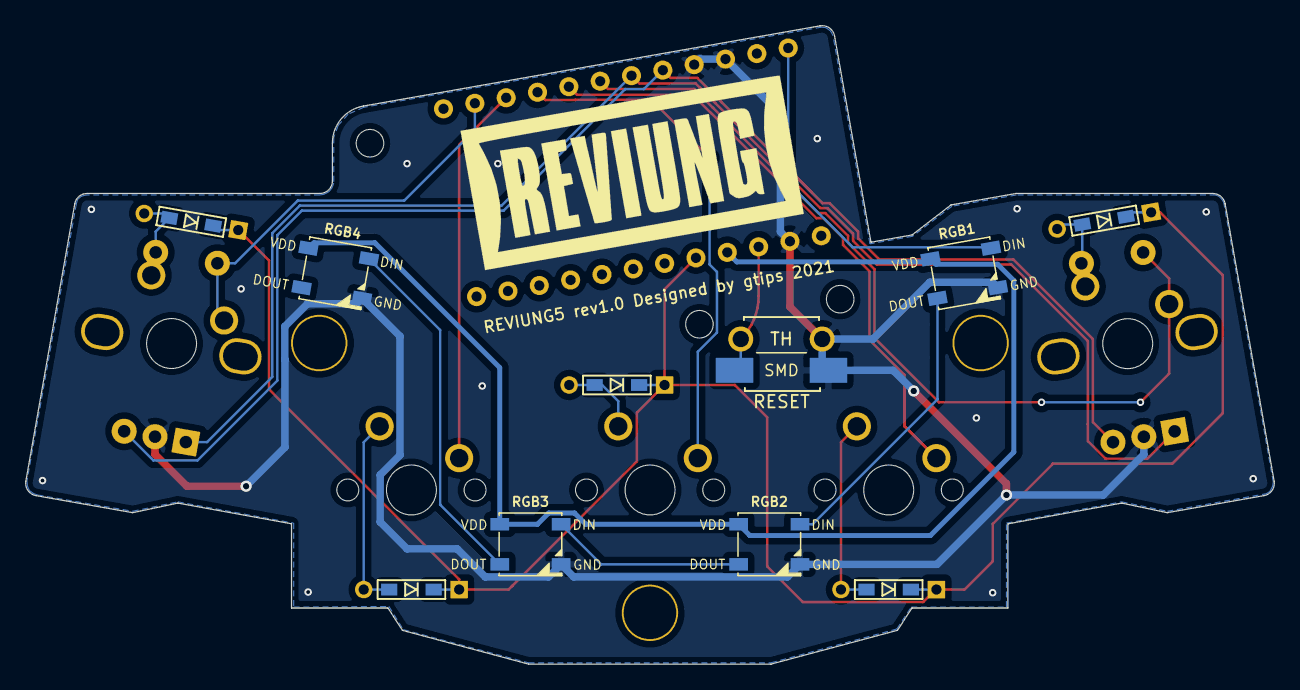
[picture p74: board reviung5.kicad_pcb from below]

Board: 2 copper layers, 99.7 x 51.0 mm, 21 parts (10 on the bottom side), 20 nets.

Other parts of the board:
Ref**: Val**; HOLE_2.2mm
Ref**#2, Ref**#3: Val**; HOLE_2.2mm

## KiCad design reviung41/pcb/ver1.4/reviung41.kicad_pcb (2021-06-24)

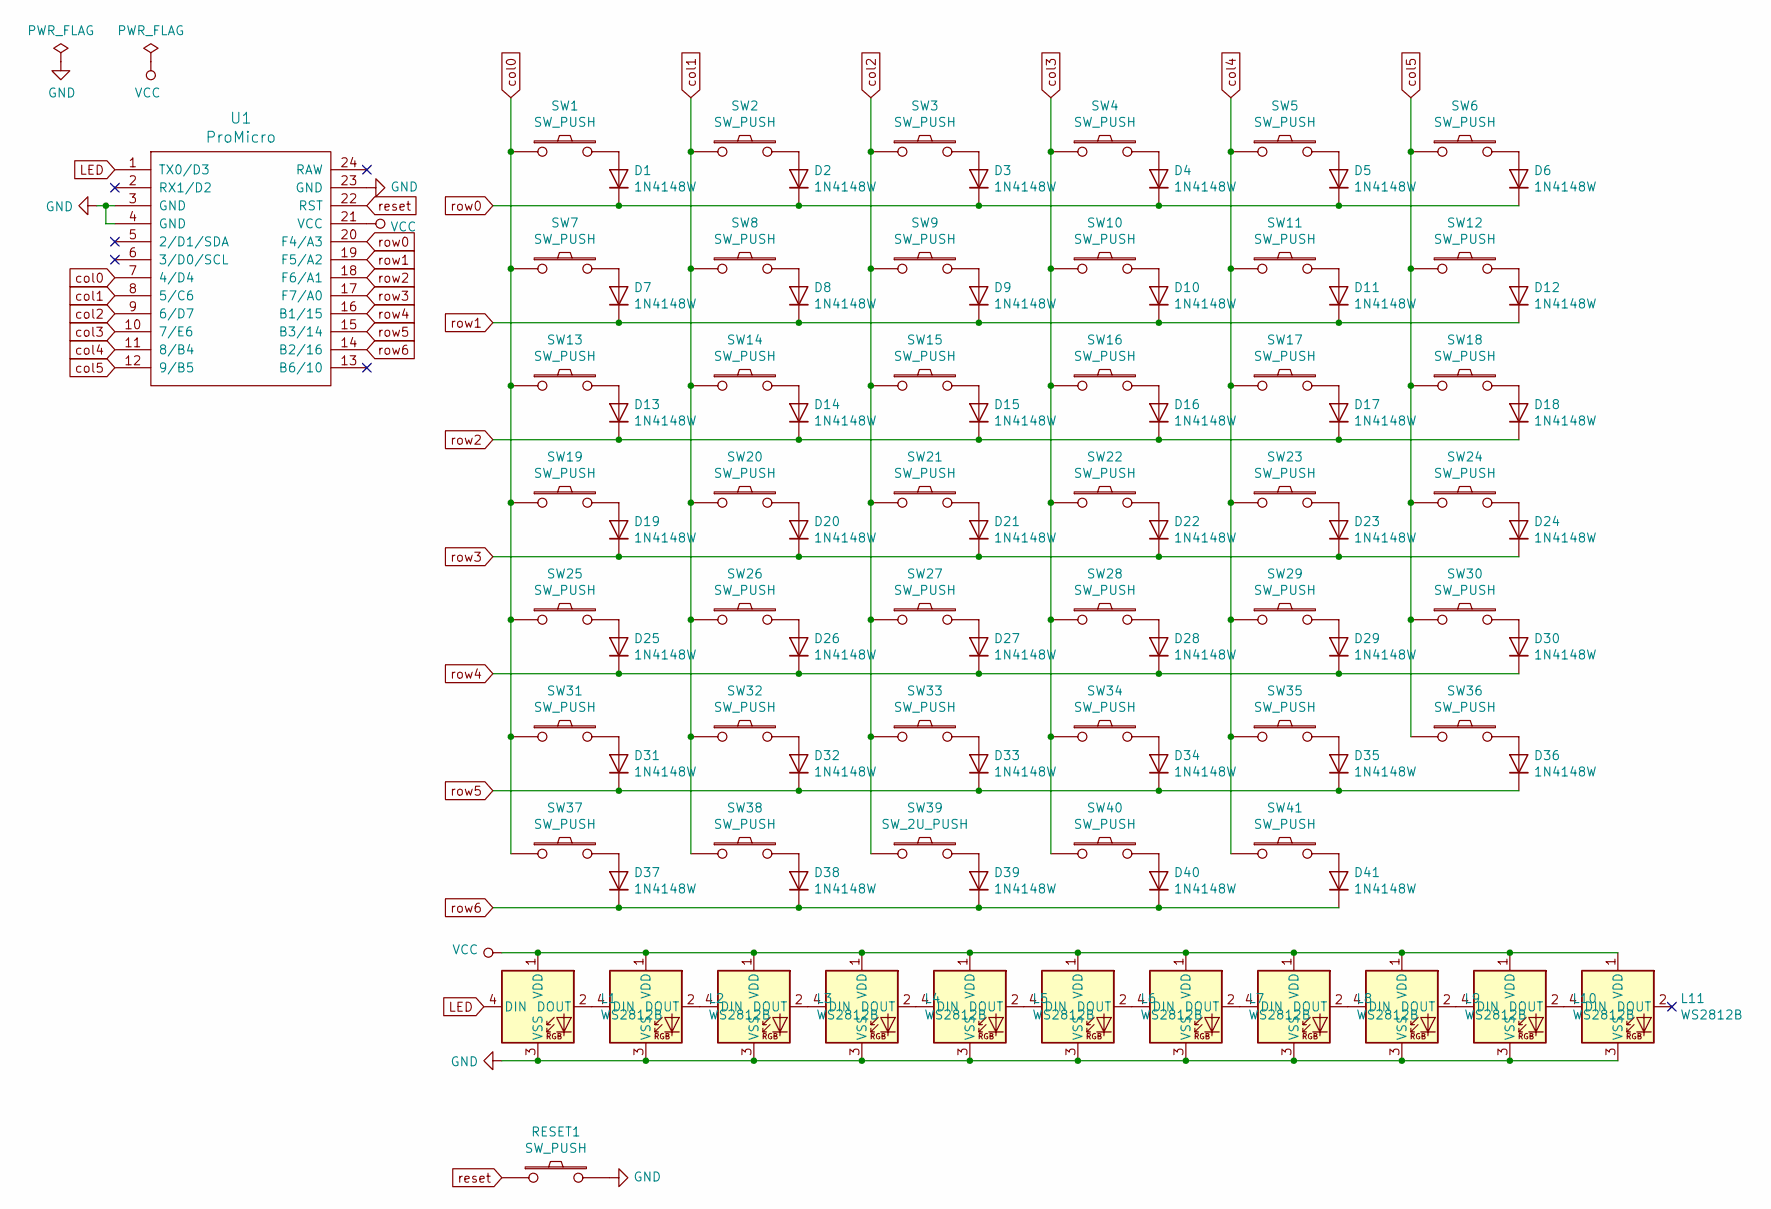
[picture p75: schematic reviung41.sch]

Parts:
D1, D2, D3, D4, D5, D6, D7, D8, D9, D10, D11, D12, D13, D14, D15, D16, D17, D18, D19, D20, D21, D22, D23, D24, D25, D26, D27, D28, D29, D30, D31, D32, D33, D34, D35, D36, D37, D38, D39, D40, D41: 1N4148W; D3_SMD_1side
L1, L2, L3, L4, L5, L6, L7, L8, L9, L10, L11: WS2812B; LED_WS2812B_PLCC4_5.0x5.0mm_P3.2mm
RESET1: SW_PUSH; ResetSW_1side
SW1, SW2, SW3, SW4, SW5, SW6, SW7, SW8, SW9, SW10, SW11, SW12, SW13, SW14, SW15, SW16, SW17, SW18, SW19, SW20, SW21, SW22, SW23, SW24, SW25, SW26, SW27, SW28, SW29, SW30, SW31, SW32, SW33, SW34, SW35, SW36, SW37, SW38, SW40, SW41: SW_PUSH; MXOnly-1U-Hotswap
SW39: SW_2U_PUSH; MXOnly-2U-Hotswap-ReversedStabilizers
U1: ProMicro

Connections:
GND: L1.3 (VSS), L2.3 (VSS), L3.3 (VSS), L4.3 (VSS), L5.3 (VSS), L6.3 (VSS), L7.3 (VSS), L8.3 (VSS), L9.3 (VSS), L10.3 (VSS), L11.3 (VSS), RESET1.2, U1.3 (GND), U1.4 (GND), U1.23 (GND)
LED: L1.4 (DIN), U1.1 (TX0/D3)
unnamed: D1.2 (A), SW1.2
unnamed: D2.2 (A), SW2.2
unnamed: D3.2 (A), SW3.2
unnamed: D4.2 (A), SW4.2
unnamed: D5.2 (A), SW5.2
unnamed: D6.2 (A), SW6.2
unnamed: D7.2 (A), SW7.2
unnamed: D8.2 (A), SW8.2
unnamed: D9.2 (A), SW9.2
unnamed: D10.2 (A), SW10.2
unnamed: D11.2 (A), SW11.2
unnamed: D12.2 (A), SW12.2
unnamed: D13.2 (A), SW13.2
unnamed: D14.2 (A), SW14.2
unnamed: D15.2 (A), SW15.2
unnamed: D16.2 (A), SW16.2
unnamed: D17.2 (A), SW17.2
unnamed: D18.2 (A), SW18.2
unnamed: D19.2 (A), SW19.2
unnamed: D20.2 (A), SW20.2
unnamed: D21.2 (A), SW21.2
unnamed: D22.2 (A), SW22.2
unnamed: D23.2 (A), SW23.2
unnamed: D24.2 (A), SW24.2
unnamed: D25.2 (A), SW25.2
unnamed: D26.2 (A), SW26.2
unnamed: D27.2 (A), SW27.2
unnamed: D28.2 (A), SW28.2
unnamed: D29.2 (A), SW29.2
unnamed: D30.2 (A), SW30.2
unnamed: D31.2 (A), SW31.2
unnamed: D32.2 (A), SW32.2
unnamed: D33.2 (A), SW33.2
unnamed: D34.2 (A), SW34.2
unnamed: D35.2 (A), SW35.2
unnamed: D36.2 (A), SW36.2
unnamed: D37.2 (A), SW37.2
unnamed: D38.2 (A), SW38.2
unnamed: D39.2 (A), SW39.2
unnamed: D40.2 (A), SW40.2
unnamed: D41.2 (A), SW41.2
unnamed: L1.2 (DOUT), L2.4 (DIN)
unnamed: L2.2 (DOUT), L3.4 (DIN)
unnamed: L3.2 (DOUT), L4.4 (DIN)
unnamed: L4.2 (DOUT), L5.4 (DIN)
unnamed: L5.2 (DOUT), L6.4 (DIN)
unnamed: L6.2 (DOUT), L7.4 (DIN)
unnamed: L7.2 (DOUT), L8.4 (DIN)
unnamed: L8.2 (DOUT), L9.4 (DIN)
unnamed: L10.2 (DOUT), L11.4 (DIN)
unnamed: L9.2 (DOUT), L10.4 (DIN)
VCC: L1.1 (VDD), L2.1 (VDD), L3.1 (VDD), L4.1 (VDD), L5.1 (VDD), L6.1 (VDD), L7.1 (VDD), L8.1 (VDD), L9.1 (VDD), L10.1 (VDD), L11.1 (VDD), U1.21 (VCC)
col0: SW1.1, SW7.1, SW13.1, SW19.1, SW25.1, SW31.1, SW37.1, U1.7 (4/D4)
col1: SW2.1, SW8.1, SW14.1, SW20.1, SW26.1, SW32.1, SW38.1, U1.8 (5/C6)
col2: SW3.1, SW9.1, SW15.1, SW21.1, SW27.1, SW33.1, SW39.1, U1.9 (6/D7)
col3: SW4.1, SW10.1, SW16.1, SW22.1, SW28.1, SW34.1, SW40.1, U1.10 (7/E6)
col4: SW5.1, SW11.1, SW17.1, SW23.1, SW29.1, SW35.1, SW41.1, U1.11 (8/B4)
col5: SW6.1, SW12.1, SW18.1, SW24.1, SW30.1, SW36.1, U1.12 (9/B5)
reset: RESET1.1, U1.22 (RST)
row0: D1.1 (K), D2.1 (K), D3.1 (K), D4.1 (K), D5.1 (K), D6.1 (K), U1.20 (F4/A3)
row1: D7.1 (K), D8.1 (K), D9.1 (K), D10.1 (K), D11.1 (K), D12.1 (K), U1.19 (F5/A2)
row2: D13.1 (K), D14.1 (K), D15.1 (K), D16.1 (K), D17.1 (K), D18.1 (K), U1.18 (F6/A1)
row3: D19.1 (K), D20.1 (K), D21.1 (K), D22.1 (K), D23.1 (K), D24.1 (K), U1.17 (F7/A0)
row4: D25.1 (K), D26.1 (K), D27.1 (K), D28.1 (K), D29.1 (K), D30.1 (K), U1.16 (B1/15)
row5: D31.1 (K), D32.1 (K), D33.1 (K), D34.1 (K), D35.1 (K), D36.1 (K), U1.15 (B3/14)
row6: D37.1 (K), D38.1 (K), D39.1 (K), D40.1 (K), D41.1 (K), U1.14 (B2/16)

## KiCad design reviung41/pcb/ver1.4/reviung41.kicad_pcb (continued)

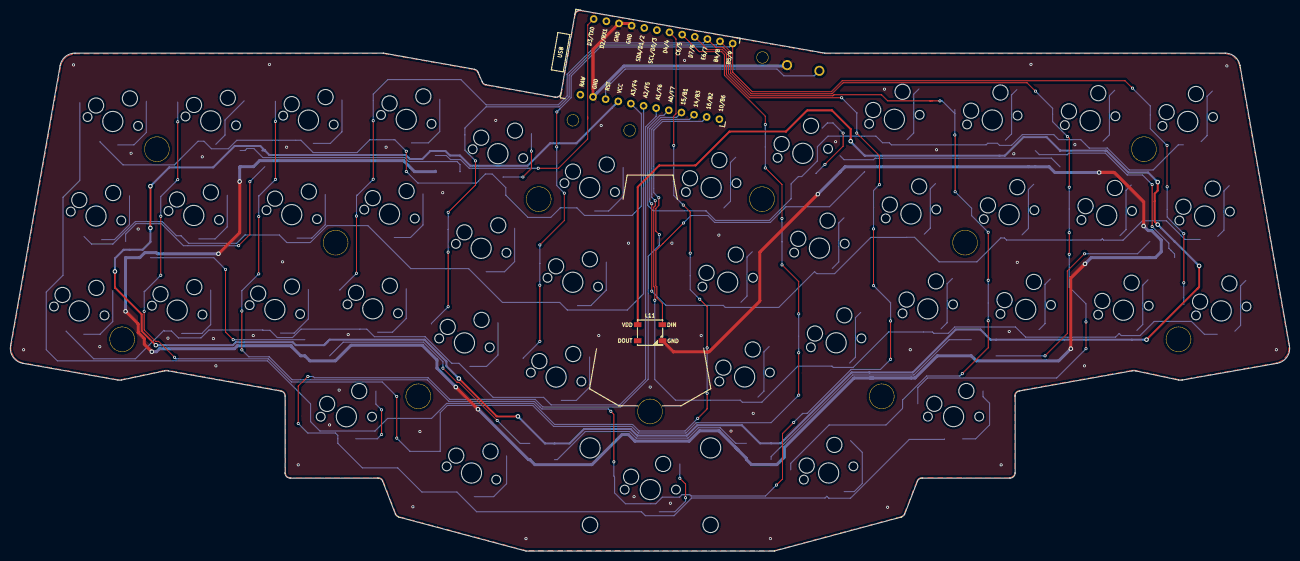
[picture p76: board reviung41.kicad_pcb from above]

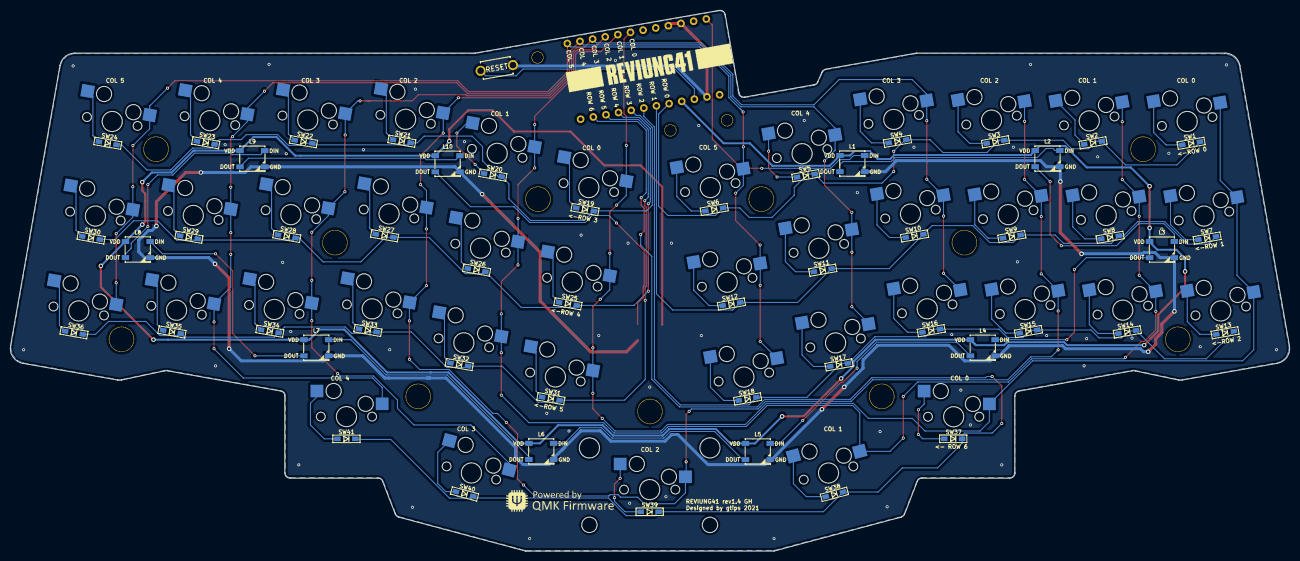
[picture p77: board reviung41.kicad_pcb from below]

Board: 2 copper layers, 253.3 x 107.1 mm, 109 parts (52 on the bottom side), 68 nets.

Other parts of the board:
H1: H1; HOLE
H2: H2; HOLE
H3: H3; HOLE
H4: H4; HOLE
H5: H5; HOLE
H6: H6; HOLE
H7: H7; HOLE
H8: H8; HOLE
H9: H9; HOLE
H10: H10; HOLE
H11: H11; HOLE
H12: H12; HOLE_2.2mm
H13: H13; HOLE_2.2mm
H14: H14; HOLE_2.2mm

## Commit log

2019-07-12 add: pcb
    [reviung39.kicad_pcb, reviung39.sch]
2019-08-27 add pcb, svg and image
    [reviung39-top-plate.kicad_pcb, reviung39-top-plate.sch, reviung39.kicad_pcb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]
2019-09-12 update pcb ver1.1
    [reviung39.kicad_pcb, reviung39.sch, reviung39s.kicad_pcb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]
2019-09-25 add reviung39/pcb-top-plate/gerber.zip
2019-09-25 add reviung34split
    [reviung34-split-BOTTOM.kicad_pcb, reviung34-split-BOTTOM.sch, reviung34-split-L-TOP.kicad_pcb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]
2019-11-12 update reviung34split pcb file
    [reviung34-split-BOTTOM.kicad_pcb, reviung34-split-L-TOP.kicad_pcb, reviung34-split-R.kicad_pcb]
2019-12-05 add reviung39/acrylic-plate/ and reviung39s/acrylic-plate/
2019-12-12 add reviung39/acrylic-plate/lower-middle-plate/README.md
2019-12-14 add reviung39/acrylic-plate.zip
2020-01-06 add reviung41
    [pcb-top-plate.kicad_pcb, pcb-top-plate.sch, reviung41.kicad_pcb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]
2020-01-21 update reviung41/acrylic-plate/upper-middle-plate/reviung41-upper-middle-plate
2020-07-16 add reviung61
    [reviung61-B_Cu.gbr, reviung61-B_Mask.gbr, reviung61-B_SilkS.gbr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]
2020-07-16 update reviung61/pcb-top-plate-ALPS/
    [reviung61-top-plate-B_Cu.gbr, reviung61-top-plate-B_Mask.gbr, reviung61-top-plate-B_SilkS.gbr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]
2020-08-25 add reviung33
    [reviung33-B_Cu.gbr, reviung33-B_Mask.gbr, reviung33-B_SilkS.gbr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]
2020-08-25 update reviung/acrylic-plate/
2020-08-27 add reviung39Mk-II
    [pcb-top-plate-B_Cu.gbr, pcb-top-plate-B_Mask.gbr, pcb-top-plate-B_SilkS.gbr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]
2020-11-13 add REVIUNG34 Mk-II
    [reviung34-split-BOTTOM-B_Cu.gbl, reviung34-split-BOTTOM-B_Mask.gbs, reviung34-split-BOTTOM-B_SilkS.gbo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]
2021-01-05 Adding 3d model and stl for reviung39Mkii case
    [Reviung39mkii-case.step, Reviung39mkii-case.stl]
2021-04-19 add reviung41 top and bottom plate files
    [reviung41-bottom-plate.dxf, reviung41-top-plate.dxf]
2021-04-19 add reviung41 top plate dwg file
    [reviung41-top-plate.dwg]
2021-04-25 add new reviung34
    [Reviung39mkii-case.step, Reviung39mkii-case.stl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]
2021-04-25 add gerver_r34_v1.zip
    [pcb-top-plate-rev1-B_Cu.GBL, pcb-top-plate-rev1-B_Mask.GBS, pcb-top-plate-rev1-B_SilkS.GBO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]
2021-04-26 add reviung34/acrylic-plate/bottom-plate/reviung34-bottom-plate-2mm-ver1.dxf
    [reviung34-bottom-plate-2mm-ver1.dxf]
2021-05-25 update reviung39_Mk-II/acrylic-plate/
2021-05-25 update reviung34/acrylic-plate/
    [r34-lower-middle-3mm-ver1.1-TP.dxf, r34-upper-middle-3mm-ver1.1-OP.dxf, r34-upper-middle-3mm-ver1.1-TP.dxf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]
2021-05-25 update reviung41/acrylic-plate/
    [reviung41-bottom-plate-ver1.1.dxf, reviung41-bottom-plate.dxf]
2021-05-25 update reviung41/pcb/ver1.3 and reviung41/pcb-top-plate/ver1.3/
    [pcb-top-plate-B_Cu.gbl, pcb-top-plate-B_Mask.gbs, pcb-top-plate-B_SilkS.gbo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]
2021-06-24 update reviung41 ver1.4
    [pcb-top-plate.kicad_pcb, pcb-top-plate.sch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]
2021-12-02 add: reviung53/
    [reviung53-B_Cu.GBL, reviung53-B_Cu.gbl, reviung53-B_Mask.GBS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]
2021-12-03 add: reviung53/acrylic-plate/mcu-cover-ver1.0/
2021-12-06 add: reviung53/acrylic-plate/for-middle-plate/, /for-stacked-acrylic-case/
    [reviung53_2mm_450x300_ver1.0.dxf, reviung53_3mm_450x300_ver1.0.dxf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]
2021-12-08 renamed folder name
    [slim_bottom_plate-B_Cu.GBL, slim_bottom_plate-B_Cu.gbl, slim_bottom_plate-B_Mask.GBS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]
2022-01-20 add reviung53/acrylic-plate/for-stacked-acrylic-case/Assembly_drawing.jpg
    [reviung53_2mm_450x300_ver1.1.dxf]
2022-01-20 Fixed for-middle-plate directory name
    [reviung53_3mm_450x300_ver1.0.dxf]
2024-08-20 add new file
    [R46_TopPlate-B_Cu.gbl, R46_TopPlate-B_Mask.gbs, R46_TopPlate-B_Paste.gbp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]
